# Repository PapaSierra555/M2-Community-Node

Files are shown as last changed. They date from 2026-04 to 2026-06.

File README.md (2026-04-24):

# M2 Community Node

Field-portable communications node in an 8U 10" mini-rack. Dual Raspberry Pi 5 16GB. All hardware, all open source, all yours.

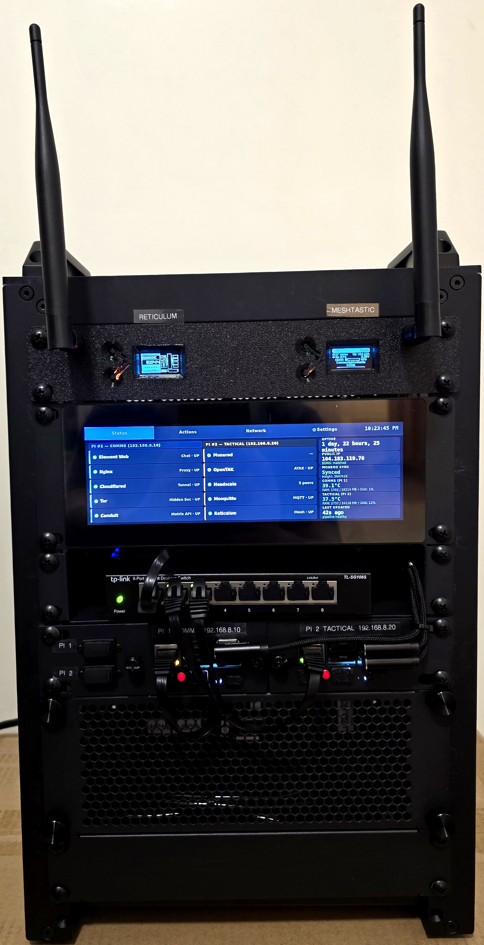
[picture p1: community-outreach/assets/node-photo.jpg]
M2 Community Node


**License:** [CC BY-NC-SA 4.0](LICENSE) — free to use, adapt, and share non-commercially with attribution.

**Network diagram:** [`docs/M2_Network_Diagram.drawio`](docs/M2_Network_Diagram.drawio) — renders on GitHub · open in [app.diagrams.net](https://app.diagrams.net) to edit or print

---

> ## Before You Start — Read This
>
> **This repository is a build plan, not a plug-and-play installer.** It is a complete, step-by-step blueprint for constructing and configuring a field-portable community communications node from commodity hardware. Prior hardware or networking expertise is NOT a hard requirement — but only if you go in with realistic expectations and the right support.
>
> **This node was built successfully with the help of an AI companion (Claude) assisting at every step** — walking through commands, catching configuration errors, explaining tradeoffs, and adapting to the specific hardware and environment as it came up. That approach is **strongly recommended** for anyone attempting this build. The build guide contains every command and every config, but this is a complex, multi-service system and the reality of standing it up involves:
>
> - Configuration decisions that depend on your specific domain, hardware, and use case
> - Gotchas in third-party software (OpenTAKServer, Conduit, Headscale) that are not documented upstream
> - Network and firewall behaviors that vary by router model and ISP
> - Security choices around access tiers, credentials, and certificate management that require deliberate decisions
> - Unexpected states during setup that require diagnosis, not just copy-paste
>
> **The recommendation:** Work through the build guide with an AI assistant — Claude, ChatGPT, or similar — that can read the docs alongside you, adapt commands to your environment on the fly, and help you reason through the decisions. This is not a project where you follow the guide blindly and expect it to work. It is a project where you follow the guide with a knowledgeable collaborator and build something that actually fits your community.
>
---

## What It Does

A self-contained tactical and community communications hub that fits in a shoebox-sized rack and deploys in under 15 minutes:

- **ATAK / OpenTAK Server** — shared tactical map, CoT, GeoChat, voice (Mumble)
- **Matrix / Element** — encrypted group chat with federation
- **Meshtastic** — LoRa mesh radio (1–5 km, no internet needed)
- **Reticulum / RNode** — encrypted mesh transport backbone
- **Monero** — community privacy node
- **Tor + I2P** — censorship-resistant access paths
- **Headscale** — self-hosted VPN for remote operator access
- **Offline Maps** — PMTiles street-level maps + DTED2 terrain data

**Cost:** ~$994 (recommended build) | ~$889 (budget, single Pi) | [See all build options →](docs/BUILD_OPTIONS.md)

---

## Repository Layout

```
M2-Community-Node/
├── docs/               ← EVERYTHING YOU NEED TO BUILD IS IN HERE (including network diagram)
├── operational-pdfs/   Print-ready operational documents (build guide, runbook, field cards)
├── community-outreach/ Community marketing package (booth handouts, recruiting materials)
├── scripts/            PDF generators, QR tools, status bot, deploy scripts
├── config/             Service config templates (Conduit, Nginx, Tor, I2P, etc.)
├── svg/                Generic QR code SVGs (app downloads, LAN Element)
├── 3d-models/          STL files for 3D-printed rack accessories
├── kiosk-assets/       Offline map libraries for the kiosk display
├── docker-compose.yml          Pi #1 (comms) service stack
└── docker-compose.tactical.yml Pi #2 (tactical) service stack
```

---

> **The `docs/` folder is the build.** Every phase, every command, every config decision lives there. The hardware BOM, the step-by-step build guide, the event runbook, troubleshooting — all of it. If you are building a node, open `docs/` and start with `PREREQUISITES.md`. Do not skip it.

---

### docs/

All reference documentation. Read in this order if you're building:

| Document | What it covers |
|---|---|
| [PREREQUISITES.md](docs/PREREQUISITES.md) | What you need before you start |
| [HARDWARE_BOM.md](docs/HARDWARE_BOM.md) | Complete BOM — every part, ASIN, and price |
| [BUILD_OPTIONS.md](docs/BUILD_OPTIONS.md) | Hardware alternatives — Pi 4, mini PCs, single-device, no-Monero builds |
| [MASTER_PLAN.md](docs/MASTER_PLAN.md) | Architecture, service inventory, network layout |
| [M2_Network_Diagram.drawio](docs/M2_Network_Diagram.drawio) | Full network diagram — all services, ports, connectivity paths |
| [BUILD_GUIDE.md](docs/BUILD_GUIDE.md) | **Main build guide — 13 phases, every command** |
| [ATAK_CONNECTIVITY.md](docs/ATAK_CONNECTIVITY.md) | Operator onboarding — 3 access tiers (LAN, clearnet, VPN) |
| [EVENT_RUNBOOK.md](docs/EVENT_RUNBOOK.md) | Day-of-event: power-on, POST, onboarding, teardown |
| [ATAK_SAR_PLUGINS.md](docs/ATAK_SAR_PLUGINS.md) | ATAK plugin audit and SAR recommendations |
| [ATAK_RETICULUM_MESH.md](docs/ATAK_RETICULUM_MESH.md) | Mesh layer deep dive (OTS + Reticulum + Meshtastic) |
| [ELEMENT_PLAN.md](docs/ELEMENT_PLAN.md) | Matrix / Element space planning and federation |
| [MONERO_NODE.md](docs/MONERO_NODE.md) | Monero node installation and operation |
| [SERVICE_MAP.md](docs/SERVICE_MAP.md) | Port map and network layout quick reference |
| [TROUBLESHOOTING.md](docs/TROUBLESHOOTING.md) | Symptom-based field reference — WiFi, ATAK, Matrix, Monero |
| [NETWORK_CUSTOMIZATION.md](docs/NETWORK_CUSTOMIZATION.md) | Changing subnets, DHCP, and firewall rules |
| [CLOUDFLARE_SETUP.md](docs/CLOUDFLARE_SETUP.md) | DNS and tunnel setup for clearnet access |
| [DISASTER_RECOVERY.md](docs/DISASTER_RECOVERY.md) | Backup, restore, and failover procedures |
| [QR_CODES.md](docs/QR_CODES.md) | QR code generation and deployment workflow |
| [FIELD_LAPTOP_SETUP.md](docs/FIELD_LAPTOP_SETUP.md) | Operator laptop config for remote field use |
| [MAINTENANCE.md](docs/MAINTENANCE.md) | Service updates, version management, credential rotation |

### operational-pdfs/

Print-ready documents for building and operating the node. Generated from the source docs — regenerate after any doc change by running the corresponding script from `scripts/`.

| PDF | Description | Regenerate with |
|---|---|---|
| `M2_Community_Node_Build_Book.pdf` | Full build guide — print for the workbench | `generate_build_book.py` |
| `M2_Community_Node_Runbook.pdf` | Event operations runbook | `generate_runbook.py` |
| `M2_Community_Node_Troubleshooting.pdf` | Field troubleshooting reference | `generate_reference_pdfs.py` |
| `M2_Rack_Wiring_Diagram.pdf` | Cable routing and power chain diagrams | `generate_m2_wiring_diagram.py` |
| `M2_ATAK_FieldCard.pdf` | 3.5×5.5" laminated ATAK setup card | `generate_field_card.py` |

### community-outreach/

Marketing and recruiting materials for events and community engagement. These are not build documentation — they are handouts for people who haven't built a node yet. Live in `community-outreach/pdf/`, generated by scripts in `community-outreach/scripts/`.

| PDF | Description |
|---|---|
| `M2_Snapshot.pdf` | 2-page booth handout — services, capabilities, cost |
| `M2_Build_Summary.pdf` | BOM summary, cost tiers, build timeline |
| `M2_PACE_Card.pdf` | PACE framework reference card |
| `M2_New_Member_Card.pdf` | 3.5×5.5" laminated new member onboarding card |

### scripts/

PDF generators, operations tools, and deploy scripts.

| Script | What it does |
|---|---|
| `generate_build_book.py` | Build Book PDF from `docs/BUILD_GUIDE.md` |
| `generate_runbook.py` | Runbook PDF from `docs/EVENT_RUNBOOK.md` |
| `generate_reference_pdfs.py` | Troubleshooting PDF from `docs/TROUBLESHOOTING.md` |
| `generate_m2_wiring_diagram.py` | Rack wiring diagram PDF |
| `generate_field_card.py` | ATAK field card PDF (3.5×5.5") |
| `generate_qr.py` | QR code SVGs — WiFi, app downloads, onion services |
| `generate_vinyl_labels.py` | Vinyl cut labels for rack panels |
| `generate-status.py` | Live service status page renderer |
| `m2-status-bot.sh` | Status bot launcher (systemd timer, posts to Matrix) |
| `m2-post-matrix.py` | Post a message to a Matrix room |
| `m2-event-space.py` | Manage Matrix event spaces for activations |
| `make_atak_dp.py` | Build an ATAK data package for quick enrollment |
| `push_node_marker.py` | Push node GPS marker to OpenTAK Server |
| `set_node_icon.py` | Set the node icon in OpenTAK Server |
| `instance_config.py` | Instance config loader (reads `instance.conf`) |
| `systemd/` | Systemd service and timer units for the status bot |

### config/

Service configuration templates. Copy each to its final location on the Pi before deploying — do not fill in secrets here.

| Path | Service |
|---|---|
| `config/conduit/conduit.template.toml` | Conduit Matrix homeserver |
| `config/element/element-config.json` | Element Web client |
| `config/nginx/nginx.conf` | Reverse proxy |
| `config/tor/torrc` | Tor daemon |
| `config/i2pd/i2pd.conf` | I2P daemon |
| `config/mosquitto/mosquitto.conf` | MQTT broker (Meshtastic bridge) |

### svg/

QR code SVGs for printed materials and kiosk modals. Two workflows — see [docs/QR_CODES.md](docs/QR_CODES.md).

- `qr-wifi.svg`, `qr-atak-connect.svg`, `qr-community-page.svg`, `qr-element-clearnet.svg` — physical panel vinyl cutouts
- Remaining QRs — kiosk modal use only
- `WebQrCodes/` — vinyl-quality QR set (generated via mini-qr)

### 3d-models/

STL files for 3D-printed rack accessories. Print in PETG or ABS.

- SMA bulkhead / Keystone mount for 1U panel (left + right versions)
- 2U fan side plates
- Heltec V3 LoRa radio faceplate
- RFID module housing (top + bottom)
- Meshtastic 10" rack panel model

---

## Quick Start

**Everything below points into `docs/`. That folder is where the build lives.**

### 1. Get the hardware

[docs/HARDWARE_BOM.md](docs/HARDWARE_BOM.md) — complete parts list with prices and purchase links.

### 2. Read the prerequisites

[docs/PREREQUISITES.md](docs/PREREQUISITES.md) — accounts, tools, and decisions to make before touching hardware. Do this first.

### 3. Follow the build guide

[docs/BUILD_GUIDE.md](docs/BUILD_GUIDE.md) — every command, every config, from bare hardware to a running node. This is the primary document.

### 4. Set up credentials

Copy `M2_SECRETS.template.md` to `M2_SECRETS.md` and fill in your values. The filled file is gitignored — never commit it.

Copy `instance.conf.template` to `instance.conf` and fill in your network-specific values.

Copy `kiosk-config.js.template` to `kiosk-config.js` and fill in your OTS credentials before deploying the kiosk.

### 5. Deploy the kiosk

Copy `kiosk.html`, `index.html`, `kiosk-map.html`, `kiosk-assets/`, and your filled `kiosk-config.js` to `/home/pi/node-ui/` on Pi #1.

---

## Contributing

This project is documentation and tooling, not application code. If you build one and find errors, improvements, or gotchas — open an issue or PR. All contributions must be compatible with CC BY-NC-SA 4.0.

Questions or feedback: open an issue on GitHub.

---

## Special Thanks

This project would not exist without the vision, community, and mission of three organizations that helped build the idea, necessity, and reasoning behind it:

- **[Carolina Capabilities Co-Op](https://www.carolinacapabilitiesco-op.com/)** — community resilience and preparedness, built from the ground up
- **[Light Fighter Manifesto](https://lightfightermanifesto.org/)** — the framework and philosophy driving the mission
- **[Light Fighter Homefront Initiative](https://lightfighterhomefront.org/)** — putting that mission into practice at the community level

The inspiration and architecture for this project couldn't have been done without the first iteration built by **Christopher M. Rance**. Go support the group or join a chapter — [instagram.com/christopher_m_rance](https://www.instagram.com/christopher_m_rance/)

---

## License

[Creative Commons Attribution-NonCommercial-ShareAlike 4.0 International](LICENSE)

You can build one for your community. You cannot sell it. If you publish your own version, use the same license.

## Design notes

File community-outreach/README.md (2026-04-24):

# M2 Community Node — Outreach Materials

Print-ready materials for introducing the M2 Community Node at events, chapter meetings, and mutual aid gatherings. All materials are CC BY-NC-SA 4.0.

---

## Documents

| File | Format | Purpose |
|---|---|---|
| `M2_Snapshot.pdf` | US Letter, 2 pages | Node overview — services, capabilities, hardware specs, deployment scenarios |
| `M2_PACE_Card.pdf` | US Letter, 1 page | PACE framework reference — which M2 service maps to each comms tier |
| `M2_Build_Summary.pdf` | US Letter, 1 page | Build cost tiers, BOM summary, skills required |
| `M2_New_Member_Card.pdf` | 3.5×5.5 in, 2 sides | Laminated onboarding card — WiFi credentials, connection methods, quick reference |

---

## Regenerating PDFs

All PDFs are generated from Python scripts in `scripts/`. Requirements: `reportlab`, `qrcode`.

```
pip install reportlab qrcode[pil]
```

Run all:
```
cd community-outreach/scripts
python generate_m2_snapshot.py
python generate_pace_card.py
python generate_build_summary.py
python generate_new_member_card.py
```

Output lands in `community-outreach/pdf/`.

---

## Assets

Photos and logos used by the generation scripts are in `assets/`:

| File | Use |
|---|---|
| `node-photo.jpg` | Hero shot — used in README and outreach materials |
| `node-ccc.jpg`, `node-detail-1.jpg`, `node-detail-2.jpg`, `node-side.jpg`, `node-top.jpg` | Detail photos for snapshot and summary |
| `lfhi-logo.png` | LFHI partner badge |

---

## Target Audience

**Primary:** Community preparedness groups, SAR teams, neighborhood mutual aid, and emergency response organizations evaluating off-grid comms on the PACE framework.

**Secondary:** Builders evaluating whether the M2 platform fits their technical capability and budget.

---

## Printing Notes

- `M2_New_Member_Card.pdf` — print duplex on card stock (3.5×5.5 in), laminate. Fits standard business card holders. Hand out at events.
- All other docs — US Letter, single-sided. Print in color for maximum impact.
- For vinyl panel labels and QR cutouts, see `svg/` directory and `docs/QR_CODES.md`.

---

*CC BY-NC-SA 4.0*

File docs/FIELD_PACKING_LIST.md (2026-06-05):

# M2 Community Node — Field Maintenance & Repair Kit

What to bring for field deployment. Covers the full node stack: rack,
Meshtastic fleet, field laptop, and repair/recovery gear.

---

## Node Rack — Deploy Checklist

- [ ] Comms Pi (192.168.8.10) — verify label
- [ ] Tactical Pi (192.168.8.20) — verify label
- [ ] Router
- [ ] NVMe drive — seated in tactical Pi, verify before pack
- [ ] Kiosk display + mount hardware
- [ ] Micro-HDMI to HDMI cable (comms Pi 5 → display) — braided, not flat
- [ ] Rack enclosure / case / carry bag

---

## Power

- [ ] Pi power supply x2 (labeled, one per Pi)
- [ ] Router power supply
- [ ] Display power supply / adapter
- [ ] Power strip (4+ outlets)
- [ ] Extension cord
- [ ] **SPARE: Pi power supply x1** — most common single-point failure

---

## Network

- [ ] Router WAN uplink — hotspot or ethernet
- [ ] Ethernet patch cables x4 (Pi #1, Pi #2, laptop, spare)
- [ ] **SPARE: Ethernet cable x2**

---

## Meshtastic Fleet

- [ ] T114 x8 — MESH 01–08 (verify labels)
- [ ] T3S3 x3 — PS-01, PS-02, PS-03
- [ ] USB-C charging cables x4
- [ ] USB serial cable — T114 (for re-flash / reconfigure)
- [ ] USB serial cable — T3S3 (for re-flash / reconfigure)
- [ ] Power bank x1

---

## Field Laptop

- [ ] Getac S400 G2 + power supply
- [ ] SSH access to both Pis confirmed before departure

---

## Print Materials

- [ ] Element join cards (cut + laminated)
- [ ] Meshtastic channel QR cards (cut + laminated)
- [ ] Meshtastic device cards front + back (cut + laminated, duplex)
- [ ] **SPARE: 2 extra sets of each** — cards walk, get wet, get lost

---

## Tools

- [ ] Small Phillips screwdriver
- [ ] Small flathead screwdriver
- [ ] Needle-nose pliers
- [ ] Multimeter (power supply and cable fault diagnosis)
- [ ] USB hub (run serial + keyboard simultaneously on one Pi port)
- [ ] Zip ties x20
- [ ] Velcro straps x6
- [ ] Electrical tape
- [ ] Masking tape + marker (relabeling, field notes)

---

## Spare Parts / Recovery

| Part | Failure it covers |
|---|---|
| Spare Pi x1 (either model) | Dead Pi — reimage and reconfigure as either stack |
| Spare microSD x2 (Pi OS imaged, 32GB+) | Corrupted OS — swap and restore |
| USB microSD reader | Writing replacement SD on the field laptop |
| Spare USB-C cable x2 | Charging failure for Meshtastic devices |
| Spare ethernet cable x2 | Cable fault, wrong length |
| Spare Pi power supply x1 | Pi won't boot — PSU is first suspect |

---

## Recovery Procedures (quick reference)

**Pi won't boot → swap SD card:**
1. Pull SD, insert spare (pre-imaged)
2. Boot into new OS, restore from backup or re-run setup
3. Repo + configs on field laptop: `~/SOURCE CONTROL/M2-Community-Node`

**Pi fully dead → hot-swap spare:**
1. Label spare with correct Pi number before inserting
2. Connect to LAN, SSH in, restore from repo
3. Comms stack: `sudo docker compose -f /opt/community-node/docker-compose.yml --profile clearnet up -d`
4. Tactical stack: `sudo docker compose -f /opt/tactical-node/docker-compose.yml up -d`
5. Headscale + OTS: `sudo systemctl start headscale opentakserver`

**Meshtastic device won't connect → reconfigure via serial:**
```
python3 meshtastic/scripts/config_ccc_t114.py   # T114 devices
python3 meshtastic/scripts/config_ccc_t3s3.py   # T3S3 devices
```
Run from project root on field laptop. Plug device via USB serial first.

**Dashboard shows red after boot → wait 2 minutes then check:**
```
ssh ps@192.168.8.10 "sudo docker ps --format 'table {{.Names}}\t{{.Status}}'"
ssh ps@192.168.8.20 "sudo systemctl is-active headscale && sudo systemctl is-active opentakserver"
```
Full boot verification: `docs/POWER_CYCLE.md`

**Mosquitto crash-looping:**
```
ssh ps@192.168.8.20 "sudo docker restart tactical-node-mosquitto-1"
```
If it keeps looping: check `/opt/tactical-node/config/mosquitto/mosquitto.conf` — must have `allow_anonymous true`, no `password_file` line.

---

*Full power cycle procedure: `docs/POWER_CYCLE.md`*
*Credentials: M2_SECRETS.md on field laptop (pull from Obsidian z_Backups/ before departure)*

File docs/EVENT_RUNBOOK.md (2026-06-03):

# M2 Community Node — Day-of-Event Runbook

**For the tech running the node at a SAR operation, community event, or training exercise.**

This document assumes the node has already been built and configured per `BUILD_GUIDE.md`. You do not need to read the build guide to use this runbook.

---

## Power-On Sequence

Order matters. Power on in this sequence:

1. **UPS** (BC600R) — press power button, confirm LED is green
2. **GL.iNet router** (AXT1800) — power on, wait **60 seconds** before touching anything
3. **TL-SG105 switches** — power on (no boot time)
4. **Pi #1 (comms, 192.168.8.10)** — power on
5. **Pi #2 (tactical, 192.168.8.20)** — power on
6. Wait **90 seconds** for both Pis to fully boot and services to start
7. **Kiosk touchscreen** — power on last

**Total boot time: ~3 minutes.** Do not test connectivity during this window.

---

## POST — Power-On Self-Test

After the 90-second boot window, run this check from any device on the `NodeAdmin` WiFi:

### Quick check (30 seconds)

Open a browser and hit these URLs. All should load:

| URL | Expected | Service |
|---|---|---|
| `http://192.168.8.1` | GL.iNet admin panel | Router |
| `http://192.168.8.10:8081` | Community info page | Kiosk web |
| `http://192.168.8.10:8080` | Element Web login | Matrix chat |
| `http://192.168.8.20:8080` | OTS web map | OpenTAK Server |

If all four load: **node is go.**

### Full POST (SSH, 2 minutes)

Run this on your laptop if the quick check fails or you want full confidence:

```
[SSH — comms-lan]
docker ps --format "table {{.Names}}\t{{.Status}}"
```

Expected output (all containers `Up`):
```
community-node-nginx-1         Up X hours
community-node-cloudflared-1   Up X hours
community-node-element-web-1   Up X hours (healthy)
community-node-tor-1           Up X hours (healthy)
community-node-i2pd-1          Up X hours
community-node-conduit-1       Up X hours
```

```
[SSH — tactical-lan]
systemctl is-active opentakserver cot_parser headscale && docker ps --format "table {{.Names}}\t{{.Status}}"
```

Expected: `active` (three times), then containers:
```
tactical-node-monerod-1     Up X hours (healthy)
tactical-node-nomadnet-1    Up X hours
tactical-node-reticulum-1   Up X hours
tactical-node-mosquitto-1   Up X hours
```

> Note: Headscale runs as a systemd service (`headscale.service`), not Docker. Verify with `systemctl is-active headscale`.

---

## Pre-Event Checklist (30 minutes before go-live)

- [ ] All POST checks pass
- [ ] Kiosk map is live and showing the Community Node marker at correct location
- [ ] Connect a test phone to `CommunityNode` WiFi, open ATAK, confirm it connects to `192.168.8.20:8089`
- [ ] Test phone icon appears on OTS web map at `http://192.168.8.20:8080`
- [ ] GeoChat test: send a message from the test phone, confirm it appears in OTS
- [ ] Mumla voice test: open Mumla → `192.168.8.20` port `64738` → confirm connection
- [ ] Field cards printed and on hand (or QR codes available on kiosk)
- [ ] If running structured SAR: pre-build an ExCheck checklist template in ATAK and distribute via OTS data package before go-live
- [ ] WiFi password posted/available for incoming team members

---

## Onboarding Arriving Team Members

**Path A — Local WiFi (everyone physically here):**

1. Connect phone to `CommunityNode` WiFi
2. Open ATAK → Menu → Import → QR Code
3. Scan the QR code from the kiosk or from OTS Web UI (Certificates → Generate Data Package → Show QR Code)
4. Set callsign: Settings → My Preferences → Callsign
5. Verify icon on map. Done. **~3 minutes.**

**Path B — Remote viewer (off-site, browser only):**

1. Add their email to Cloudflare Access: `dash.cloudflare.com` → Zero Trust → Access → Applications → OTS Web Map → Edit → add email → Save
2. Send them: `https://tak.yourdomain.com`
3. They enter email, get 6-digit OTP, see live map. **~60 seconds.**

**Path C — Remote ATAK (trusted operator, full participation):**

```
[SSH — tactical-lan]
sudo headscale preauthkeys create -c /opt/tactical-node/config/headscale/config.yaml --user 2 --expiration 24h
```

Send them the key + `https://m2vpn.capableenough.org` + ATAK server `192.168.8.20:8089`.

---

## Pre-Event: Matrix Event Space Setup (1 week before)

Run from the field laptop (m2-field) or any machine on NodeAdmin WiFi with the repo checked out.

**Requires:** m2bot access token from `M2_SECRETS.md` → Matrix section → Bot password. Get the token by logging in as m2bot via the Matrix API or Element.

**Step 1 — Create the space and rooms:**

```
[m2-field or Windows dev machine]
cd ~/SOURCE\ CONTROL/M2-Community-Node
python3 scripts/m2-event-space.py create --event "CCC26" \
  --bot-token <m2bot-token> \
  --invite @YOUR_ADMIN_ACCOUNT:matrix.org
```

Output lists 6 room aliases (1 space + 5 rooms). State saved to `/tmp/m2-event-space-state.json` — do not delete this file until after teardown.

**Step 2 — Accept invites:**

Open Element at `https://communitynode.yourdomain.com`, log in as `@YOUR_ADMIN_ACCOUNT:matrix.org`, accept all 6 invites.

**Step 3 — Promote admin:**

```
python3 scripts/m2-event-space.py promote \
  --bot-token <m2bot-token> \
  --invite @YOUR_ADMIN_ACCOUNT:matrix.org
```

Sets PL 100 in all rooms. Verify in Element: room Settings → Roles & Permissions → @YOUR_ADMIN_ACCOUNT should show Admin.

**Step 4 — Test:**

- Send a message in each room
- Confirm encryption lock icon is present
- Confirm status bot is posting to `#m2-ops` (fires every 12h — check if one is due or post manually via `sudo systemctl start m2-status-bot.service`)

**Rooms created:**

| Alias | Purpose |
|---|---|
| `#m2-ccc26:m2.yourdomain.com` | Space container |
| `#m2-ccc26-general:m2.yourdomain.com` | General coordination |
| `#m2-ccc26-ops:m2.yourdomain.com` | Ops / logistics |
| `#m2-ccc26-field:m2.yourdomain.com` | Field team comms |
| `#m2-ccc26-sar:m2.yourdomain.com` | SAR / emergency |
| `#m2-ccc26-atak:m2.yourdomain.com` | ATAK coordination |

All rooms: private, invite-only, E2E encrypted, room version 10.

---

## During the Event

### Kiosk status tab
The kiosk dashboard (touchscreen at rack U6) shows live service status. Green = healthy. If anything goes red, see troubleshooting below.

### If ATAK positions stop updating

```
[SSH — tactical-lan]
systemctl status cot_parser
sudo systemctl restart cot_parser
```

Wait 15 seconds, confirm positions resume on the map.

### If a user can't connect to ATAK

Common causes:
1. **SSL checkbox** — in ATAK server settings, "Use default SSL/TLS Certificates" must be **unchecked**. Delete the server entry and re-add with it unchecked.
2. **Wrong WiFi** — confirm they're on `CommunityNode`, not a personal hotspot
3. **Certificate enrollment** — if connecting manually (not QR), port 8446 must be reachable. Confirm OTS is running.

### If Element/Matrix is down

```
[SSH — comms-lan]
docker restart community-node-conduit-1
docker restart community-node-nginx-1
```

Wait 30 seconds, refresh Element Web.

### If the kiosk screen is blank

Touch the screen to wake. If still blank after 10 seconds, the screensaver is active — touch again. If Chromium has crashed, SSH in:

```
[SSH — comms-lan]
sudo reboot
```

Do NOT pkill Chromium from SSH — it won't relaunch automatically.

---

## Teardown / Pack-Up

**Shut down in reverse order: Pis first, then power.**

**Step 0: Tear down Matrix event space**

```
[m2-field or Windows dev machine]
python3 scripts/m2-event-space.py destroy --bot-token <m2bot-token>
```

Tombstones all 6 rooms and leaves. Room history persists in Conduit DB for the record — members can still read history but the rooms are archived. Kick remaining members if you want to fully vacate.

**Step 1: Graceful Pi shutdown**

```
[SSH — comms-lan]
sudo shutdown -h now
```

Wait 15 seconds, then:

```
[SSH — tactical-lan]
sudo shutdown -h now
```

Wait for SSH to disconnect (Pi has powered off). Do NOT pull power while SSH is still connected.

**Step 2: Power down**

1. Kiosk screen — power off
2. Switches — power off
3. GL.iNet router — power off
4. UPS — hold power button until LED goes out

**Step 3: Pack-up notes**
- LoRa antennas: coil gently, no tight bends
- USB cables: do not yank — grip the connector, not the cable
- Monero sync state is preserved on NVMe — no action needed
- Tor keys are preserved at `/opt/community-node/data/tor/` — no action needed
- Element config and message history persists on NVMe — no action needed

---

## Emergency: Internet Lost Mid-Event

Local WiFi ATAK, Matrix chat, and Meshtastic all continue working with no internet. Nothing to do.

Services that stop working: `tak.yourdomain.com` (remote viewers), `communitynode.yourdomain.com`, Headscale enrollment.

If you want to cut outbound traffic intentionally (air-gap):

```
[SSH — comms-lan]
docker stop community-node-cloudflared-1
```

```
[SSH — tactical-lan]
docker stop tactical-node-headscale-1
```

This isolates the node to LAN-only. Reverse with `docker start` when ready to reconnect.

---

## Emergency: A Pi Won't Boot

If a Pi is completely unresponsive after full boot window:

1. Check power LED on the Pi (solid red = power OK, green = activity)
2. Check ethernet LED on switch port (should blink)
3. If no lights: check USB-C cable and Anker power supply output
4. If lights OK but SSH unreachable: connect HDMI monitor to Pi, check boot messages
5. If SD card corruption suspected: re-flash SD from a backup image

**If Pi #1 (comms) is down:** ATAK and Monero still work. Matrix/Element is unavailable. Meshtastic still works.

**If Pi #2 (tactical) is down:** ATAK is unavailable. Matrix/Element still works for coordination.

---

## Quick Reference

| Service | URL / Address | Notes |
|---|---|---|
| Router admin | `http://192.168.8.1` | NodeAdmin WiFi only |
| Community page | `http://192.168.8.10:8081` | QR codes, app links |
| Element Web | `http://192.168.8.10:8080` | Matrix chat |
| OTS web map (LAN) | `http://192.168.8.20:8080` | Admin login |
| OTS web map (clearnet) | `https://tak.yourdomain.com` | Email OTP required |
| ATAK server | `192.168.8.20:8089` | SSL, uncheck default certs |
| Mumble voice | `192.168.8.20:64738` | Mumla app |

---

v1.0

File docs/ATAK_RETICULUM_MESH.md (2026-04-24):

# Mission 2 -- ATAK Server + Reticulum Mesh Networking + Tactical Communications

> **Platform:** Raspberry Pi 5 16GB -- Portable Community Node
> **Goal:** Deploy a self-contained tactical communications hub with situational awareness (ATAK), encrypted mesh networking (Reticulum), off-grid radio (LoRa), and secure VPN overlay (Tailscale/Headscale).
> **All software is open-source.**

---

## Table of Contents

1. [OpenTAK Server (OTS)](#1-opentakserver-ots)
2. [Reticulum Network Stack](#2-reticulum-network-stack)
3. [LoRa Radio Integration (Off-Grid Mesh)](#3-lora-radio-integration-off-grid-mesh)
4. [Tailscale Mesh VPN](#4-tailscale-mesh-vpn)
5. [Meshtastic Integration](#5-meshtastic-integration)
6. [Docker Compose Stack](#6-docker-compose-stack)
7. [Hardware Add-ons BOM](#7-hardware-add-ons-bom)
8. [Integration Architecture](#8-integration-architecture)

---

## 1. OpenTAK Server (OTS)

### 1.1 What is OpenTAKServer?

OpenTAKServer (OTS) is an open-source TAK (Team Awareness Kit) server providing the server-side infrastructure for ATAK (Android Team Awareness Kit), WinTAK, and iTAK clients. It enables shared situational awareness through Cursor on Target (CoT) data exchange, with a built-in React web UI featuring a live Leaflet map, MIL-STD-2525C symbology, certificate auto-generation, and native Meshtastic gateway support.

- **Repository:** `github.com/brian7704/OpenTAKServer`
- **Website:** `opentakserver.io`
- **Current Version:** v1.7.9
- **License:** GPL-3.0

### 1.2 Core Features

| Feature | Description |
|---|---|
| **CoT Streaming** | Real-time Cursor-on-Target data exchange (position, markers, routes) |
| **React Web UI** | Built-in browser-based admin with live Leaflet map and MIL-STD-2525C symbology |
| **Certificate Management** | Auto-generation of client/server certificates — no manual PKI workflow |
| **Geo-Chat** | Text messaging between all connected TAK clients |
| **Data Packages** | File sharing (maps, overlays, mission data) between clients |
| **Mission API** | Server-side mission management (ExCheck checklists, data sync) |
| **Meshtastic Gateway** | Built-in serial bridge — mesh nodes appear on web map |
| **Mumble Integration** | Built-in Mumble auth for push-to-talk voice via Mumla app |
| **Video Streaming** | MediaMTX integration for H.265/AV1 video feeds |
| **SSL/TLS** | Encrypted client-server connections with auto-generated certificates |
| **Offline Maps** | PMTiles served via built-in nginx — street-level maps with zero extra processes |

### 1.3 Default Ports

| Port | Protocol | Purpose |
|---|---|---|
| 8088 | TCP | CoT Streaming (client connections) |
| 8089 | TCP | CoT Streaming over TLS (encrypted) |
| 8080 | TCP | Web UI (HTTP) |
| 8443 | TCP | Web UI (HTTPS) |
| 8446 | TCP | Certificate enrollment |

### 1.4 Resource Requirements on Raspberry Pi 5

| Resource | Minimum | Recommended |
|---|---|---|
| RAM | 300 MB (OTS) + 200 MB (RabbitMQ) | 600 MB + 256 MB |
| Storage | 2 GB | ~4 GB (with FL PMTiles + DTED2 + data packages) |
| CPU | 1 core | 2 cores |
| Network | Any IP connectivity | Static IP or DHCP reservation |

OTS runs natively under systemd on the Pi 5 — no Docker container overhead. RabbitMQ runs alongside for message queuing. Total footprint is ~500-800 MB RAM typical.

### 1.5 Client Connectivity

- **ATAK (Android):** Free on Google Play. Connect to OTS IP:8088 (TCP) or IP:8089 (TLS). Certificate enrollment at IP:8446. Supports plugins.
- **WinTAK (Windows):** Available from tak.gov (free registration required). Same CoT protocol.
- **iTAK (iOS):** Connects via TAK server; can receive forwarded Meshtastic PLI via server relay.
- **Web UI:** Built-in React web UI at IP:8080 — live Leaflet map, no client install needed. Map shows connected clients only — create a static marker via `POST /api/markers` at install time so the kiosk map always shows the node's location (see Build Guide Phase 5B, Step 11).

### 1.6 ATAK/OTS Plugin Inventory

#### Tier 1 — Deploy Now (Core M2 Capabilities)

| Plugin | Source | What | Server-side |
|---|---|---|---|
| **Meshtastic ATAK Plugin** | GitHub meshtastic/ATAK-Plugin (446 stars) | Bridges ATAK CoT over LoRa mesh — PLI, GeoChat, file transfer, voice memos | Optional |
| **OTS Meshtastic Gateway** | Built into OTS | Server-side mesh-to-TAK bridge — mesh nodes appear on web map | Yes |
| **OpenTAK ICU** | GitHub brian7704/OpenTAK_ICU | Video streaming H.265/AV1, audio, encryption, background | Yes (MediaMTX) |
| **DTED.org** | snstac/DTED.org | 30m terrain data via QR scan — elevation, LOS, slope analysis | No |
| **ATAK-Maps** | GitHub joshuafuller/ATAK-Maps (MIT) | MOBAC XML sources — USGS topo, satellite, OpenTopo for offline caching | No |
| **Mumla** (standalone app) | [Play Store](https://play.google.com/store/apps/details?id=se.lublin.mumla) | Push-to-talk voice via Mumble server | Yes (Mumble) |

#### Tier 2 — High Value, Easy Setup

| Plugin | Source | What | Server-side |
|---|---|---|---|
| **ATAK Weather Plugin** | GitHub Hellikandra/ATAK-Weather-Plugin (MIT) | Open-Meteo weather data, no API key | No |
| **TAKWatch / TAKWatch-IQ** | GitHub TDF-PL/TAKWatch (GPL-3.0) | Garmin smartwatch bridge — heart rate, nav, emergency panic button | No |
| **APRSTAK** | GitHub niccellular/aprstak (GPL-3.0) | APRS ham radio positions in ATAK (many SAR teams use APRS) | No |
| **ADSBCOT** | GitHub snstac/adsbcot (Apache-2.0) | Aircraft tracking — rescue helicopters, search aircraft on map | Gateway on Pi |
| **TAK-CAD** | GitHub raytheonbbn/tak-cad (GPL-3.0) | Computer-aided dispatch for multi-team SAR operations | No |
| **OpenAthena** | Play Store (free, closed source) | Drone photo geolocation via terrain raycast — pinpoint ground coords | No |
| **WiFi2COT** | GitHub niccellular/wifi2cot (GPL-3.0) | WiFi signal mapping — locate survivors' devices in disaster areas | No |

#### Tier 3 — Specialized / As-Needed

| Plugin | Source | What | Hardware Required |
|---|---|---|---|
| **UAS Tool** | CivTAK built-in plugin | DJI drone telemetry + video | DJI drone |
| **Kraken-to-TAK** | GitHub Krakenberry/Kraken-to-TAK | Radio direction finding on TAK map | KrakenSDR (~$300-500) |
| **INRCOT** | GitHub snstac/inrcot (Apache-2.0) | Garmin inReach satellite positions | inReach + subscription |
| **BobTAK** | GitHub sniporbob/BobTAK (MIT) | HF radio CoT bridge — true beyond-LOS fallback | HF radio setup |
| **PulseCOT** | GitHub snstac/pulsecot (Apache-2.0) | 911 dispatch data on TAK map | Internet |
| **HyteraTAK** | GitHub kortel-systems/hyteratak | Hytera DMR radio GPS positions on TAK | Hytera radios |
| **ZelloCOT** | GitHub snstac/zellocot (Apache-2.0) | Zello PTT user positions on TAK | Zello accounts |
| **AISCOT** | GitHub snstac/aiscot (Apache-2.0) | Maritime vessel tracking for coastal SAR | Optional AIS receiver |

#### Built-in ATAK Capabilities (No Plugins Needed)

- **Reporting:** 9-line MEDEVAC, CasEvac, SALUTE, SITREP — all built-in
- **SAR tools:** Track logging, drawing/markup, POI markers, geofencing/alerts
- **ExCheck:** Collaborative checklists (server-synced via OTS Mission API)
- **GeoChat:** Georeferenced text messaging
- **Image sharing:** Geotagged photos as data packages
- **Weather tools:** Wind/hazmat plume modeling (manual input)
- **Elevation profile:** Line-of-sight and slope analysis (requires DTED loaded)

### 1.7 Offline Maps & Terrain Data

#### PMTiles (Kiosk Offline Map)

Extract your region from Protomaps daily builds:
```
pmtiles extract "https://build.protomaps.com/YYYYMMDD.pmtiles" region.pmtiles --bbox=WEST,SOUTH,EAST,NORTH --maxzoom=14
```

Replace `WEST,SOUTH,EAST,NORTH` with the bounding box for your deployment area (decimal degrees). Use [bboxfinder.com](http://bboxfinder.com) to get coordinates for your region. Replace `region.pmtiles` with a descriptive filename.

- Source: Protomaps daily builds (free, no account, streams only needed tiles)
- z0-14 provides street-level detail; file size varies by region (roughly 300 MB–1 GB for a US state)
- Served by OTS nginx at `/tiles/region.pmtiles` as a static file with byte-range support
- Rendered in browser by protomaps-leaflet (dark theme) — zero server-side rendering
- Kiosk location picker uses this for fully offline map display
- Falls back to online OSM raster tiles if PMTiles file is missing

> PMTiles contains **vector** tiles (MVT format). ATAK requires **raster** tiles and cannot use PMTiles directly. ATAK users should pre-cache tiles on-device when connected to WiFi, or use the ATAK-Maps plugin with MOBAC XML sources.

#### DTED2 (Elevation/Terrain for ATAK)

- Source: CivTAK OneDrive — pre-packaged SRTM by US state (manual browser download)
  - US by regions: `https://1drv.ms/u/s!AovJpJOFK1Vbgc8rtrMIBH_oXiqmAA?e=LIVl95`
  - Backup: USGS EarthExplorer (free account, select DTED output format)
- Resolution: ~30m (SRTM 1 arc-second, equivalent to DTED2); file size varies by region (~1–2 GB per US state)
- ATAK auto-loads from `/sdcard/atak/DTED/` at launch
- Pre-load on devices before deployment (multi-GB over mesh is impractical)
- OTS can distribute via data packages for WiFi-connected devices

Total storage: approximately 1.5–3 GB for a typical US state (PMTiles + DTED2) on 1TB NVMe. Trivial.

### 1.8 Native Install (systemd — not Docker)

OTS runs natively under systemd on Raspberry Pi 5. The OTS Docker ARM64 image is alpha-quality; the native Pi installer is production-ready.

```bash
# Install OpenTAKServer via the official Pi installer
# See BUILD_GUIDE.md Phase 5B for full step-by-step instructions
# including nginx port config, RabbitMQ, Meshtastic, and Mumble setup
```

> **Important:** OTS is NOT in the Docker compose file. It runs as a systemd service alongside the Docker stack. Check status with `systemctl status opentakserver`.

---

## 2. Reticulum Network Stack

### 2.1 Overview

Reticulum is a cryptography-based networking stack created by Mark Qvist. It is designed for building resilient, encrypted, hardware-agnostic communication networks that work over any medium -- LoRa radio, packet radio, WiFi, serial links, TCP/IP, I2P, or anything else that can carry data.

- **Repository:** `github.com/markqvist/Reticulum`
- **Current Version:** 1.1.3
- **License:** MIT
- **Install:** `pip install rns`

### 2.2 Key Properties

- **End-to-end encrypted** by default (X25519 + AES-256 + HMAC-SHA256)
- **No IP addresses required** -- identity-based addressing using Ed25519 keys
- **Delay/disruption tolerant** -- messages queue and forward when links are available
- **Hardware agnostic** -- runs on any transport medium
- **Minimal resources** -- runs on microcontrollers through to servers
- **Self-configuring** -- auto-discovers peers on local networks

### 2.3 Reticulum Applications

#### NomadNet (Nomad Network)

Terminal-based communications platform over Reticulum:
- Text messaging (LXMF-based)
- Distributed bulletin board / page system (like BBS over mesh)
- Node hosting -- serve pages to other NomadNet users
- File sharing
- Install: `pip install nomadnet`
- Run as daemon: `nomadnet --daemon`

#### LXMF (Lightweight Extensible Message Format)

The messaging protocol built on Reticulum:
- Store-and-forward message delivery
- Works across any Reticulum transport
- Supports text, binary data, attachments
- Delay-tolerant -- messages propagate when routes become available
- Install: `pip install lxmf`

#### Sideband (Mobile Client)

Full-featured Reticulum client for Android, Linux, macOS, and Windows:
- Graphical messaging interface
- Voice messages, image sharing, file transfers
- Real-time voice calls over Reticulum
- Distributed telemetry system with mapping
- Plugin extensibility
- Android APK available from `github.com/markqvist/Sideband`
- Also available on F-Droid

#### MeshChat (Web-based Client)

- Web-based LXMF client by Liam Cottle
- User-friendly browser interface
- Image/voice messages, file transfers
- Repository: `github.com/liamcottle/reticulum-meshchat`

### 2.4 Reticulum Interfaces

Reticulum supports multiple simultaneous interfaces. A single node can bridge between all of them.

| Interface Type | Transport Medium | Use Case |
|---|---|---|
| `AutoInterface` | Local network (UDP broadcast) | Auto-peer with LAN devices |
| `TCPServerInterface` | TCP/IP | Accept connections from remote nodes |
| `TCPClientInterface` | TCP/IP | Connect to remote Reticulum nodes |
| `RNodeInterface` | LoRa radio (via RNode) | Off-grid radio mesh |
| `SerialInterface` | RS-232 / USB serial | Direct cable or packet radio TNC |
| `KISSInterface` | Serial KISS TNC | Packet radio (AX.25 compatible) |
| `I2PInterface` | I2P overlay network | Anonymous transport |
| `PipeInterface` | Unix pipes | Inter-process communication |

### 2.5 Reticulum Node Configuration on Pi 5

> **Note:** This configuration was valid as of Reticulum v1.1.3. Interface names, available transports, and configuration syntax may change between versions. Always verify interface availability and current syntax against the official documentation (`rnsd --exampleconfig`) before deploying. Check `github.com/markqvist/Reticulum` for the current stable release.

The configuration file lives at `~/.reticulum/config`. Below is a community node configuration:

```ini
# Reticulum Configuration for Community Node
# ~/.reticulum/config

[reticulum]
  enable_transport = True
  share_instance = True
  shared_instance_port = 37428
  instance_control_port = 37429
  panic_on_interface_error = No

[logging]
  loglevel = 4

[interfaces]
  # Auto-discover peers on local network
  [[Default Interface]]
    type = AutoInterface
    enabled = yes

  # Accept incoming TCP connections from remote Reticulum nodes
  [[TCP Server]]
    type = TCPServerInterface
    enabled = yes
    listen_ip = 0.0.0.0
    listen_port = 4242

  # Connect to a public Reticulum transport node
  [[RNS Testnet Frankfurt]]
    type = TCPClientInterface
    enabled = yes
    target_host = frankfurt.connect.reticulum.network
    target_port = 4965

  # LoRa radio interface via RNode USB transceiver
  [[RNode LoRa]]
    type = RNodeInterface
    enabled = no
    port = /dev/ttyUSB0
    frequency = 915000000
    bandwidth = 125000
    spreadingfactor = 8
    codingrate = 5
    txpower = 17
    flow_control = True

  # Serial interface for packet radio TNC
  [[Packet Radio]]
    type = KISSInterface
    enabled = no
    port = /dev/serial/by-id/usb-FTDI_FT230X-if00-port0
    speed = 115200
    databits = 8
    parity = none
    stopbits = 1
    preamble = 150
    txtail = 10
    persistence = 200
    slottime = 20
```

### 2.6 Running Reticulum

```bash
# Install Reticulum stack
pip install rns nomadnet lxmf

# Run Reticulum daemon (background transport node)
rnsd

# Run NomadNet (interactive terminal UI)
nomadnet

# Run NomadNet as daemon (headless page/message server)
nomadnet --daemon

# Check Reticulum status
rnstatus

# Probe a Reticulum destination
rnprobe <destination_hash>

# Transfer a file
rncp <source> <destination_hash>:/path
```

---

## 3. LoRa Radio Integration (Off-Grid Mesh)

### 3.1 RNode -- Open Source LoRa Transceiver

RNode is an open-source, open-hardware LoRa transceiver designed by Mark Qvist specifically for Reticulum. It turns commodity LoRa development boards into full-featured radio interfaces.

**Supported Hardware for RNode firmware:**
- LilyGO LoRa32 v2.1 (TTGO T3 v1.6.1) -- **recommended, ~$15-25**
- LilyGO T-Beam v1.1 (with GPS) -- ~$25-35
- Heltec LoRa32 v2/v3
- RAK4631-based boards
- Any board with SX1276, SX1278, SX1262, SX1268, or SX1280 chip

**Flashing RNode firmware:**
```bash
# Install the RNode configuration utility
pip install rnodeconf

# Flash firmware to a connected board
rnodeconf --autoinstall

# The utility auto-detects the board and flashes appropriate firmware
```

**Build vs Buy:**
- DIY: Flash firmware onto a ~$20 LilyGO T3 board
- Pre-built: Available from select vendors (unsigned.io referrals)
- DIY is recommended -- it takes under 10 minutes with `rnodeconf --autoinstall`

### 3.2 Compatible LoRa HATs for Raspberry Pi 5

For direct Pi 5 integration (SPI/UART attached):

| HAT | Chip | Freq | Pi 5 Compat | Price (est.) |
|-----|---|---|---|---|
| **Waveshare SX1262 LoRa HAT** | SX1262 | 915 MHz | Yes (UART) | ~$20-25 |
| **Waveshare SX1268 LoRa HAT** | SX1268 | 868 MHz | Yes (UART) | ~$20-25 |
| **RAK2245 Pi HAT** | SX1301 | 915/868 MHz | Check (SPI) | ~$70-90 |
| **Dragino LoRa/GPS HAT** | SX1276 | 915/868 MHz | Legacy (SPI) | ~$30-40 |

**Recommendation:** For Reticulum use, a USB-connected RNode (LilyGO T3) is preferred over a Pi HAT. It is better supported, easier to position (antenna placement flexibility via USB cable), and the RNode firmware is purpose-built for Reticulum.

### 3.3 Frequency Bands and Licensing

| Region | Band | Notes |
|---|---|---|
| **US (FCC)** | 915 MHz ISM | License-free, 1W max EIRP |
| **EU (ETSI)** | 868 MHz ISM | License-free, duty cycle limits |
| **US (Ham)** | 70cm (420-450 MHz) | Requires amateur radio license, higher power allowed |
| **US (Ham)** | 33cm (902-928 MHz) | Requires amateur radio license |

For community deployment in the US, 915 MHz ISM band is the practical choice -- no license required.

### 3.4 Range Expectations (Reticulum over LoRa)

| Scenario | Estimated Range |
|---|---|
| Urban (buildings, obstructions) | 1-3 km |
| Suburban | 3-8 km |
| Rural / clear terrain | 5-15 km |
| Elevated antenna (hilltop/tower) | 10-30+ km |
| Line of sight (mountain-to-mountain) | 30-80+ km |

Range depends heavily on antenna height, terrain, spreading factor, and bandwidth settings. Higher spreading factor = longer range but lower throughput.

**Typical Reticulum LoRa settings:**
- Bandwidth: 125 kHz
- Spreading Factor: 8 (SF8)
- Coding Rate: 4/5
- TX Power: 17 dBm (50 mW)
- Effective bitrate: ~3.1 kbps (adequate for text messaging and CoT data)

### 3.5 Meshtastic vs Reticulum over LoRa

These are **separate systems** that can coexist on different hardware:

| Aspect | Reticulum + RNode | Meshtastic |
|---|---|---|
| **Purpose** | General encrypted mesh networking | Consumer-friendly LoRa mesh messaging |
| **Encryption** | X25519 + AES-256 (per-identity) | AES-256 (channel-based PSK) |
| **Protocol** | LXMF over Reticulum | Meshtastic protobuf |
| **ATAK Support** | Not direct (separate systems) | Native ATAK plugin |
| **Complexity** | Higher (more capable) | Lower (easier setup) |
| **Recommended Use** | Primary encrypted comms backbone | ATAK integration + backup mesh |

**Strategy:** Run both. Use Meshtastic for ATAK PLI/chat relay over LoRa. Use Reticulum for primary encrypted messaging, file transfer, and bulletin board.

### 3.6 APRS Integration

APRS (Automatic Packet Reporting System) can be integrated via:
- Reticulum `KISSInterface` connected to a TNC (Terminal Node Controller)
- Direwolf software TNC on the Pi 5 with an attached radio
- LoRa APRS iGate firmware on ESP32 boards (separate from Reticulum)

This is a secondary capability -- prioritize Reticulum and Meshtastic first.

---

## 4. Tailscale Mesh VPN

### 4.1 Overview

Tailscale creates a WireGuard-based mesh VPN (tailnet) that connects all your devices with end-to-end encrypted tunnels. It handles NAT traversal automatically, making it ideal for connecting a portable community node back to the Mission 1 home network.

### 4.2 Installation on Pi 5 (ARM64)

```bash
# Install Tailscale
curl -fsSL https://tailscale.com/install.sh | sh

# Start and authenticate
sudo tailscale up

# Enable as subnet router + exit node
sudo tailscale up \
  --advertise-routes=10.50.0.0/24 \
  --advertise-exit-node \
  --accept-routes
```

Enable IP forwarding (required for subnet routing and exit node):
```bash
echo 'net.ipv4.ip_forward = 1' | sudo tee -a /etc/sysctl.d/99-tailscale.conf
echo 'net.ipv6.conf.all.forwarding = 1' | sudo tee -a /etc/sysctl.d/99-tailscale.conf
sudo sysctl -p /etc/sysctl.d/99-tailscale.conf
```

### 4.3 Key Features for Community Node

#### Subnet Routing
Advertise the community node's local subnet (e.g., `10.50.0.0/24`) to the tailnet. This lets devices on the home network (Mission 1) access services on the community node's LAN without installing Tailscale on every device.

```bash
sudo tailscale up --advertise-routes=10.50.0.0/24
```
Then approve the route in the Tailscale admin console (or Headscale CLI).

#### Exit Node
Configure the community node as a VPN exit node. Devices using it as exit node will route all internet traffic through the community node's connection.

```bash
sudo tailscale up --advertise-exit-node
```

#### Tailscale Funnel
Expose specific services to the public internet without port forwarding:
```bash
# Expose OTS Web UI publicly
tailscale funnel 8080

# Expose a specific service with HTTPS
tailscale funnel --bg https+insecure://localhost:8080
```

#### MagicDNS
Automatic DNS resolution for all devices on the tailnet:
- `community-node.tailnet-name.ts.net` resolves to the Pi's Tailscale IP
- Services accessible by hostname across the mesh

### 4.4 Integration with Mission 1 Home Network

Both the Mission 1 home server and Mission 2 community node join the **same tailnet**. This creates a seamless encrypted overlay:

```
Mission 1 (Home)                    Mission 2 (Portable)
+-----------------+    Tailscale    +------------------+
| Proxmox Host    |<-- WireGuard -->| Raspberry Pi 5   |
| 10.10.0.0/24    |    Tunnel       | 10.50.0.0/24     |
+-----------------+                 +------------------+
      |                                    |
  Home LAN                          Community LAN
  (subnet routed)                   (subnet routed)
```

### 4.5 Headscale -- Self-Hosted Control Server

Headscale is an open-source, self-hosted implementation of the Tailscale control server. It eliminates dependency on Tailscale's cloud coordination service.

- **Repository:** `github.com/juanfont/headscale`
- **Current Version:** 0.23.x
- **License:** BSD-3-Clause

**Why Headscale?**
- Full sovereignty -- no third-party coordination server
- No account limits (Tailscale free tier: 100 devices)
- Self-hosted on Mission 1 Proxmox or the community node itself
- Compatible with official Tailscale clients

**Deployment:** See Docker Compose section below.

**Headscale CLI basics:**
```bash
# Create a user
headscale users create community

# Generate auth key for nodes
headscale preauthkeys create --user community --reusable --expiration 24h

# List nodes
headscale nodes list

# Approve routes
headscale routes list
headscale routes enable --route <route-id>
```

---

## 5. Meshtastic Integration

### 5.1 Overview

Meshtastic is an open-source, off-grid mesh communication platform running on affordable LoRa hardware. It is simpler than Reticulum and has a polished mobile app experience and direct ATAK integration.

- **Website:** meshtastic.org
- **Firmware:** Runs on ESP32 + LoRa boards (LilyGO, Heltec, RAK, etc.)
- **Clients:** Android app, iOS app, web client, Python CLI

### 5.2 Hardware

Recommended Meshtastic devices (separate from Reticulum RNode):
- **Heltec V3** (~$18) -- compact, OLED display, SX1262
- **LilyGO T-Beam** (~$30) -- GPS + 18650 battery holder + SX1276
- **RAK WisBlock Starter Kit** (~$25) -- modular, low power

Each community member can carry a Meshtastic device for LoRa mesh participation.

### 5.3 ATAK Plugin Integration

The Meshtastic ATAK Plugin (v1.1.16+) bridges ATAK with the Meshtastic LoRa mesh:

**Features:**
- Sends/receives CoT (Cursor on Target) data over LoRa
- Position Location Information (PLI) sharing without internet
- Geo-chat over mesh
- Server relay: forwards PLI/chat between Meshtastic mesh and TAK server
- External GPS: use Meshtastic device GPS as ATAK GPS source
- AES-256-GCM encryption

**Setup Flow:**
1. Install Meshtastic Android app + pair Meshtastic device via Bluetooth
2. Install ATAK-CIV from Google Play
3. Install Meshtastic ATAK Plugin (sideload APK from GitHub releases)
4. Plugin auto-detects Meshtastic service
5. CoT data now flows: ATAK <-> Meshtastic App <-> LoRa Mesh

### 5.4 MQTT Bridge

Meshtastic can bridge its LoRa mesh to an MQTT broker, enabling:
- Internet-connected services to receive mesh messages
- Integration with Home Assistant, Node-RED, custom dashboards
- Cross-mesh connectivity (connect distant Meshtastic meshes via MQTT)

```
Meshtastic Node <--LoRa--> Meshtastic Node (with WiFi)
                                |
                           MQTT Broker (Mosquitto on Pi)
                                |
                     Node-RED / Home Assistant / OTS
```

### 5.5 Community Deployment Topology

```
                    [Community Node Pi 5]
                    OpenTAK Server + MQTT
                    Reticulum Transport
                    Tailscale VPN
                           |
              +------------+------------+
              |            |            |
        [Member A]    [Member B]    [Member C]
        ATAK + Mesh   ATAK + Mesh   Sideband + Mesh
        Phone + T-Beam Phone + Heltec  Phone + RNode
```

---

## 6. Docker Compose Stack

### 6.1 Complete Tactical Services Stack

```yaml
# M2 Community Node -- Tactical Communications Stack
# File: /opt/community-node/docker-compose.yml

services:
  # ============================================================
  # OpenTAK Server — Situational Awareness / TAK Server
  # ============================================================
  # OTS runs NATIVELY under systemd — NOT in Docker.
  # Install: see BUILD_GUIDE.md Phase 5B
  # Status: systemctl status opentakserver
  # Ports: 8080 (HTTP UI), 8088 (CoT TCP), 8089 (CoT SSL),
  #        8443 (HTTPS UI), 8446 (cert enrollment)
  # Web UI: http://192.168.8.20:8080

  # ============================================================
  # Reticulum Daemon (rnsd) -- Encrypted Mesh Transport Node
  # ============================================================
  reticulum:
    image: python:3.12-slim
    container_name: reticulum-node
    restart: unless-stopped
    network_mode: host
    command: >
      bash -c "
        pip install --quiet rns nomadnet lxmf &&
        rnsd
      "
    volumes:
      - reticulum-config:/root/.reticulum
      - nomadnet-data:/root/.nomadnetwork
    devices:
      # Pass through USB LoRa device (RNode) if connected
      - /dev/ttyUSB0:/dev/ttyUSB0
    # Ports (host networking):
    #   4242  - Reticulum TCP transport
    #   37428 - Reticulum shared instance

  # ============================================================
  # NomadNet -- Terminal BBS / Messaging over Reticulum
  # ============================================================
  nomadnet:
    image: python:3.12-slim
    container_name: nomadnet
    restart: unless-stopped
    network_mode: host
    command: >
      bash -c "
        pip install --quiet nomadnet &&
        nomadnet --daemon
      "
    volumes:
      - reticulum-config:/root/.reticulum
      - nomadnet-data:/root/.nomadnetwork
    depends_on:
      - reticulum

  # ============================================================
  # MeshChat -- Web-based Reticulum Messenger
  # ============================================================
  # meshchat:
  #   image: ghcr.io/liamcottle/reticulum-meshchat:latest
  #   container_name: meshchat
  #   restart: unless-stopped
  #   ports:
  #     - "8338:8338"
  #   volumes:
  #     - reticulum-config:/root/.reticulum
  #     - meshchat-data:/root/.meshchat
  #   depends_on:
  #     - reticulum

  # ============================================================
  # Mosquitto MQTT Broker -- Meshtastic Bridge
  # ============================================================
  mosquitto:
    image: eclipse-mosquitto:2
    container_name: mosquitto
    restart: unless-stopped
    ports:
      - "1883:1883"
      - "9001:9001"
    volumes:
      - mosquitto-config:/mosquitto/config
      - mosquitto-data:/mosquitto/data
      - mosquitto-log:/mosquitto/log

  # ============================================================
  # Headscale -- Self-Hosted Tailscale Control Server (Optional)
  # ============================================================
  headscale:
    image: headscale/headscale:0.28.0
    container_name: headscale
    restart: unless-stopped
    ports:
      - "8180:8080"
      - "50443:50443"
    volumes:
      - headscale-config:/etc/headscale
      - headscale-data:/var/lib/headscale
    command: headscale serve
    environment:
      - TZ=America/New_York
    profiles:
      - headscale

volumes:
  reticulum-config:
    driver: local
  nomadnet-data:
    driver: local
  mosquitto-config:
    driver: local
  mosquitto-data:
    driver: local
  mosquitto-log:
    driver: local
  headscale-config:
    driver: local
  headscale-data:
    driver: local
```

### 6.2 Deployment Commands

```bash
# Create directory structure
sudo mkdir -p /opt/community-node
cd /opt/community-node

# Copy docker-compose.yml and Reticulum config

# Start core services (without Headscale)
docker compose up -d

# Start with Headscale (self-hosted Tailscale control)
docker compose --profile headscale up -d

# View logs
# OTS: journalctl -u opentakserver -f
docker compose logs -f reticulum-node

# Verify services
docker compose ps
```

### 6.3 Mosquitto Configuration

Create `/opt/community-node/mosquitto/config/mosquitto.conf`:

```
listener 1883
allow_anonymous true
listener 9001
protocol websockets
```

### 6.4 Reticulum Configuration

Copy the configuration from Section 2.5 to the reticulum-config volume. On first run:

```bash
# Generate default config
docker exec reticulum-node rnsd --exampleconfig > /tmp/reticulum-config.example

# Copy custom config into volume
docker cp ~/.reticulum/config reticulum-node:/root/.reticulum/config

# Restart to apply
docker compose restart reticulum
```

---

## 7. Hardware Add-ons BOM

### 7.1 LoRa / Radio Hardware

| Item | Description | Est. Price | Source |
|---|---|---|---|
| **LilyGO T3 v1.6.1 (LoRa32 v2.1)** | RNode transceiver -- SX1276, 915 MHz, ESP32, OLED, USB-C | $18-25 | AliExpress, Amazon |
| **LilyGO T-Beam v1.1** | RNode w/ GPS + 18650 battery, SX1276/SX1262 | $25-35 | AliExpress, Amazon |
| **Waveshare SX1262 LoRa HAT** | Pi 5 HAT, 915 MHz, UART interface | $20-25 | Waveshare, Amazon |
| **Heltec V3 LoRa** | Meshtastic node, SX1262, OLED, USB-C | $16-20 | AliExpress, Heltec |
| **915 MHz LoRa Antenna (SMA)** | 5 dBi omni antenna, magnetic base | $8-12 | Amazon |
| **915 MHz Yagi Antenna** | Directional, 8-12 dBi, for long range links | $25-40 | Amazon, eBay |
| **SMA pigtail / adapter** | U.FL to SMA, or SMA extension cable | $5-8 | Amazon |

### 7.2 Recommended Minimum Kit

For the community node itself:

| Item | Purpose | Price |
|---|---|---|
| LilyGO T3 v1.6.1 x1 | RNode for Reticulum LoRa interface | $20 |
| Heltec V3 x1 | Meshtastic node (MQTT bridge to Pi) | $18 |
| 915 MHz antenna x2 | One per radio | $20 |
| USB-A to USB-C cables x2 | Connect radios to Pi | $8 |
| **Subtotal** | | **~$66** |

### 7.3 Per-Member Kit

Each community member should carry:

| Item | Purpose | Price |
|---|---|---|
| Heltec V3 or T-Beam | Meshtastic personal node | $18-30 |
| 915 MHz antenna | Attached to device | $10 |
| Android phone | ATAK + Meshtastic + Sideband apps | (existing) |
| **Subtotal** | | **~$28-40** |

### 7.4 Optional / Bonus Hardware

| Item | Description | Est. Price |
|---|---|---|
| **RTL-SDR v4** | Software-defined radio dongle for ADS-B, NOAA weather, scanning | $30 |
| **1090 MHz ADS-B antenna** | For aircraft tracking with dump1090 | $15 |
| **RAK2245 Pi HAT** | Full LoRaWAN gateway concentrator (if LoRaWAN needed) | $80 |
| **Baofeng UV-5R** | Handheld VHF/UHF radio for APRS or voice backup | $25 |
| **Mobilinkd TNC4** | Bluetooth packet radio TNC for APRS integration | $70 |
| **Weatherproof enclosure** | IP67 case for outdoor/field deployment | $20-40 |

### 7.5 Total Estimated Cost (Node Radio Add-ons)

| Category | Est. Cost |
|---|---|
| Minimum radio kit (node only) | ~$66 |
| Per-member kit (x5 members) | ~$150-200 |
| Optional RTL-SDR + ADS-B | ~$45 |
| Optional APRS kit | ~$95 |
| **Total (node + 5 members + extras)** | **~$360-410** |

---

## 8. Integration Architecture

### 8.1 Full System Diagram

```
                        ============================================
                        |       COMMUNITY NODE (Raspberry Pi 5)     |
                        |                                           |
  Internet/Cellular <-->| Tailscale VPN ----- Mission 1 Home Net    |
       (when avail)     |                                           |
                        |  +------------------+  +--------------+   |
                        |  | OpenTAK Server   |  | MQTT Broker  |   |
                        |  | (CoT/SA/Chat/    |  | (Mosquitto)  |   |
                        |  |  Web Map UI)     |  |              |   |
                        |  +--------+---------+  +------+-------+   |
                        |           |                    |          |
                        |  +--------+---------+  +------+-------+   |
                        |  | Reticulum (rnsd) |  | Meshtastic   |   |
                        |  | NomadNet/LXMF    |  | MQTT Bridge  |   |
                        |  +--------+---------+  +------+-------+   |
                        |           |                    |          |
                        ============|====================|==========
                                    |                    |
                              [RNode USB]          [Heltec V3 USB]
                              915 MHz LoRa         915 MHz LoRa
                                    |                    |
                        +-----------+-----------+--------+----------+
                        |                       |                   |
                  [Member A]              [Member B]          [Member C]
                  Phone: ATAK+Sideband    Phone: ATAK         Phone: Sideband
                  Radio: T-Beam           Radio: Heltec V3    Radio: T3 (RNode)
                  (Mesh + Reticulum)      (Meshtastic)        (Reticulum)
```

### 8.2 Communication PACE Plan (Tactical Layer)

| Priority | Method | Medium | Range | Dependency |
|---|---|---|---|---|
| **Primary** | ATAK + OpenTAK Server | WiFi / Cellular / Tailscale | Global (internet) | Internet connectivity |
| **Alternate** | Meshtastic LoRa mesh | 915 MHz LoRa radio | 1-15 km | LoRa hardware, no internet needed |
| **Contingency** | Reticulum + LXMF (Sideband/NomadNet) | LoRa via RNode | 1-15 km | RNode hardware, no internet needed |
| **Emergency** | Reticulum over serial / packet radio | VHF/UHF radio + TNC | 5-50 km | Amateur radio license, TNC hardware |

### 8.3 Startup Sequence

1. Boot Pi 5 and Docker services auto-start
2. Tailscale connects to tailnet (if internet available)
3. OpenTAK Server starts accepting CoT connections on port 8088/8089, web UI on 8080
4. Reticulum daemon starts, opens TCP transport (port 4242) and RNode LoRa interface
5. NomadNet daemon starts, announces pages on Reticulum network
6. Mosquitto MQTT broker starts for Meshtastic bridge
7. Connect Meshtastic node via USB -- configure MQTT uplink to localhost:1883
8. Clients connect: ATAK to OTS, Sideband to Reticulum, Meshtastic app to mesh

### 8.4 Key Recommendations

1. **Start with Meshtastic for ATAK integration** -- it has the most mature plugin and is easiest for non-technical community members.
2. **Deploy Reticulum as the encrypted backbone** -- its identity-based encryption and delay tolerance make it superior for sensitive communications.
3. **Use separate LoRa hardware** for Meshtastic and Reticulum -- they use different protocols and cannot share a single radio.
4. **Tailscale (or Headscale) is essential** for connecting back to Mission 1 -- it handles NAT traversal automatically.
5. **RNode DIY build** is strongly recommended over buying LoRa HATs -- better Reticulum support, antenna flexibility, and lower cost.
6. **Test range before deployment** -- actual LoRa range varies dramatically with terrain. Do a walk/drive test with your specific antenna setup.
7. **Mosquitto MQTT broker** bridges Meshtastic to other services -- use it to feed Meshtastic data into Node-RED, Home Assistant, or custom dashboards.
8. **NomadNet pages** serve as an off-grid information board -- post community updates, maps, procedures accessible to anyone on the Reticulum mesh.

---

## References

- OpenTAK Server Documentation: https://opentakserver.io/
- OpenTAK Server GitHub: https://github.com/brian7704/OpenTAKServer
- Reticulum Network Stack: https://github.com/markqvist/Reticulum
- Reticulum Manual (v1.1.3): https://reticulum.network/manual/
- Reticulum Interface Configuration: https://reticulum.network/manual/interfaces.html
- Sideband App: https://github.com/markqvist/Sideband
- NomadNet: https://github.com/markqvist/NomadNet
- MeshChat: https://github.com/liamcottle/reticulum-meshchat
- RNode Firmware Install: https://unsigned.io/installing-rnode-firmware-on-supported-devices/
- Meshtastic ATAK Plugin: https://meshtastic.org/docs/software/integrations/integrations-atak-plugin/
- Meshtastic ATAK Plugin GitHub: https://github.com/meshtastic/ATAK-Plugin
- Tailscale Raspberry Pi Setup: https://tailscale.com/kb/1103/exit-nodes
- Headscale: https://github.com/juanfont/headscale
- Headscale Container Docs: https://headscale.net/stable/setup/install/container/
- Heltec WiFi LoRa 32 V3: https://heltec.org/project/wifi-lora-32-v3/
- Waveshare SX1262 LoRa HAT: https://www.waveshare.com/sx1262-868m-lora-hat.htm
- RAK Wireless Pi HATs: https://store.rakwireless.com/collections/lora-for-raspberry-pi-hats-modules-add-ons

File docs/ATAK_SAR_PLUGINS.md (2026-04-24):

# M2 -- ATAK Integration Guide

> **Context:** Community Node (M2) field kit -- ATAK-CIV configuration for
> community emergency response, CERT, SAR, and disaster operations.

---

## Table of Contents

1. [Design Philosophy](#1-design-philosophy)
2. [What ATAK Does Out of the Box](#2-what-atak-does-out-of-the-box)
3. [Recommended Plugins](#3-recommended-plugins)
4. [Data Packages Pre-Loaded on OTS](#4-data-packages-pre-loaded-on-ots)
5. [Volunteer Onboarding Flow](#5-volunteer-onboarding-flow)
6. [Specialist Tools (Self-Install)](#6-specialist-tools-self-install)
7. [Plugins Evaluated and Cut](#7-plugins-evaluated-and-cut)
8. [Community Resources](#8-community-resources)
9. [Sources](#9-sources)

---

## 1. Design Philosophy

A volunteer who just downloaded ATAK should be operational in under 5 minutes. Every plugin that auto-installs is another thing that can break, another prompt to dismiss, another icon to explain. The M2 node prioritizes **reliability and simplicity** over feature count.

Three rules:

1. **If ATAK already does it, don't add a plugin.** ATAK core handles position sharing, chat, markers, drawing, route planning, CASEVAC reports, checklists, track logging, and offline maps. No plugins needed for any of that.
2. **If it requires internet, cut it.** The M2 operates offline or on local WiFi. Plugins that phone home are dead weight.
3. **If it requires hardware the volunteer doesn't have, don't auto-install it.** A Meshtastic plugin is useless without a Meshtastic radio. A drone plugin is useless without a drone.

**Server-side rule:** No new containers on the Pi. The stack is full: OTS, Murmur, Monero, Conduit, Cloudflared, Headscale, Tor, I2P, Mosquitto. Every additional service degrades reliability for the services that matter.

### Correction: OTS Plugin Auto-Push

OTS **cannot** auto-install APK plugins on devices. Android requires user interaction to install APKs. What OTS CAN auto-push are **data packages** -- certificates, server configs, map tiles, KML overlays. Plugins must be installed from the Play Store or sideloaded manually.

The onboarding QR code links to a page with Play Store links for required apps. See [Section 5](#5-volunteer-onboarding-flow).

---

## 2. What ATAK Does Out of the Box

These features are included in ATAK-CIV 5.6.0 with **no plugins and no server**. They work over multicast UDP on any shared WiFi network, or over OTS when a server is available.

### Position Sharing (PLI)

Every ATAK device broadcasts its position automatically. All teammates appear as colored dots on the map. No configuration beyond connecting to the same network or server. Default reporting interval works for most use cases.

### GeoChat

Text messaging within ATAK -- one-to-one, team channels, or broadcast. Messages are CoT objects that work over any transport: server, multicast, or Meshtastic mesh.

### Drawing & Markup

Create shapes (circles, rectangles, polygons, lines, freehand) on the map. Set color, fill, labels. Use for search sectors, hazard zones, evacuation routes, staging areas. All drawings sync to connected devices via server.

### CASEVAC / 9-Line MEDEVAC

Built-in 9-line MEDEVAC report following JFIRE 2016 Appendix G. Includes ZMIST report and HLZ (Helicopter Landing Zone) brief. Creates map markers at casualty location shared to all connected EUDs.

### Route Planning

Multi-waypoint routes with distance/bearing calculations. View route details including total distance and estimated travel time. Not turn-by-turn, but sufficient for point-to-point field navigation.

### Elevation Profile & Line of Sight

Select any route or line to see elevation profile (requires DTED loaded -- already on M2). Enable viewshed analysis for radio relay placement and visual search planning. This is why we built the DTED2 data package.

### ExCheck (Collaborative Checklists)

Checklists hosted on OTS. Create templates for ICS forms, search phase tracking, equipment checks, comms plan verification. All team members see real-time task status. Templates are XML distributed via data packages.

### Track Logging / Breadcrumbs

Continuous GPS track recording. See your path and teammates' paths. Export as KML/GPX. Critical for SAR to verify complete area coverage with no gaps in the search grid.

### Geofencing & Alerts

Attach triggers to any drawn shape. Configure alerts when team members enter or exit a zone. Use for danger zones, search boundaries, or rally point monitoring.

### Coordinate Entry & Conversion

MGRS, UTM, lat/lon (DD, DMS, DDM). Convert between formats. Share precise locations. Set display format per user preference.

### Offline Maps

Import MBTiles, SQLite, GeoPackage, KML/KMZ, GeoTIFF/GeoPDF. The M2 serves PMTiles on port 8080 -- street-level offline maps for FL/SC/NC/VA are already loaded.

### Built-in Plugins (Available from CivTAK, Not Play Store)

| Plugin | Purpose |
|---|---|
| TAK ICU | Peer-to-peer video streaming (no server needed) |
| TAK GeoCam | Geotagged tactical camera |
| Image Markup | Annotate geotagged photos |
| Night Vision | Night-optimized display mode |

Download from [CivTAK](https://www.civtak.org/2020/10/11/built-in-plugins-that-arent-in-the-play-store/). These are optional -- install on team lead devices if needed.

### Icon Sets (Pre-Loaded)

ATAK ships with: FEMA markers, Incident Management symbols, Public Safety Air icons, Responder icons, GeoOps icons, MIL-STD-2525C military symbology. No additional icon packs needed for emergency response.

---

## 3. Recommended Plugins

Two plugins. That's it.

### 3.1 Meshtastic ATAK Plugin

**What:** Bridges ATAK to Meshtastic LoRa mesh radios for off-grid position sharing and text chat. No cellular, no WiFi, no internet required.

| Field | Detail |
|---|---|
| Install | [GitHub Releases](https://github.com/meshtastic/ATAK-Plugin/releases) (match version to ATAK) |
| Version | Match to ATAK version (e.g., 2.5.x for ATAK 5.6) |
| Works offline | Yes -- this IS the offline solution |
| Server required | No |
| Extra hardware | **Yes -- Meshtastic LoRa radio ($35-60)** |

**Who needs it:** Only operators who have their own Meshtastic radio paired to their phone.

> **Most volunteers do NOT need this plugin.** The M2 already has a Heltec V3 radio connected to OTS via the built-in [TAK Meshtastic Gateway](https://docs.opentakserver.io/tak_meshtastic_gateway.html). This server-side gateway bridges mesh traffic to ALL connected ATAK clients automatically -- no per-device plugin needed. The plugin is only for operators who want direct radio-to-phone pairing with their own Meshtastic device.

**Key config (for users with their own radio):**
- Set Meshtastic device role to `TAK` (compressed PLI via ATAK plugin)
- Set to `TAK_TRACKER` for devices without ATAK (standalone GPS beacons)
- Green icon in ATAK = connected; red = binding failed (restart Meshtastic app)

**Install method:** Sideload APK. Not on Play Store. Provide APK file via OTS data package download or USB.

---

### 3.2 VNS (Vehicle Navigation System)

**What:** Turn-by-turn vehicle navigation inside ATAK. Emergency quick-nav feature: one tap to route to a pre-set rally point or casualty collection point. Offline routing available.

| Field | Detail |
|---|---|
| Install | [Google Play Store](https://play.google.com/store/apps/details?id=com.atakmap.android.vns.plugin) |
| Version | 5.6.0 (matches ATAK 5.6) |
| Works offline | Yes (with pre-loaded routing data) |
| Server required | No |
| Extra hardware | No |

**Who needs it:** Team leads running vehicle-based operations (road SAR, logistics, convoy). Not useful for foot-based wilderness SAR.

> The emergency quick-nav to rally point is the only feature that isn't already covered by Google Maps or OsmAnd. For teams that pre-define rally points and casualty collection points, the one-tap routing is genuinely useful.

**Install method:** Play Store. Opt-in only -- team leads install it themselves.

---

## 4. Data Packages Pre-Loaded on OTS

These are what OTS actually pushes to devices. This is the M2's real distribution mechanism.

### Already Deployed

| Package | Contents | Size | Auto-push |
|---|---|---|---|
| DTED2 Florida | 30m elevation data for LOS analysis, slope, viewshed | ~3.25 GB | Via QR scan (DTED.org) |
| PMTiles SE US | Street-level offline maps FL/SC/NC/VA at z14 | ~2-4 GB | Served on port 8080 |
| Community Node marker | CoT event showing M2 HQ position | ~1 KB | Auto (cron push) |

### To Build

| Package | Contents | Purpose | Auto-push |
|---|---|---|---|
| Connection data package | Server URL + certs + preferences | One-file ATAK onboarding | Yes |
| Rally point markers | Pre-set KML with local hospitals, fire stations, shelters | Common operating picture baseline | Yes |
| ATAK-Maps profiles | MOBAC XML sources for USGS topo, satellite, OpenTopo | Additional map layer options | Yes |
| ExCheck SAR template | Grid search phase checklist (custom, no public templates exist) | SAR task tracking | Available on request |

> **Offline map warning:** Selecting a map source in ATAK does NOT make it available offline. Tiles must be pre-cached using ATAK's built-in downloader (max 300,000 tiles per session) or pre-loaded as MBTiles/PMTiles files. The M2's PMTiles are already cached -- no internet required.

---

## 5. Volunteer Onboarding Flow

### Local WiFi (On-Site)

1. Volunteer connects to **CommunityNode** WiFi (password on community page or QR poster)
2. Opens browser, goes to `http://192.168.8.10:8081` (community page)
3. Taps **ATAK-CIV** Play Store link -- installs the app
4. Opens ATAK, sets callsign (name or handle), accepts location permissions
5. Adds server: `192.168.8.20`, port `8088`, TCP, **uncheck SSL/TLS**
6. Map loads with offline tiles, teammate positions appear, Community Node marker visible
7. Volunteer is operational

**Total time: 3-5 minutes.** One app, one server connection. Clean UI.

### Remote (Out of Area)

See BUILD_GUIDE Section 9.1.1 -- Remote Operator Onboarding. Two tiers:

- **Browser only:** `https://tak.yourdomain.com` -- live web map, no install
- **Full ATAK:** Install Tailscale, join Headscale VPN, connect ATAK to `192.168.8.20:8088`

### What NOT to Do

- Do NOT push multiple plugins at once. A first-time user staring at overlays from three different plugins will close the app.
- Do NOT require SSL on first connection. TCP works on trusted LAN. SSL adds cert troubleshooting to onboarding.
- Do NOT assume volunteers have Meshtastic radios. The server-side gateway handles mesh bridging for everyone.

---

## 6. Specialist Tools (Self-Install)

These are documented for teams that bring specialized hardware. They are NOT pre-loaded on OTS, NOT pushed to devices, and NOT part of the standard M2 loadout. Specialists install them themselves.

| Tool | Who | Hardware Required | Install From |
|---|---|---|---|
| OpenAthena | Drone operators | DJI/Autel/Parrot/Skydio drone | [GitHub](https://github.com/Theta-Limited/OpenAthenaAndroid) |
| UAS Tool | Drone operators (DJI) | DJI drone | [CivTAK](https://www.civtak.org/) |
| TAKWatch | Garmin watch owners | Garmin Instinct/Fenix | [GitHub](https://github.com/TDF-PL/TAKWatch) + [Garmin IQ](https://apps.garmin.com/apps/9f3aa645-f24f-49f2-af0f-328b98a7be70) |
| APRSTAK | Licensed ham operators | Ham radio with TNC + APRSDroid | [GitHub](https://github.com/niccellular/aprstak) |

---

## 7. Plugins Evaluated and Cut

These were reviewed during the March 2026 audit and removed from the M2 loadout. Rationale preserved so future builders can make informed decisions for their own deployments.

| Plugin | Verdict | Rationale |
|---|---|---|
| **WASP** (Wide Area Search) | Cut | Wickr was shut down by AWS in early 2024. Plugin hasn't been updated since. Won't install on current-generation devices (Samsung S25, Pixel 9). The Play Store listing (`com.atakmap.android.wickr.plugin`) shows Wickr branding but the backend service no longer exists. Dead software. |
| **HAMMER** (acoustic modem) | Cut | Crashes with Baofeng radios (most common civilian radio). Requires audio cables + per-device tuning. Being deprecated. Meshtastic replaces this use case entirely. [Field test report](https://guntoter.org/2022/03/08/atak-hammer-and-baofengs-the-bad-news/). |
| **FreeTAK Mumla Plugin** | Cut | Mumla standalone app works fine for PTT voice without this plugin. Plugin has unclear maintenance status and may break on ATAK 5.6. A broken PTT overlay is worse than no overlay. Use Mumla directly -- it's a simple app. |
| **OpenTAK ICU** | Cut | Requires adding MediaMTX container to an already-full Pi. Video streaming saturates the WiFi that ATAK needs for position updates. Built-in TAK ICU does peer-to-peer video without a server if genuinely needed. |
| **Wx Report** | Cut | Requires internet for NOAA data. Useless offline. If you have internet, use your phone's weather app. The open-source alternative (ATAK-Weather-Plugin) also requires internet. Check the weather before you deploy. |
| **TAK-CAD** | Cut | Alpha software built for official TAK Server, not OTS. Compatibility unverified. A 5-15 person CERT team needs a whiteboard and a radio, not computer-aided dispatch. ExCheck handles basic task tracking. |
| **LandSAR** | Cut | Requires a Java server on a Pi already running 5+ services. Professional SAR teams that need probability modeling bring their own tools. Community CERT teams doing grid searches use WASP and paper maps. |
| **ADSBCOT** | Cut | Requires RTL-SDR dongle + dump1090 + adsbcot Python package on the Pi. Additional hardware and server components for aircraft tracking that is irrelevant to CERT ground operations. |
| **WiFi2COT** | Cut | One-developer GitHub project with unclear maintenance. The "detect survivor phones via WiFi" concept is theoretical -- if you're close enough to detect WiFi RSSI, you're close enough to shout. Not reliable enough for emergency use. |
| **CloudRF / SOOTHSAYER** | Cut | Requires another Docker container (or paid cloud service) for a pre-planning tool. ATAK's built-in viewshed/line-of-sight analysis covers basic radio coverage questions. Run SOOTHSAYER on a laptop during pre-mission planning if needed. |

---

## 8. Community Resources

### Reference Hubs

| Resource | URL | Contents |
|---|---|---|
| fieldmapper's TAK Gist | [GitHub Gist](https://gist.github.com/fieldmapper/2756ae29bff337ec7bda5d25f310c772) | Comprehensive link collection -- hardware, software, data packages, tutorials |
| CivTAK Files | [civtak.org/files](https://www.civtak.org/files/) | Official community data packages and resources |
| CivTAK Plugins | [civtak.org/category/plugins](https://www.civtak.org/category/plugins/) | Plugin announcements and documentation |
| ATAK-Maps | [GitHub](https://github.com/joshuafuller/ATAK-Maps) | MOBAC XML map source definitions (USGS topo, satellite, OpenTopo) |
| 9M2PJU Plugin List | [GitHub](https://github.com/9M2PJU/ATAK-Civ-Plugins) | Compiled list of CIV plugins with links |

### Training Resources

| Resource | URL | Focus |
|---|---|---|
| Colorado Fire Tech | [cofiretech.gov/introduction-to-tak](https://cofiretech.gov/introduction-to-tak) | Fire/EMS TAK introduction |
| Chaos Koalas | [chaoskoalas.com/atak](https://chaoskoalas.com/atak/) | Getting started with ATAK |
| Constellation Response | [Quick Start Pt1](https://constellationresponse.com/blogs/news/atak-quick-start-guide-pt1) / [Pt2](https://constellationresponse.com/blogs/news/atak-quick-start-guide-pt2-comms-and-offline-maps) | ATAK quick start + offline maps |
| ToughStump | [First Time Setup](https://toughstump.com/2023/12/05/first-time-user-set-up-in-atak/) | First-time user walkthrough |
| BuffaLoRa | [Meshtastic + ATAK SAR Drill](https://buffalora.org/2025/09/14/meshtastic-as-a-plugin-to-atak/) | Real-world SAR drill using Meshtastic + ATAK |

### Data Package Formats

| Format | Use Case |
|---|---|
| .zip (data package) | Bundle of certs, configs, KML, map tiles -- one-file onboarding |
| .kml / .kmz | Map overlays -- search grids, hazard zones, boundaries |
| .mbtiles | Offline map tiles |
| .dpk | Signed data package for TAK Server distribution |

---

## 9. Sources

- [CivTAK / ATAK Community](https://www.civtak.org/)
- [Meshtastic ATAK Plugin Docs](https://meshtastic.org/docs/software/integrations/integrations-atak-plugin/)
- [Meshtastic ATAK Plugin GitHub](https://github.com/meshtastic/ATAK-Plugin)
- [OpenTAKServer Docs](https://docs.opentakserver.io/)
- [TAK Meshtastic Gateway (OTS Docs)](https://docs.opentakserver.io/tak_meshtastic_gateway.html)
- [VNS on Google Play](https://play.google.com/store/apps/details?id=com.atakmap.android.vns.plugin)
- [CivTAK Built-in Plugins](https://www.civtak.org/2020/10/11/built-in-plugins-that-arent-in-the-play-store/)
- [ATAK-Maps GitHub](https://github.com/joshuafuller/ATAK-Maps)
- [Colorado Fire Tech - Introduction to TAK](https://cofiretech.gov/introduction-to-tak)
- [HAMMER Field Test (Gun Toter)](https://guntoter.org/2022/03/08/atak-hammer-and-baofengs-the-bad-news/)
- [BuffaLoRa - Meshtastic + ATAK SAR Drill](https://buffalora.org/2025/09/14/meshtastic-as-a-plugin-to-atak/)
- [Constellation Response - ATAK Quick Start](https://constellationresponse.com/blogs/news/atak-quick-start-guide-pt1)
- [Chaos Koalas - Getting Started with ATAK](https://chaoskoalas.com/atak/)
- [ToughStump - First Time Setup](https://toughstump.com/2023/12/05/first-time-user-set-up-in-atak/)
- [OpenTAKServer Plugin Update Server](https://docs.opentakserver.io/update_server.html)
- [fieldmapper TAK Resources Gist](https://gist.github.com/fieldmapper/2756ae29bff337ec7bda5d25f310c772)

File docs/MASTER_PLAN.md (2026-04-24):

# Mission 2 - MASTER COMMUNITY NODE PLAN
## Portable, Self-Contained, Decentralized Community Support Node

> **Version:** 1.4 
> **Platform:** Raspberry Pi 5 16GB (Node #1) + Raspberry Pi 5 16GB (Node #2) in 10" Mini-Rack — Dual Pi 5 Build
> **Pricing:** All hardware prices verified Feb 2026 from live retail sources
> **Design:** Privacy-first, censorship-resistant, field-deployable, open-source only

---

## Executive Summary

This document is the consolidated master plan for a portable, self-contained, decentralized community support node built entirely from open-source software and commodity hardware. The system fits inside a 10-inch 8U mini-rack (roughly the size of a large shoebox) and provides:

- **Encrypted group communications** -- Matrix/Conduit chat server with Element Web client, accessible over clearnet, Tor, and I2P simultaneously
- **Tactical situational awareness** -- OpenTAK Server for ATAK clients with real-time position tracking, geo-chat, map sharing, and built-in web map UI
- **Off-grid mesh networking** -- Reticulum encrypted mesh over LoRa radio (RNode) and Meshtastic consumer mesh, operational with zero internet infrastructure
- **Anonymous networking** -- Tor hidden services (.onion) and I2P eepsites (.b32.i2p) for censorship-resistant access to all services
- **Financial sovereignty** -- Monero pruned node providing a community-accessible, privacy-preserving cryptocurrency endpoint
- **Secure remote management** -- Tailscale/Headscale WireGuard mesh VPN with site-to-site tunnel back to Mission 1 home network
- **Field-deployable** -- Runs on wall power, vehicle 12V, or UPS (~1-2 hour runtime on BC600R at typical load), or solar/battery for 24+ hour autonomous operation (solar/LiFePO4 kit required — not in base BOM)

**Design Principles:** Privacy-first. Censorship-resistant. Field-deployable (<15 min to operational). Open-source only. Commodity hardware (<$1,500, standard retailers).

---

## System Architecture Overview

### Full Stack Diagram

```
                    EXTERNAL CONNECTIONS
    ================================================
    |                    |                |          |
    Clearnet          Tor (.onion)    I2P (.b32)   LoRa Radio
    (Cloudflare       (Hidden          (Eepsite)   (915 MHz)
     Tunnel)           Services)                    |
    |                    |                |          |
    ================================================
                         |
    +====================================================+
    |            GL.iNet Slate AX (Gateway)               |
    |   WiFi AP | DHCP | WireGuard | Tailscale | DNS     |
    |   WAN: Internet/Cellular/WiFi Uplink                |
    |   LAN: 192.168.8.0/24                               |
    +========================|===========================+
                             |
    +========================|===========================+
    |          TP-Link TL-SG108S (8-Port Gigabit)        |
    +====|===================|===================|=======+
         |                   |                   |
    +====|=======+    +======|========+    +====(other)====+
    | Pi 5 #1    |    | Pi 5 #2      |    | Touchscreen   |
    | (Comms)    |    | (Tactical/   |    | Monitoring    |
    |            |    |  Crypto)     |    |               |
    | Conduit    |    | OpenTAKSvr   |    +===============+
    | Element    |    | (native)     |
    | Nginx      |    | Reticulum    |
    | i2pd       |    | NomadNet     |
    | Tor        |    | Monerod      |
    | Cloudflared|    | Mosquitto    |
    |            |    | Headscale    |
    | NVMe 256GB |    | Tailscale    |
    | (GeeekPi   |    | NVMe 1TB     |
    |  dual mnt) |    | (GeeekPi     |
    +============+    |  dual mnt)   |
                      | USB LoRa x2  |
                      +==============+

    BC600R UPS (rack floor, strapped) --> PDU --> All Components
```

### Node Assignment (Recommended 2-Node Build)

| Role | Node #1 — Raspberry Pi 5 16GB (Primary Comms) | Node #2 — Raspberry Pi 5 16GB (Tactical/Crypto) |
|---|---|---|
| **Services** | Conduit (Matrix), Element Web, Nginx, i2pd, Tor, Cloudflared | OpenTAK Server (native/systemd), Reticulum, NomadNet, Monerod, Mosquitto, Headscale, Mumble, Tailscale |
| **Storage** | WD SN740 256GB M.2 2230 NVMe via GeeekPi dual mount built-in PCIe adapter | Crucial P310 1TB M.2 2230 NVMe via GeeekPi dual mount built-in PCIe adapter; both Pi 5s in same 1U bracket |
| **Network** | Static IP: 192.168.8.10 | Static IP: 192.168.8.20 |
| **Hardware Add-ons** | None — NVMe via GeeekPi dual mount (no separate M.2 HAT+ needed) | Heltec V3 USB (RNode/Reticulum, $19.90) → USB 2.0 port 1 (LEFT panel position); Heltec V3 USB (Meshtastic, $19.90) → USB 2.0 port 2 (RIGHT panel position) — both identical hardware, differentiated by firmware |
| **Key advantage** | Lightweight ARM for always-on comms | Both nodes on NVMe — 3.5–7× IOPS vs USB SATA; Monero LMDB pre-sync workaround eliminates field-sync wait |

### Network Topology

```
Internet/Cell ------> [GL.iNet Slate AX :WAN] -----+
                       |  192.168.8.1               |
                       |  DHCP: 192.168.8.100-200   |
                       |  WiFi: "CommunityNode"     |
                       |  Tailscale subnet router    |
                       +----> LAN Port 1 -----> [TP-Link Switch Port 1]
                                                     |
                                  Port 2: Pi 5 #1 (Comms)  -- 192.168.8.10
                                  Port 3: Pi 5 #2 (Tactical) -- 192.168.8.20
                                  Port 4: Touchscreen (if networked)
                                  Port 5-8: Spare (field devices)
```

---

## Service Inventory

Complete table of all services across the entire stack:

| Service | Purpose | Docker Image | RAM (Typical) | RAM (Limit) | Storage | Port(s) | Privacy Layer | Node |
|---|---|---|---|---|---|---|---|---|
| **Conduit** | Matrix chat server (Rust) | `matrixconduit/matrix-conduit:v0.10.12` | 100-200 MB | 512 MB | 500 MB - 5 GB | 6167 | Clearnet, Tor, I2P | #1 | Note: matrixconduit/matrix-conduit is abandoned as of 2025. Active community fork is conduwuit. Plan migration post-CCC26. |
| **Element Web** | Matrix web client | `vectorim/element-web:v1.12.11` | 20-30 MB | 64 MB | 50 MB | 80 (via Nginx) | Clearnet, Tor, I2P | #1 |
| **Nginx** | Reverse proxy, SSL termination | `nginx:1.28.2-alpine3.23` | 20-40 MB | 128 MB | 10 MB | 80, 443, 8448, 8080, 8081 | All | #1 |
| **i2pd** | I2P router, eepsite hosting | `purplei2p/i2pd:release-2.59.0` | 60-100 MB | 256 MB | 50-200 MB | 7070, 4444, 4447, 7656 | I2P | #1 |
| **Tor** | Hidden services, SOCKS proxy | `osminogin/tor-simple:0.4.8.21` | 30-60 MB | 128 MB | 50-100 MB | 9050 | Tor | #1 |
| **Cloudflared** | Cloudflare Tunnel (clearnet) | `cloudflare/cloudflared:2026.2.0` | 30-50 MB | 128 MB | <10 MB | (outbound only) | Clearnet | #1 |
| **OpenTAK Server** | TAK/ATAK situational awareness + web map UI | Native (systemd) v1.7.9 | 300-600 MB | 1 GB | 2-5 GB | 8080, 8088, 8089, 8443, 8446 | Clearnet/VPN | #2 |
| **RabbitMQ** | Message broker for OTS | Installed with OTS | ~200 MB | 256 MB | 100 MB | 5672, 15672 | Internal | #2 |
| **Mumble** | Push-to-talk voice (OTS auth integration) | Native install | 30-50 MB | 128 MB | <50 MB | 64738 | LAN + VPN | #2 |
| **Reticulum (rnsd)** | Encrypted mesh transport daemon | `python:3.12.12-slim-bookworm` + pip | 30-80 MB | 256 MB | <50 MB | 4242, 37428 | Mesh/LoRa | #2 |
| **NomadNet** | BBS/messaging over Reticulum | `python:3.12.12-slim-bookworm` + pip | 30-50 MB | 128 MB | <10 MB | (Reticulum) | Mesh/LoRa | #2 |
| **Monerod** | Monero pruned public node | `ghcr.io/sethforprivacy/simple-monerod:v0.18.4.5` | 1-2 GB | 4 GB | ~95 GB (pruned) | 18080 (P2P), 18089 (RPC localhost only) | Clearnet (P2P), Tor, I2P | #2 |
| **Mosquitto** | MQTT broker (Meshtastic bridge) | `eclipse-mosquitto:2.1.2` | 10-30 MB | 64 MB | <100 MB | 1883, 9001 | Internal | #2 |
| **Headscale** | Self-hosted Tailscale control | `headscale/headscale:0.28.0` | 30-50 MB | 128 MB | <100 MB | 8180, 50443 | VPN | #2 |
| **Tailscale** | WireGuard mesh VPN client | (host install) | 20-40 MB | - | <10 MB | (outbound) | VPN | #2 |

### Resource Totals by Node

| | Pi 5 #1 — Comms (192.168.8.10) | Pi 5 #2 — Tactical/Crypto (192.168.8.20) |
|---|---|---|
| **Typical RAM** | ~0.4-0.6 GB services + ~1 GB OS/Docker | ~1.8-3.2 GB services + ~1 GB OS/Docker |
| **Total Typical** | **~1.4-1.6 GB of 16 GB** | **~2.8-4.2 GB of 16 GB** |
| **Max (limits)** | ~1.2 GB (limits) + 1.2 GB (OS) = ~2.4 GB | ~6.2 GB (limits) + 1.2 GB (OS) = ~7.4 GB |
| **Headroom** | ~13.6 GB free | ~8.6 GB free |
| **Verdict** | Well within limits | Within limits; Monero sync period is the tightest |

---

## Complete Consolidated Hardware BOM

> **Full ordering reference:** See `HARDWARE_BOM.md` for the complete BOM with ASINs, verified pricing, rack layout, power budget, and thermal notes.

### Budget Build (~$889) -- Single Pi 5, Minimal Extras

> **Availability note:** RackMate T1 and 2U Touchscreen SOLD OUT at DeskPi.com (Feb 2026). Check Amazon ASINs. All prices verified Feb 2026.

| # | Category | Component | Model | Qty | Unit Price | Total | Notes |
|---|---|---|---|-----|---|---|---|
| 1 | Enclosure | 8U Rack Cabinet | GeeekPi DeskPi RackMate T1 | 1 | $119.99 | $119.99 | SOLD OUT DeskPi; Amazon B0CPLRD29P |
| 2 | Display | 2U Touchscreen | GeeekPi 7.84" 1280x400 LCD | 1 | $79.99 | $79.99 | SOLD OUT DeskPi; Amazon B0F3C5R2BZ |
| 3 | Cooling | 120mm USB Fan | GeeekPi RackMate Fan | 1 | $13 | $13 | 3-speed |
| 4 | Compute | Pi 5 16GB Board | Raspberry Pi 5 16GB | 1 | $205.00 | $205.00 | Confirmed PiShop.us Feb 2026 |
| 4a | Compute | Pi 5 Active Cooler | Official Raspberry Pi Active Cooler | 1 | $10.95 | $10.95 | Confirmed PiShop.us |
| 4b | Power | USB-C 27W PSU | USB-C PD 27W adapter | 1 | $12 | $12 | Required; 5V/5A |
| 5 | Storage | 1TB SATA SSD | Crucial BX500 CT1000BX500SSD1 | 1 | $123.99 | $123.99 | Confirmed Newegg Feb 2026 |
| 6 | Storage | USB-SATA Adapter | SABRENT EC-SSHD | 1 | $10 | $10 | USB 3.0 |
| 7 | Network | 8-Port Switch | TP-Link TL-SG108S | 1 | $27 | $27 | ~$26-28 confirmed Feb 2026 |
| 8 | Rack | 1U Switch Shelf | GeeekPi 1U Vented Shelf | 1 | $17 | $17 | Cantilever tray |
| 9 | Power | 1U Rack PDU | Tupavco TP1713 | 1 | $35 | $35 | 4 outlet, surge |
| 10 | Power | UPS | Tripp Lite INTERNET350U | 1 | $94.99 | $94.99 | Confirmed Newegg Feb 2026 |
| 11 | Network | Travel Router | GL.iNet Slate AX (AXT1800) | 1 | $119.99 | $119.99 | Confirmed GL.iNet store Feb 2026 |
| 12 | Storage | MicroSD Card | SanDisk Extreme 32GB A2 | 1 | $10 | $10 | Boot/recovery |
| 13 | Cable | Ethernet Cables | Cat6 6" 5-pack | 1 | $10 | $10 | Rack wiring |
| | | | | | **TOTAL** | **~$889** | Prices verified Feb 2026 |

### Recommended Build (~$1,385–$1,425) -- Dual Pi 5, NVMe Both Nodes, BC600R UPS Inside Rack, LabStack Panels

> **Availability note:** RackMate T1 and 2U Touchscreen SOLD OUT at DeskPi.com (Feb 2026). Check Amazon. Official Pi SSDs OUT OF STOCK — use WD SN740 (Pi #1) and Crucial P310 (Pi #2). **⚠️ Verify all prices before ordering — 2230 NVMe market is volatile.**

| # | Category | Component | Model | Qty | Est. Price | Total | Notes |
|---|---|---|---|-----|---|---|---|
| 1 | Enclosure | 8U Rack Cabinet | GeeekPi DeskPi RackMate T1 | 1 | $119.99 | $119.99 | SOLD OUT DeskPi; Amazon B0CPLRD29P |
| 2 | Display | 2U Touchscreen | GeeekPi 7.84" LCD Touch | 1 | $79.99 | $79.99 | SOLD OUT DeskPi; Amazon B0F3C5R2BZ |
| 3 | Cooling | 120mm USB Fan | GeeekPi RackMate Fan | 2 | $13 | $26 | Push-pull airflow |
| 4 | Compute | Pi 5 16GB Board #1 | Raspberry Pi 5 16GB | 1 | $205.00 | $205.00 | Node #1: Matrix, Tor, I2P; PiShop.us confirmed |
| 5 | Compute | Pi 5 Active Cooler #1 | Official Raspberry Pi Active Cooler | 1 | $10.95 | $10.95 | PiShop.us confirmed |
| 6 | Compute | Pi 5 16GB Board #2 | Raspberry Pi 5 16GB | 1 | $205.00 | $205.00 | Node #2: Monero, ATAK, Reticulum |
| 7 | Compute | Pi 5 Active Cooler #2 | Official Raspberry Pi Active Cooler | 1 | $10.95 | $10.95 | PiShop.us confirmed |
| 8 | Rack+NVMe | 1U Dual Pi 5 Mount | GeeekPi B0F7XBVV4D | 1 | ~$60 | ~$60 | Both Pi 5s in 1U; built-in PCIe NVMe adapters for each |
| 9 | Storage | Pi #1 NVMe SSD 256GB | WD SN740 256GB M.2 2230 OEM (B0C6MVP42M) | 1 | ~$40 | ~$40 | Verify price; Official Pi SSD 256GB OOS ($75) |
| 10 | Storage | Pi #2 NVMe SSD 1TB | Crucial P310 1TB M.2 2230 (CT1000P310SSD2) | 1 | ~$115-150 | ~$130 | In stock Feb 2026; verify price |
| 11 | Power | GaN Multi-Port Charger | Anker 747 GaNPrime 150W (B09W2PNLX7) | 1 | ~$65 | ~$65 | 150W pool; C1→Pi#1 (27W), C2→Pi#2 (27W), C3→GL.iNet (15W), USB-A→display; 1 PDU outlet |
| 12 | Network | 8-Port Switch | TP-Link TL-SG108S | 1 | $27 | $27 | ~$26-28 confirmed Feb 2026 |
| 13 | Rack | 1U Switch Shelf | GeeekPi 1U Vented Shelf | 1 | $17 | $17 | Switch + GL.iNet side by side |
| 14 | Power | 1U Rack PDU | Tupavco TP1713 | 1 | $35 | $35 | 4 outlet, surge |
| 15 | Power | UPS | Tripp Lite BC600R 600VA | 1 | ~$70 | ~$70 | Sits on rack floor strapped; 10.04"×7.09"×2.28" |
| 16 | Network | Travel Router | GL.iNet Slate AX (AXT1800) | 1 | $119.99 | $119.99 | Confirmed GL.iNet store Feb 2026 |
| 17 | Radio | LoRa USB — RNode | Heltec WiFi LoRa 32 V3 915MHz | 1 | $19.90 | $19.90 | LEFT panel position; flash with RNode firmware |
| 18 | Radio | LoRa USB — Mesh | Heltec WiFi LoRa 32 V3 915MHz | 1 | $19.90 | $19.90 | heltec.org confirmed; Meshtastic |
| 19 | Radio | LoRa Antennas | 915 MHz SMA, 2-pack | 1 | $12 | $12 | One per radio |
| 20 | Storage | MicroSD Card x2 | SanDisk Extreme 32GB A2 | 2 | $10 | $20 | Boot/recovery for both Pi nodes |
| 21 | Cable | Ethernet Cables | Cat6 6" 5-pack | 1 | $10 | $10 | Rack cable management |
| 22 | Cable | Micro HDMI Adapters | 2-pack | 1 | $8 | $8 | For both Pi 5 nodes |
| 23 | Cable | USB-A to USB-C Cables | 1ft, 2-pack | 1 | $8 | $8 | LoRa radios directly to Pi #2 USB 3.0 ports |
| 24 | Cable | Velcro Cable Ties | 50-pack | 1 | $6 | $6 | Cable management + BC600R floor straps |
| 25 | Rack | 1U Vented Blank | GeeekPi 1U Blank | 1 | $10 | $10 | U1 bottom intake |
| 26 | Rack | LabStack SMA Panel | 1U Mini 2x Keystone 2x SMA Right Mount (3D print) | 1 | ~$2 | ~$2 | github.com/JaredC01/LabStack; U4 front rails |
| 27 | Radio | SMA Bulkhead Connectors | SMA female chassis mount, 2-pack | 1 | ~$8 | ~$8 | Panel feedthroughs for LoRa antennas |
| 28 | Radio | SMA Jumper Cables | SMA male-to-male RG316, 6–12", 2-pack | 1 | ~$8 | ~$8 | Radio board to panel interior connection |
| 29 | Rack | LabStack Rear Fan Panel | 2U Mini 2x 80mm Fan Panel (3D print) | 1 | ~$2 | ~$2 | github.com/JaredC01/LabStack; U4-U5 rear rails |
| 30 | Cooling | 80mm USB Fans | GDSTIME / ELUTENG 80mm USB 5V, 2-pack | 1 | ~$15 | ~$15 | Rear exhaust behind Pi nodes; U4-U5 rear |
| | | | | | **TOTAL** | **~$1,385–$1,425** | ⚠️ Verify SSD prices before ordering |

### Premium Build (~$1,705–$1,785) -- Managed Switch, Second SSD, Cellular, Case

| # | Category | Component | Model | Qty | Unit Price | Total | Notes |
|---|---|---|---|-----|---|---|---|
| 1-30 | | All Recommended items | (see above) | | | ~$1,385–$1,425 | |
| 31 | Network | Switch Upgrade | TP-Link TL-SG108E (managed) | 1 | +$10 | +$10 | VLAN support, QoS, port mirroring; replaces #12 |
| 32 | Storage | Expansion USB SSD | Samsung T7 1TB USB 3.2 | 1 | ~$90 | ~$90 | Pi #2 backups/overflow via USB; no adapter needed |
| 33 | Network | USB Cellular Modem | Quectel RM520N-GL (5G) | 1 | $85 | $85 | Field cellular backhaul |
| 34 | Transport | Carrying Case | Pelican 1610 Protector Case | 1 | $180–$220 | $200 | Interior 21.78"×16.69"×10.62" — fits T1 rack (11"W×7.8"D×16"H) laid flat with UPS attached; ~2.8" depth clearance for foam |
| 35 | Transport | Kaizen Foam Insert | 2" thick, custom-cut | 1 | $20 | $20 | Shock protection; cut to rack profile |
| | | | | | **TOTAL** | **~$1,705–$1,785** | Prices verified Feb 2026 |

### Optional: LoRa Radio Add-on Kit (~$66 for node, ~$28-40 per member)

| Item | Purpose | Price |
|---|---|---|
| Heltec V3 × 1 | RNode for Reticulum LoRa (LEFT panel position) | $19.90 |
| Heltec V3 x1 | Meshtastic node (MQTT bridge) | $18 |
| 915 MHz antenna x2 | One per radio | $20 |
| USB-A to USB-C cables x2 | Connect radios to Pi | $8 |
| **Node radio subtotal** | | **~$66** |

Per community member: Heltec V3 or T-Beam ($18-30) + antenna ($10) = **~$28-40 each**

### Optional: Solar Field Kit (~$335-505)

| Component | Specification | Price |
|---|---|---|
| LiFePO4 Battery | 12V 100Ah (1,280Wh) | $200-300 |
| Solar Panel | 100W monocrystalline, foldable | $80-120 |
| Solar Charge Controller | 20A MPPT | $40-60 |
| 12V to 5V DC-DC Converter | Buck converter, 10A, USB-C PD | $15-25 |
| **Solar kit subtotal** | | **~$335-505** |

---

## Docker Compose Master Stack

This is the consolidated `docker-compose.yml` combining all services from all four specialist reports into a single coherent stack. In the recommended 2-node build, this file is split across both Pi 5s. The compose file below represents the complete logical stack; deploy the appropriate services section on each node.

### Pi 5 Node #1 -- docker-compose.yml (Comms)

```yaml
# =============================================================================
# Mission 2 Community Node -- Pi 5 #1 (Primary Communications)
# File: /opt/community-node/docker-compose.yml
# =============================================================================

networks:
  community-net:
    driver: bridge
    ipam:
      config:
        - subnet: 172.20.0.0/24
  tor-net:
    driver: bridge
    internal: true
  i2p-net:
    driver: bridge
    internal: true

volumes:
  conduit-data:
  i2pd-data:
  tor-data:
  element-web:

services:
  # ==== MATRIX SERVER - Conduit (Rust) ====
  conduit:
    image: matrixconduit/matrix-conduit:${CONDUIT_VERSION:-v0.10.12}
    container_name: conduit
    restart: unless-stopped
    environment:
      CONDUIT_SERVER_NAME: ${MATRIX_SERVER_NAME:-community.local}
      CONDUIT_DATABASE_BACKEND: rocksdb
      CONDUIT_DATABASE_PATH: /var/lib/conduit/db
      CONDUIT_PORT: 6167
      CONDUIT_ADDRESS: 0.0.0.0
      CONDUIT_ALLOW_REGISTRATION: "false"  # set true only for events; use registration_token
      CONDUIT_REGISTRATION_TOKEN: ${REGISTRATION_TOKEN}
      CONDUIT_ALLOW_FEDERATION: "true"
      CONDUIT_TRUSTED_SERVERS: '["matrix.org"]'
      CONDUIT_MAX_REQUEST_SIZE: 20000000
      CONDUIT_LOG: info
    volumes:
      - conduit-data:/var/lib/conduit
    networks:
      community-net:
        ipv4_address: 172.20.0.10
      tor-net:
      i2p-net:
    deploy:
      resources:
        limits:
          memory: 512M
        reservations:
          memory: 128M
    healthcheck:
      test: ["CMD", "curl", "-f", "http://localhost:6167/_matrix/client/versions"]
      interval: 30s
      timeout: 10s
      retries: 3

  # ==== ELEMENT WEB - Matrix Client ====
  element-web:
    image: vectorim/element-web:${ELEMENT_VERSION:-v1.12.11}
    container_name: element-web
    restart: unless-stopped
    volumes:
      - ./config/element/element-config.json:/app/config.json:ro
    networks:
      community-net:
        ipv4_address: 172.20.0.11
    deploy:
      resources:
        limits:
          memory: 64M
        reservations:
          memory: 32M
    depends_on:
      conduit:
        condition: service_healthy

  # ==== NGINX - Reverse Proxy ====
  nginx:
    image: nginx:1.28.2-alpine3.23
    container_name: nginx
    restart: unless-stopped
    ports:
      - "80:80"
      - "443:443"
      - "8448:8448"
      - "8080:8080"
      - "8081:8081"
    volumes:
      - ./config/nginx/nginx.conf:/etc/nginx/nginx.conf:ro
      - ./config/nginx/ssl:/etc/nginx/ssl:ro
      - ./data/community-web:/var/www/community:ro
    networks:
      community-net:
        ipv4_address: 172.20.0.2
      tor-net:
      i2p-net:
    deploy:
      resources:
        limits:
          memory: 128M
        reservations:
          memory: 32M
    depends_on:
      - conduit
      - element-web

  # ==== I2PD - I2P Router (C++) ====
  i2pd:
    image: purplei2p/i2pd:${I2PD_VERSION:-release-2.59.0}
    container_name: i2pd
    restart: unless-stopped
    ports:
      - "7070:7070"
      - "4444:4444"
      - "4447:4447"
      - "7656:7656"
    volumes:
      - i2pd-data:/var/lib/i2pd
      - ./config/i2pd/i2pd.conf:/etc/i2pd/i2pd.conf:ro
      - ./config/i2pd/tunnels.conf:/etc/i2pd/tunnels.conf:ro
    networks:
      community-net:
        ipv4_address: 172.20.0.20
      i2p-net:
    deploy:
      resources:
        limits:
          memory: 256M
        reservations:
          memory: 64M

  # ==== TOR - Hidden Services ====
  tor:
    image: osminogin/tor-simple:0.4.8.21
    container_name: tor
    restart: unless-stopped
    volumes:
      - tor-data:/var/lib/tor
      - ./config/tor/torrc:/etc/tor/torrc:ro
    networks:
      community-net:
        ipv4_address: 172.20.0.30
      tor-net:
    deploy:
      resources:
        limits:
          memory: 128M
        reservations:
          memory: 32M
    depends_on:
      - nginx

  # ==== CLOUDFLARE TUNNEL - Clearnet Access ====
  cloudflared:
    image: cloudflare/cloudflared:2026.2.0
    container_name: cloudflared
    restart: unless-stopped
    command: tunnel run
    environment:
      TUNNEL_TOKEN: ${CLOUDFLARE_TUNNEL_TOKEN}
    volumes:
      - ./config/cloudflared/config.yml:/etc/cloudflared/config.yml:ro
    networks:
      community-net:
        ipv4_address: 172.20.0.40
    deploy:
      resources:
        limits:
          memory: 128M
        reservations:
          memory: 32M
    depends_on:
      - nginx
    profiles:
      - clearnet
      - full
```

### Pi 5 Node #2 -- docker-compose.yml (Tactical/Crypto)

```yaml
# =============================================================================
# Mission 2 Community Node -- Pi 5 #2 (Tactical / Crypto)
# File: /opt/community-node/docker-compose.yml
# =============================================================================

volumes:
  reticulum-config:
  nomadnet-data:
  mosquitto-config:
  mosquitto-data:
  mosquitto-log:
  headscale-config:
  headscale-data:
  monero-data:
    driver: local
    driver_opts:
      type: none
      o: bind
      device: /mnt/ssd/monero/data
  monero-tor-data:
  wallet-data:
    driver: local
    driver_opts:
      type: none
      o: bind
      device: /mnt/ssd/monero/wallets

services:
  # ==== OpenTAK Server — Situational Awareness ====
  # OTS runs NATIVELY under systemd — NOT in Docker.
  # Install: see BUILD_GUIDE.md Phase 5B
  # Status: systemctl status opentakserver
  # Ports: 8080 (HTTP UI), 8088 (CoT TCP), 8089 (CoT SSL),
  #        8443 (HTTPS UI), 8446 (cert enrollment)

  # ==== Reticulum Daemon - Encrypted Mesh Transport ====
  # WARNING: runs pip install on every startup. In air-gap/offline mode this will fail
  # on cold start. Ensure at least one successful internet-connected startup before
  # deploying air-gap. Long-term fix: build a custom image with packages baked in.
  reticulum:
    image: python:3.12.12-slim-bookworm
    container_name: reticulum-node
    restart: unless-stopped
    network_mode: host
    command: >
      bash -c "
        pip install --quiet rns nomadnet lxmf &&
        rnsd
      "
    volumes:
      - reticulum-config:/root/.reticulum
      - nomadnet-data:/root/.nomadnetwork
    devices:
      - /dev/ttyUSB0:/dev/ttyUSB0
    # Ports (host): 4242, 37428

  # ==== NomadNet - Terminal BBS / Messaging ====
  nomadnet:
    image: python:3.12.12-slim-bookworm
    container_name: nomadnet
    restart: unless-stopped
    network_mode: host
    command: >
      bash -c "
        pip install --quiet nomadnet &&
        nomadnet --daemon
      "
    volumes:
      - reticulum-config:/root/.reticulum
      - nomadnet-data:/root/.nomadnetwork
    depends_on:
      - reticulum

  # ==== Mosquitto MQTT - Meshtastic Bridge ====
  mosquitto:
    image: eclipse-mosquitto:2.1.2
    container_name: mosquitto
    restart: unless-stopped
    ports:
      - "1883:1883"
      - "9001:9001"
    volumes:
      - mosquitto-config:/mosquitto/config
      - mosquitto-data:/mosquitto/data
      - mosquitto-log:/mosquitto/log

  # ==== Monerod - Pruned Public Node ====
  monerod:
    image: ghcr.io/sethforprivacy/simple-monerod:v0.18.4.5
    container_name: monerod
    restart: unless-stopped
    user: "${FIXUID:-1000}:${FIXGID:-1000}"
    volumes:
      - monero-data:/home/monero/.bitmonero
    ports:
      - "18080:18080"
      # SECURITY: RPC bound to localhost only — access via Tailscale/Headscale VPN
      # 18089 NOT exposed to Docker host; remove port mapping if network_mode: host
    command:
      - --rpc-restricted-bind-ip=127.0.0.1
      - --rpc-restricted-bind-port=18089
      # Removed: --confirm-external-bind (not needed for localhost bind)
      # Removed: --public-node (incompatible with localhost-only RPC)
      - --no-igd
      - --prune-blockchain
      - --db-sync-mode=safe:sync
      - --enable-dns-blocklist
      - --out-peers=32
      - --in-peers=64
      - --limit-rate-up=1048576
      - --limit-rate-down=1048576
      - --log-level=0
      - --max-log-file-size=10485760
      - --max-log-files=3
    deploy:
      resources:
        limits:
          memory: 4G
          cpus: "2.0"
        reservations:
          memory: 1G
          cpus: "0.5"
    healthcheck:
      test: ["CMD-SHELL", "curl -sf http://127.0.0.1:18089/get_info || exit 1"]
      # 18089 = restricted RPC (the port actually bound by --rpc-restricted-bind-port)
      # 18081 = unrestricted full RPC (not opened — healthcheck was wrong)
      interval: 60s
      timeout: 10s
      retries: 3
      start_period: 300s
    logging:
      driver: json-file
      options:
        max-size: "10m"
        max-file: "3"

  # ==== Monero Tor Proxy (for anonymous tx relay) ====
  monero-tor:
    image: osminogin/tor-simple:0.4.8.21
    container_name: monero-tor
    restart: unless-stopped
    volumes:
      - monero-tor-data:/var/lib/tor
      - ./torrc-monero:/etc/tor/torrc:ro
    ports:
      - "127.0.0.1:9050:9050"
    deploy:
      resources:
        limits:
          memory: 256M
          cpus: "0.5"
    profiles:
      - full
      - tor-monero

  # ==== Monero Wallet RPC (optional) ====
  monero-wallet-rpc:
    image: ghcr.io/sethforprivacy/simple-monerod:v0.18.4.5
    container_name: monero-wallet-rpc
    restart: unless-stopped
    user: "${FIXUID:-1000}:${FIXGID:-1000}"
    entrypoint: monero-wallet-rpc
    volumes:
      - wallet-data:/home/monero/wallets
    ports:
      - "127.0.0.1:18082:18082"
    command:
      - --rpc-bind-port=18082
      - --rpc-bind-ip=0.0.0.0
      - --confirm-external-bind
      - --daemon-address=monerod:18081
      - --wallet-dir=/home/monero/wallets
      - --rpc-login=${WALLET_RPC_USER:-monero}:${WALLET_RPC_PASS:-changeme}
    depends_on:
      monerod:
        condition: service_healthy
    deploy:
      resources:
        limits:
          memory: 512M
          cpus: "0.5"
    profiles:
      - wallet

  # ==== Headscale - Self-Hosted Tailscale Control (Optional) ====
  headscale:
    # ⚠️ Breaking changes from 0.23 to 0.28 — read release notes before upgrading
    image: headscale/headscale:0.28.0
    container_name: headscale
    restart: unless-stopped
    ports:
      - "8180:8080"
      - "50443:50443"
    volumes:
      - headscale-config:/etc/headscale
      - headscale-data:/var/lib/headscale
    command: headscale serve
    environment:
      - TZ=${TZ:-America/New_York}
    profiles:
      - headscale
      - full
```

### Compose Profiles Summary

| Profile | Services Started | Use Case |
|---|---|---|
| (default) | All core services except profiled ones | Normal operation |
| `clearnet` | + Cloudflared | Internet-connected, public access |
| `full` | + Cloudflared + Monero Tor + Headscale | Everything running |
| `tor-monero` | + Monero Tor proxy | Anonymous Monero relay |
| `wallet` | + Monero Wallet RPC | Programmatic wallet access |
| `headscale` | + Headscale control server | Self-hosted VPN coordination |

**Launch examples:**
```bash
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

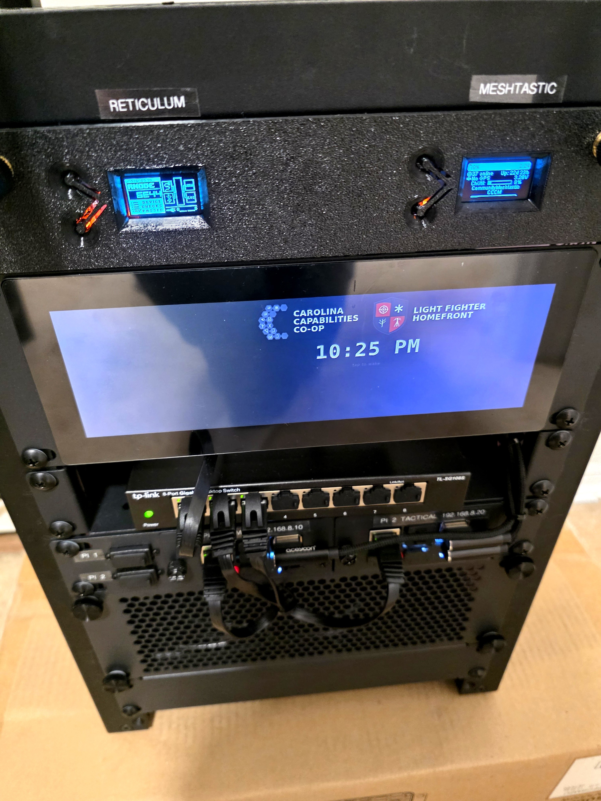
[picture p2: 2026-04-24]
community-outreach/assets/node-detail-2.jpg

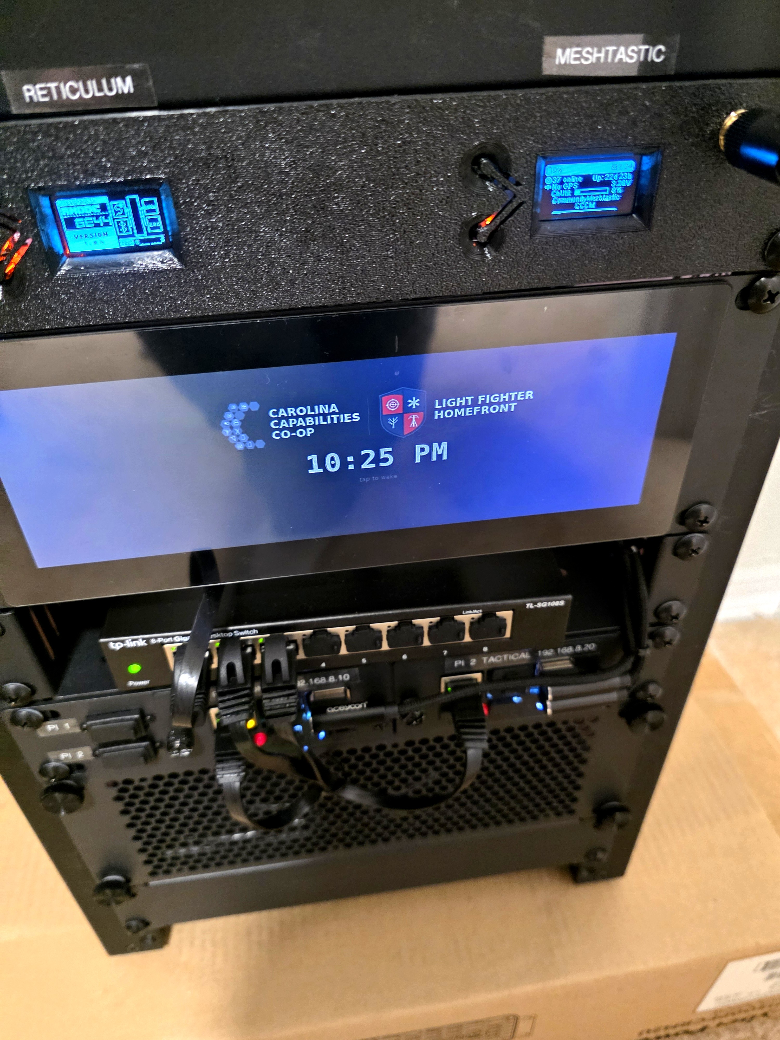
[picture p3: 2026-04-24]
community-outreach/assets/node-detail-1.jpg

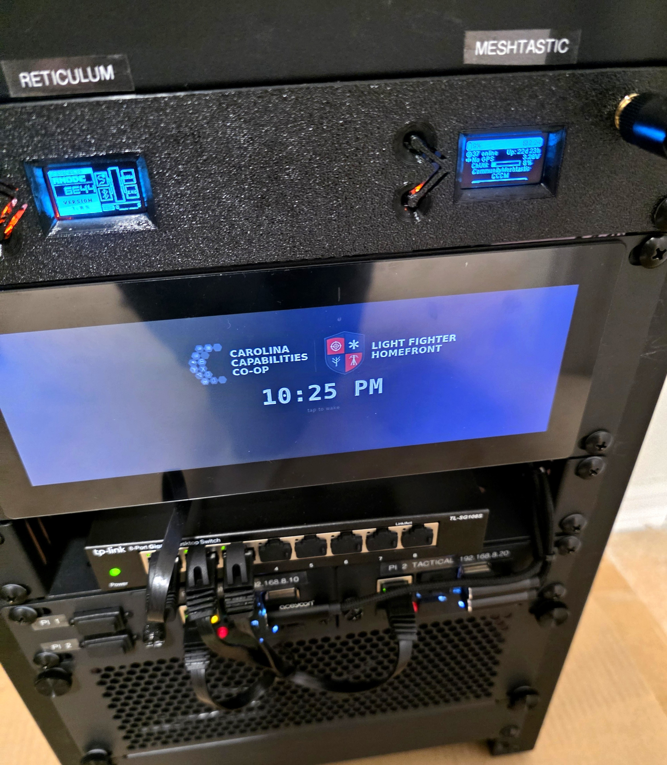
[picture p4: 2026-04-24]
community-outreach/assets/node-ccc.jpg

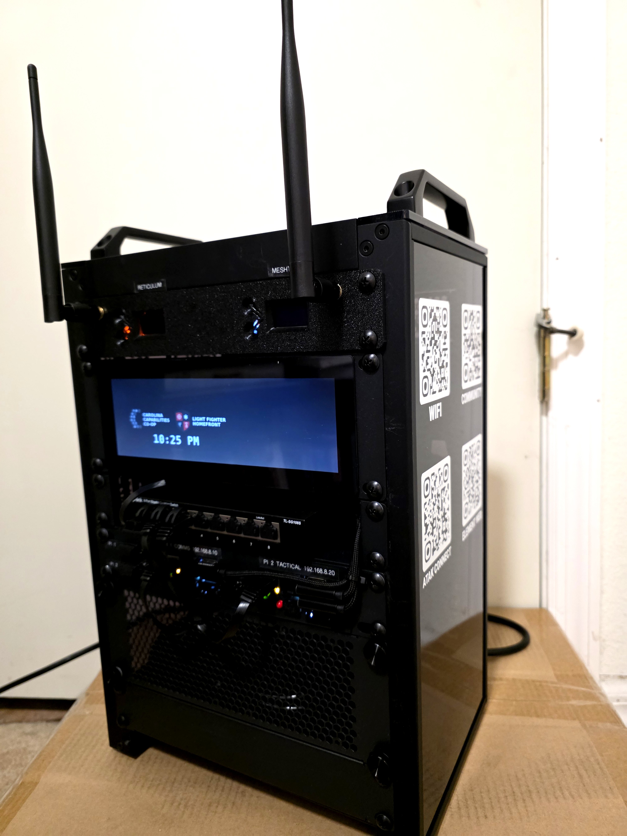
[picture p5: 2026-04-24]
community-outreach/assets/node-top.jpg

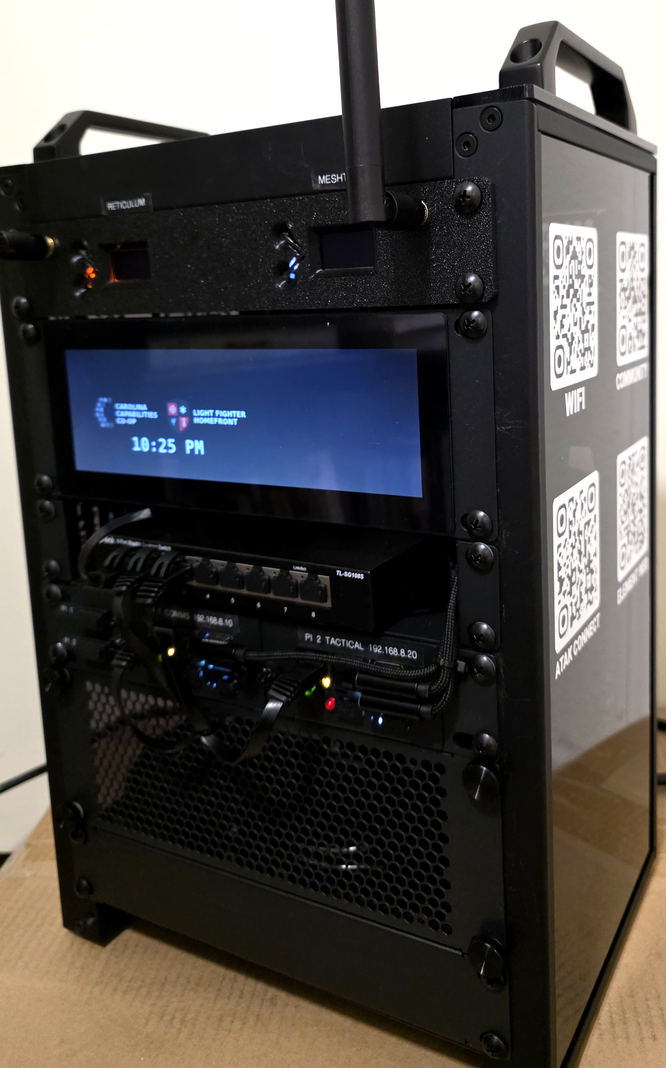
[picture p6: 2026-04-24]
community-outreach/assets/node-side.jpg

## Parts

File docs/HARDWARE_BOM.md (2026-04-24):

# Mission 2 - Community Node: Mini-Rack Hardware BOM & Specification

> **Portable 10" Mini-Rack Community Node**
> Inspired by [Jeff Geerling's Project MINI RACK](https://mini-rack.jeffgeerling.com/) -- compact, portable homelabs in a 10" form factor.
>
> **Not building with Pi 5 16GB?** See [BUILD_OPTIONS.md](BUILD_OPTIONS.md) for Pi 4, mini PC, single-device, and no-Monero hardware alternatives.

---

## 1. Bill of Materials - Validation & Expansion

### 1.1 Core Components (User-Specified) - Validation

#### GeeekPi 8U Server Cabinet (DeskPi RackMate T1)
- **Model:** B0CSCWVTQ7 | **Price:** ~$90-100 (Amazon)
- Aluminum alloy + acrylic frame. 16" × 11" × 7.87" (H × W × D). 236.5mm rail spacing. 8U usable.
- **Note:** T1 Plus ($110-120) offers 10.23" depth; standard T1 sufficient for this build.

#### GeeekPi 2U 7.84" Touchscreen
- **Model:** B0F3C5R2BZ | **Price:** ~$65-75 (Amazon)
- 1280×400 LCD capacitive. Connects via HDMI + USB (touch). Draws ~8W; power off to extend UPS runtime.

#### GeeekPi 120mm USB Fan
- **Model:** B0DS2D8M2F | **Price:** ~$12-15 (Amazon)
- L/M/H 3-speed, USB 5V. Shares U8 with LoRa panel — fan on rear rails, panel on front rails. Recommended build uses 2× for push-pull.

#### Raspberry Pi 5 16GB + Active Cooler
- **This build:** Pi 5 16GB board-only (**$205.00 confirmed PiShop.us, Feb 2026**, in stock) + Official Pi 5 Active Cooler (**$10.95 PiShop.us**, in stock). Powered via Anker 747 GaN charger (see §1.2).
- **Note:** CanaKit Starter Kit MAX (B0DRTNTLD5, ~$340) is an alternative bundle but is not the chosen configuration for this build.

#### NVMe SSD for Pi #1 (256GB M.2 2230)
- **Chosen:** WD SN740 256GB M.2 2230 NVMe OEM (ASIN B0C6MVP42M) — **~$35-45 Amazon** — IN STOCK
  - PCIe Gen 4 (throttles to Gen 3 on Pi 5); confirmed Pi 5 compatible.
- **Alternative:** Official Raspberry Pi SSD 256GB (SC1983) — $75 PiShop.us — ⚠️ **OUT OF STOCK Feb 2026**
- **Note:** Enable PCIe Gen 3: add `dtparam=pciex1_gen=3` to `/boot/firmware/config.txt`.

#### NVMe SSD for Pi #2 (1TB M.2 2230)
- **Chosen:** Crucial P310 1TB M.2 2230 NVMe (CT1000P310SSD2) — **~$115-150 Amazon/Newegg/Micro Center** — ✅ IN STOCK
  - PCIe Gen 4 (throttles to Gen 3 on Pi 5); no Pi 5 compatibility issues reported.
- **Alternative:** Official Raspberry Pi SSD 1TB (SC1984) — $120 PiShop.us — ⚠️ **OUT OF STOCK Feb 2026**
- **Performance vs. USB SATA:** 3.5–7× better random IOPS (29K USB → 106K–197K NVMe). Required for Monero LMDB performance.
- **⚠️ Verify price before ordering** — 2230 NVMe prices are volatile due to Steam Deck/handheld demand.

#### TP-Link TL-SG108S 8-Port Gigabit Switch
- **Model:** TL-SG108S | **Price:** ~$26-28 (CompSource ~$26.80 confirmed Feb 2026)
- Unmanaged, fanless, metal housing. Sufficient for this build (router, 2× Pi, touchscreen, 2-3 spare ports).
- **Note:** For VLAN support, TL-SG108E (~$37) adds web UI management — see Premium BOM item 31.

#### 1U Rack Mount for Switch
- **Model:** GeeekPi 1U Shelf (B0D5XMM7HL or similar) | **Price:** ~$15-20 (Amazon)
- Vented cantilever shelf for switch + GL.iNet side by side.

#### 1U Rack PDU (10" Form Factor)
- **Model:** Tupavco TP1713 | **Price:** ~$30-40 (Amazon)
- 4-outlet, surge-protected, 10" form factor. Count AC adapters before ordering — this build uses 2 outlets (GaN charger + switch).
- **Alternative:** DeskPi DC PDU Lite (~$25) — 0.5U DC distribution for SBC builds.

#### Tripp Lite BC600R (600VA/300W) — Recommended UPS
- **Model:** BC600R | **Price:** **~$70 (DigiKey confirmed)** — also Amazon/CDW; verify before ordering
- 600VA/300W. Dimensions: 10.04"×7.09"×2.28" — fits on the RackMate T1 floor, secured with velcro.
- **Runtime:** ~138 min at idle (26W), ~103 min at typical (35W), ~74 min at full load (48.5W).
- **Budget alternative:** Tripp Lite INTERNET350U (~$94.99 Newegg Feb 2026) — 350VA/210W, external only, ~86 min typical.

#### GL.iNet Slate AX (GL-AXT1800)
- **Model:** GL-AXT1800 | **Price:** **$119.99 confirmed (GL.iNet official store, Feb 2026)** — in stock
- WiFi 6, OpenWrt, WireGuard + Tailscale native, IPQ6000 1.2GHz quad-core. Network gateway for the rack.
- **Note:** GL.iNet Flint 2 (~$160) if 2.5GbE or more LAN ports are needed; Slate AX is more portable.

#### Tailscale (Software)
- **Price:** Free (up to 100 devices). Zero-config mesh VPN. Runs on GL.iNet, Pi nodes, and all clients.

---

### 1.2 Recommended Additional Components

#### Raspberry Pi 5 16GB — Node #2 (Dual Pi 5 Build)
- **Price:** **$205.00 confirmed (PiShop.us, Feb 2026)** — in stock
- Broadcom BCM2712 Cortex-A76 4-core 2.4GHz, 16GB LPDDR4X, 2× USB 3.0, 2× USB 2.0, ~3.5W idle / ~10W load.
- Powered via Anker 747 GaN charger (C2 port, 27W). Active Cooler $10.95 PiShop.us.
- **Monero sync:** Initial sync takes 2–4 weeks on ARM natively. Use the **pre-sync workaround** (Phase 0.1): sync LMDB on an x86 machine, rsync to Pi over the network — reduces field-deploy wait to near zero.
- **Note:** GPIO header supports optional Waveshare SX1262 LoRa HAT as alternative to USB radios.

#### GeeekPi 1U Dual Pi 5 Mount (Both Nodes — NVMe Included)
- **Model:** B0F7XBVV4D | **Price:** ~$50-70 (Amazon)
- Mounts both Pi 5s in a single 1U bracket with 2× built-in PCIe→M.2 NVMe adapters (2230/2242/2260/2280). Eliminates a separate M.2 HAT+; saves 1U vs two individual shelves.
- **NVMe performance:** Gen 2 default (~106K IOPS 4K); Gen 3 with `dtparam=pciex1_gen=3` → ~197K IOPS.

#### LoRa Modules for Reticulum/Meshtastic (2× Heltec V3)
- **Heltec WiFi LoRa 32 V3 915MHz × 2** — **$19.90 each confirmed (heltec.org, Feb 2026)** ($26.97 via Rokland US): 50.2×25.5mm, 0.96" OLED, ESP32-S3, USB-C. Both boards are identical hardware — differentiated by firmware and panel position:
  - **LEFT position (ANT 1):** Flash with **RNode firmware** (Mark Qvist / unsigned.io) for Reticulum encrypted mesh transport. → Pi #2 USB 2.0 port 1 (`/dev/ttyUSB0`).
  - **RIGHT position (ANT 2):** Flash with **Meshtastic firmware** for consumer LoRa mesh. → Pi #2 USB 2.0 port 2 (`/dev/ttyUSB1`).
- **Antenna connector:** ⚠️ **IPEX (U.FL) ONLY on both boards** — no SMA connector. Both require U.FL-to-SMA pigtail (item 28) for panel bulkhead connection.
- Both boards mount directly to the custom 1U LoRa panel (item 26) via M2 nylon standoffs (item 28a), with OLEDs aligned behind panel cutout windows. Both assigned to Node #2 — keeps Node #1 (Matrix/Tor/I2P) free of LoRa overhead.
- **Alternative GPIO HAT:** Waveshare SX1262 915M LoRa HAT (~$20-25, Amazon) — if onboard radio preferred over USB.

#### LabStack 2U 80mm Rear Fan Panel (3D Print — Recommended Build)
- **Source:** github.com/JaredC01/LabStack — "2U Mini 2x 80mm Fan Panel" STL
- **Price:** ~$2-3 filament (PETG or PLA+), ~1.5h print; plus ~$15 for 2× 80mm USB 5V fans
- Mounts 2× 80mm fans on **rear** rails at U2-U3, directly behind the Pi 5 node bay. Creates rear exhaust complementing the top 120mm fan — dual exhaust path for sustained-load Pi cooling.
- **Fan spec:** 80mm × 25mm, 5V USB (GDSTIME, ELUTENG, or similar). USB cables route to the USB fan hub at U3 (item 30g).
- Same 10" 236.5mm rail standard as RackMate T1; no modification needed.

#### Micro HDMI to HDMI Cables
- **Price:** ~$8-10 for 2-pack (Amazon). Pi 5 board-only purchase — buy these separately (1ft–2ft).

#### MicroSD Card (Boot Media)
- **Model:** SanDisk Extreme 32GB A2 | **Price:** ~$10-12 (Amazon)
- OS boot and recovery fallback for each Pi. Even with NVMe as primary, keep microSD in slot.

#### Short Ethernet Cables (Cat6, 6-inch to 1-foot)
- **Price:** ~$10-12 for 5-pack (Amazon). Standard cables are too long for a 10" rack.

#### Power Distribution — Anker 747 GaNPrime 150W GaN Charger
- **Model:** Anker 747 GaNPrime 150W, ASIN B09W2PNLX7, ~$65 (Amazon)
- Replaces individual USB-C adapters for both Pi nodes and the GL.iNet. Switch still needs its own 12V DC barrel adapter.
- **Port assignment (4× USB-C + 2× USB-A):**
  - C1 → Pi #1 (27W) | C2 → Pi #2 (27W) | C3 → GL.iNet Slate AX (15W) | C4 → spare
  - USB-A 1 → touchscreen (~8W) | USB-A 2 → 120mm top exhaust fan U8 (~2W)
- **Power pool:** 150W total; simultaneous load ~79W; 71W headroom.
- **PDU outlet usage:** 1 outlet for GaN charger + 1 outlet for switch 12V adapter = 2 of 4 outlets used.
- **⚠️ USB-C cables not included:** Order "USB-C to USB-C, 1ft, 3-pack" separately (~$8–$10) — item 23a in the BOM.
- **Field note:** In solar/LiFePO4 deployments, use a 12V-to-USB-C PD buck converter (one per Pi 5) — no AC inverter needed.

---

## 2. 10" Rack Form Factor Analysis

### 2.1 GeeekPi 8U Cabinet Specifications

| Specification | Value |
|---|---|
| External Dimensions | 16" H x 11" W x 7.87" D |
| Internal Width | ~9.31" (236.5mm between rails) |
| Usable Depth | ~7" (after rail standoff) |
| Usable Height | 8U = 14" (355.6mm) |
| Weight (empty) | ~6 lbs |
| Material | Aluminum alloy frame, acrylic side panels |
| Mounting | Standard 10" rack screw pattern (M6) |

### 2.2 Rack Layout Diagram

#### Front View

```
+==========================================+
|          GeeekPi 8U RackMate T1          |
|          (Front View, Top-Down)          |
+==========================================+
|                                          |
|  U8  [ Custom 1U LoRa Panel (front)  ]   |  <-- 3D print: 2× OLED windows, 2× SMA bulkhead
|      [ Heltec V3 (L) + Heltec V3 (R)]   |     Antennas at top; 120mm fan shares U8 (rear rails)
|                                          |
|  U7  [                               ]   |
|      [ 2U Touchscreen (7.84" LCD)    ]   |  <-- Status dashboard / ATAK map
|  U6  [                               ]   |     HDMI from Pi #1; USB touch to Pi #1
|                                          |
|  U5  [ TP-Link TL-SG108S + GL.iNet  ]   |  <-- Switch + router on shared 1U shelf
|      [ (side by side on 1U shelf)   ]   |
|                                          |
|  U4  [ GeeekPi 1U Dual Pi 5 Mount   ]   |  <-- BOTH Pi 5s in a single 1U bracket
|      [ Pi #1 (Comms)  Pi #2 (TAK)   ]   |     Built-in PCIe NVMe adapters for each
|      [ 256GB NVMe     1TB NVMe      ]   |     Pi #1: Matrix/Tor/I2P | Pi #2: Monero/ATAK
|                                          |
|  U3  [ ---- OPEN ----               ]   |  <-- Available for future expansion
|                                          |
|  U2  [ ---- OPEN ----               ]   |  <-- PDU mounted on REAR rails (see rear view)
|                                          |
|  U1  [ Tripp Lite BC600R (UPS)       ]   |  <-- 600VA/300W; strapped inside rack at U1
|      [ 10.04"x7.09"x2.28"           ]   |     Fits within rack frame; velcro secured
|                                          |
+==========================================+
```

#### Rear View

```
+==========================================+
|          GeeekPi 8U RackMate T1          |
|          (Rear View, Top-Down)           |
+==========================================+
|                                          |
|  U8  [ 120mm USB Fan (rear rails)    ]   |  <-- Shares U8 with LoRa panel (front rails)
|      [ exhaust UP past antennas      ]   |     Open-frame: front+rear coexist at same U
|                                          |
|  U7  [ 2U Touchscreen rear (cables)  ]   |
|  U6  [                               ]   |
|                                          |
|  U5  [ Switch rear ports / GL.iNet   ]   |
|                                          |
|  U4  [ LabStack 2U 80mm Fan Panel    ]   |  <-- 3D print; U4-U3 rear rails
|      [ Fan 1 (80mm USB 5V exhaust)   ]   |     Pull hot Pi air out rearward
|  U3  [ Fan 2 (80mm USB 5V exhaust)   ]   |     Directly behind Pi 5 node bay (U4 front)
|      [ (fan panel continues)         ]   |
|                                          |
|  U2  [ 1U Rack PDU (rear rails)      ]   |  <-- Wings flipped, outlets face INWARD
|      [ outlets → rest on UPS body   ]   |     Adapters sit on BC600R top surface
|                                          |
|  U1  [ UPS rear (wall cable exit)    ]   |  <-- BC600R wall cable exits rear
|                                          |
+==========================================+
```

> **Airflow:** UPS at U1 blocks passive bottom intake — cool air enters from the open-frame sides and rear around U1-U2. 2× 80mm rear fans (U3-U4 rear) actively exhaust Pi node heat (U4 front) rearward → 120mm fan at U8 rear exhausts remaining rising heat upward past the LoRa panel's open sides. The open-frame T1 chassis provides adequate side ventilation even without a dedicated bottom intake panel.
>
> **Front/rear coexistence:** Open-frame RackMate T1 allows simultaneous front and rear mounting at the same U positions. U8: LoRa panel on front rails, 120mm fan on rear rails — no physical conflict. U4-U3: Pi mount on front rails (U4), LabStack 80mm fan panel on rear rails (U4-U3) — directly behind Pi heat source. U3 front is open, allowing the fan panel to extend down unobstructed.

### 2.3 Rack Layout Notes

- **U8 (Top, Front + Rear):** Custom 1U LoRa Panel on **front rails** + 120mm USB fan on **rear rails** — both share U8 via the open-frame chassis. The LoRa panel (3D print, black PETG) mounts both Heltec V3 boards on the panel's interior face using M2 × 8mm nylon standoffs, with their 0.96" OLED screens aligned behind rectangular cutout windows — status visible from the front without opening the rack. Two SMA female bulkhead connectors pass through the panel alongside the OLED windows. Short U.FL-to-SMA-male pigtail cables (6") connect each board's U.FL/IPEX RF connector directly to the interior side of its SMA bulkhead — no jumper cables needed. Both 915 MHz antennas mount externally on the panel bulkheads. The 120mm fan on the rear rails exhausts rising heat upward past the LoRa panel's open sides. **Antennas at the top of the rack for best RF propagation** — maximum height, maximum distance from power cables at U1-U2, and no obstructions above. **The LoRa panel is dedicated to the two LoRa radios only** — the GL.iNet Slate AX uses internal PCB antennas and requires no panel connection. **RF note:** Both LoRa radios are in the 902–928 MHz US915 band; stock defaults (Reticulum ~915.0 MHz, Meshtastic LongFast ~906.875 MHz) are separated by ~8 MHz — no configuration needed unless you change the default channels. WiFi (2.4/5 GHz) and LoRa (915 MHz) have no frequency overlap and coexist without conflict. **USB cable note:** LoRa boards at U8 connect to Pi #2 at U4 — 4U distance requires 3ft USB-C cables (item 23).
- **U7-U6:** The 2U touchscreen is the primary visual interface. Displays Grafana dashboards, ATAK maps, Monero sync status, or system logs. HDMI from Pi #1 (U4), USB touch to Pi #1.
- **U5:** The TP-Link switch (158mm, 6.22" wide) and GL.iNet Slate AX (77mm wide when rotated 90°) share a 1U shelf side by side. Combined width = 235mm in 236.5mm rack interior = **1.5mm clearance — very tight.** ⚠️ **Before assembly: measure your specific shelf's inner usable width.** If the shelf lip reduces usable width below 235mm, place GL.iNet on a small velcro-mount pad beside or behind the switch instead of trying to force side-by-side.
- **U4 (Front):** GeeekPi 1U Dual Pi 5 Mount (B0F7XBVV4D) holds both Pi 5 nodes in a single bracket. Each node gets NVMe via the mount's built-in PCIe adapters — no separate M.2 HAT+ required. This saves 1U compared to the previous 2× separate shelf design. ⚠️ **Before ordering: verify ASIN B0F7XBVV4D on Amazon — confirm product images show: (1) 1U height, (2) two Pi 5 boards installed, (3) two M.2 NVMe adapters, (4) clearance for Official Pi 5 Active Cooler with fan.** This is the critical path item for the entire rack layout.
- **U4-U3 (Rear):** LabStack 2U Mini 2x 80mm Fan Panel (3D print — github.com/JaredC01/LabStack) mounts on the **rear** rails at U4-U3, directly behind the Pi 5 node bay (U4 front). Two 80mm USB 5V fans screw in using their standard coarse-thread screws, oriented to exhaust hot air rearward. USB cables route to the USB fan hub at U3 (item 30g). U3 front is open — no conflict with the fan panel at U3 rear.
- **U3 (Front):** USB fan hub (item 30g) velcroed to interior rail — powers all 3 rack fans from PDU outlet 3 via 5V wall adapter, keeping all Pi USB ports free for field use. Rear side occupied by LabStack fan panel (see above).
- **U2 (Rear):** 1U Rack PDU mounted on **rear rails** with wings/flanges **flipped so outlets face inward** toward the rack interior. This positions the outlets directly above the UPS body at U1 — power adapters (Anker 747 GaN charger, switch 12V barrel adapter, fan hub 5V wall adapter) plug in and rest on top of the BC600R's flat top surface. Result: adapters are supported, contained, and invisible from both front and rear. Ultra-short PDU-to-UPS cable run (1U). U2 front is open. Outlet allocation: (1) Anker 747 → USB-C power to Pis, GL.iNet, touchscreen; (2) Switch 12V barrel; (3) fan hub 5V adapter; (4) spare.
- **U1 (Front):** Tripp Lite BC600R (10.04"×7.09"×2.28") sits inside the rack at U1. The UPS footprint (10.04"×7.09") fits within the rack's 11"×7.87" frame. ⚠️ **Verify in person:** The BC600R's 2.28" height is ~1.3U — it will protrude slightly above the U1 boundary into U2 space. Ensure no physical conflict with the PDU at U2. Secure with velcro to the rack frame. Wall outlet cable exits the rear; PDU 6ft cable connects UPS output to PDU at U2 (just 1U above — minimal cable length needed).
- **Hardware aesthetics:** The RackMate T1 ships with silver/zinc rack screws. For a fully matched black build, replace all panel mounting screws with **M6 × 10mm black button head socket cap screws** (item 30d) and 80mm fan mounting screws with **M3 × 25mm black socket cap** (item 30e). Print the custom LoRa panel and LabStack rear fan panel in black PETG (item 30f). The result is an all-black hardware profile — no silver visible on the front or rear of the rack.

### 2.4 USB Port Budget

Pi 5 has 4 USB ports: 2× USB 3.0 + 2× USB 2.0. All 3 rack fans are powered by the USB fan hub (item 30g) at U3 — **not** from Pi USB ports — keeping Pi front panels clean for field use.

| Pi | USB 3.0 Port 1 | USB 3.0 Port 2 | USB 2.0 Port 1 | USB 2.0 Port 2 | Spare |
|---|---|---|---|---|---|
| Pi #1 (comms) | Free | Free | Touchscreen touch input | Free | 2× USB 3.0 + 1× USB 2.0 |
| Pi #2 (tactical) | Free | Free | Heltec V3 — LEFT (RNode) | Heltec V3 — RIGHT (Meshtastic) | **2× USB 3.0** |

> **Fan power:** All 3 fans (120mm + 2× 80mm) plug into the USB fan hub at U3 (item 30g), powered by a 5V wall adapter on PDU outlet 3. This keeps Pi USB ports free for field peripherals (debug probes, cellular modems, USB drives, etc.).

> **Cellular modem note:** The cellular modem (Premium add-on Quectel RM520N-GL) connects to the **GL.iNet router's USB 3.0 port** — not to Pi #2.

### 2.5 Cable Management

- Use 6" Cat6 patch cables between switch, Pi nodes, and GL.iNet router
- Route USB and HDMI cables behind the SBC shelves (7.87" depth provides ~1" behind components)
- Use Velcro cable ties (not zip ties) for easy reconfiguration
- Label all cables with color or numbered tags
- Power cables from PDU route down the right rail

---

## 3. Power Budget Calculation

### 3.1 Component Power Draw

| Component | Idle (W) | Load (W) | Notes |
|---|---|---|---|
| Raspberry Pi 5 16GB #1 | 3.5 | 10.0 | Matrix, Tor, I2P, containers |
| Raspberry Pi 5 16GB #2 | 3.5 | 10.0 | Monero, ATAK, Reticulum |
| TP-Link TL-SG108S | 3.5 | 3.5 | Constant draw, no PoE |
| GL.iNet Slate AX | 5.0 | 7.0 | WiFi 6 AP + WireGuard active |
| GeeekPi 7.84" Touchscreen | 6.0 | 8.0 | LCD backlight + touch controller |
| WD SN740 256GB NVMe (Pi #1 via GeeekPi mount PCIe) | 0.8 | 1.8 | M.2 2230, PCIe Gen 3/4; lower than USB SATA |
| Crucial P310 1TB NVMe (Pi #2 via GeeekPi mount PCIe) | 1.0 | 2.2 | M.2 2230, PCIe Gen 4→3 on Pi 5; replaces USB SATA |
| 120mm USB Fan (U8 rear rails) | 1.5 | 2.0 | Medium speed setting |
| 2x 80mm USB Fans (rear exhaust, U4-U3 rear) | 1.0 | 1.5 | ~0.5W each at medium; powered via USB fan hub at U3 |
| 2× Heltec V3 (USB LoRa, Pi #2) | 0.2 | 0.8 | Two USB LoRa on Pi #2 USB 2.0 ports (serial 115200 baud — USB 2.0 is sufficient) |
| **TOTAL** | **~26W** | **~48.5W** | Dual exhaust (top + rear) for active Pi node cooling |

### 3.2 UPS Runtime Analysis

#### Tripp Lite BC600R (600VA / 300W) — Recommended; Rack-Floor Mounted
- Battery: ~6Ah at 12V = 72Wh usable (~60Wh after efficiency losses)
- Price: **~$70 (DigiKey confirmed; verify Amazon before ordering)**
- Dimensions: 10.04"×7.09"×2.28" — sits inside rack at U1; secured with velcro to rack frame
- **At idle load (26W):** ~60Wh / 26W = **~138 minutes (2 hr 18 min)**
- **At typical load (35W):** ~60Wh / 35W = **~103 minutes (1 hr 43 min)**
- **At full load (48.5W):** ~60Wh / 48.5W = **~74 minutes (1 hr 14 min)**
- **Key advantage:** Self-contained at U1 inside rack — no external UPS needed. All power infrastructure in one portable unit.

#### Budget Option: Tripp Lite INTERNET350U (350VA / 210W) — External
- Battery: ~5Ah at 12V = 60Wh usable (~50Wh after efficiency losses)
- Price: **~$94.99 confirmed (Newegg, Feb 2026)**
- **At idle load (26W):** ~115 minutes | **At typical (35W):** ~86 minutes | **At full (48.5W):** ~62 minutes
- **Note:** Does NOT fit inside rack; must sit external. Use only if BC600R is unavailable.

### 3.3 Power Recommendation

| Scenario | UPS Recommendation |
|---|---|
| Standard deployment (recommended) | Tripp Lite BC600R — U1 inside rack, self-contained |
| Vehicle (12V inverter available) | BC600R as buffer; 12V inverter is primary |
| Field (battery/solar only) | Skip UPS entirely; use LiFePO4 battery + DC-DC converters |
| Budget / BC600R unavailable | Tripp Lite INTERNET350U (external placement) |

**For field deployment beyond 3 hours:** Use LiFePO4 battery (12V 100Ah = 1.2kWh) with 12V-to-USB-C PD DC-DC converters — far more efficient than UPS chemistry.

**Power-saving tip:** `vcgencmd display_power 0` turns off the touchscreen (saves 6-8W, adds ~15-20 min to BC600R runtime). Script on a UPS battery-low signal if possible.

### 3.4 Power-Saving Tips
- Set Pi 5 CPU governor to `powersave` when idle
- Disable GL.iNet WiFi in wired-only scenarios
- Put LoRa in receive-only mode (0.1W vs 0.5W transmit)

---

## 4. GL.iNet Slate AX as Network Core

### 4.1 Specifications

| Feature | Detail |
|---|---|
| CPU | Qualcomm IPQ6000, 1.2GHz quad-core |
| RAM | 512MB DDR3L |
| Flash | 128MB NAND |
| WiFi | WiFi 6 (802.11ax), 2.4GHz + 5GHz |
| Antennas | Internal PCB antennas (2.4 GHz + 5 GHz) — no external connectors; no modification needed or recommended |
| Ethernet | 1x WAN (1GbE), 2x LAN (1GbE) |
| USB | 1x USB 3.0 |
| VPN | WireGuard, OpenVPN (client & server) |
| OS | OpenWrt (GL.iNet fork) |
| Power | USB-C, 5V/3A (15W max, ~7W typical) |
| Size | 4.6" x 3" x 1.1" |

### 4.2 Configuration Recommendations

1. **DHCP Server:** GL.iNet runs DHCP on 192.168.8.0/24 (default) or custom subnet. Assign static leases for Pi 5 nodes.
2. **WiFi AP:** Broadcast community SSID for local device access. Use WPA3 if supported by client devices.
3. **WireGuard Server:** Built-in WireGuard server enables remote access without Tailscale dependency.
4. **Tailscale:** Native Tailscale package available in GL.iNet firmware. Enables zero-config remote access from any device running Tailscale.
5. **DNS Filtering:** Built-in AdGuard Home for DNS-level ad/tracker blocking.
6. **Firewall:** OpenWrt-based firewall isolates WAN from LAN. Configure port forwarding only for services that need external access.

### 4.3 Uplink Options

| Scenario | Uplink Method |
|---|---|
| Home/Office | Ethernet WAN to existing router/modem |
| Hotel/Public WiFi | Repeater mode (WiFi WAN to WiFi LAN) |
| Vehicle/Field | USB tethering from phone, or USB cellular modem |
| Remote site | Starlink/cellular hotspot to WAN port |

### 4.4 Firmware

- **GL.iNet Official Firmware (recommended):** Includes admin panel, Tailscale, AdGuard Home, VPN management. Regular security updates.
- **Stock OpenWrt:** Loses GL.iNet admin panel. Only use if you need unavailable packages.

---

## 5. Storage Architecture

### 5.1 Drive Assignments

| Drive | Interface | Capacity | Assigned Workloads |
|---|---|---|---|
| microSD (Pi #1 boot) | SD slot | 32GB | Pi OS boot partition, recovery |
| NVMe SSD (Pi #1) | M.2 NVMe (PCIe, GeeekPi dual mount) | 256GB | Mounted at /mnt/nvme — Docker volumes, Matrix DB, service data. OS stays on microSD. |
| microSD (Pi #2 boot) | SD slot | 32GB | **OS boot and root filesystem for Pi #2** — OS stays on microSD; NVMe is data only |
| NVMe SSD (Pi #2) | M.2 NVMe (PCIe, GeeekPi dual mount) | 1TB | Monero blockchain (~95GB pruned), ATAK data, backups — mounted at /mnt/nvme; not the root OS |

### 5.2 Partitioning Recommendations

#### NVMe 256GB (Pi 5 #1 - Primary Services)
```
/dev/nvme0n1p1    256MB   /boot/firmware   (FAT32, boot partition)
/dev/nvme0n1p2     50GB   /                (ext4, root filesystem)
/dev/nvme0n1p3    190GB   /srv             (ext4, service data - Matrix DB, ATAK, Docker)
(~16GB unpartitioned for wear leveling / overprovisioning)
```

#### NVMe 1TB (Pi 5 #2 — via GeeekPi Dual Mount PCIe Adapter)
```
/dev/nvme0n1p1    256MB   /boot/firmware   (FAT32 — if migrating OS to NVMe; otherwise omit)
/dev/nvme0n1p2     50GB   /                (ext4 — if migrating OS to NVMe; otherwise omit)
/dev/nvme0n1p3    900GB   /mnt/nvme        (ext4, Monero LMDB, ATAK data, backups)
(~50GB unpartitioned for wear leveling)
```

> **Recommended:** Keep Pi #2 OS on microSD; NVMe is data-only. Simpler, provides fallback boot, no EEPROM changes needed. Migrate OS to NVMe later after build is stable. See Build Guide §5.1.

### 5.3 Backup Strategy

1. **Config Backup:** Cron job rsync critical configs from NVMe to /mnt/backup on SATA SSD daily
2. **Monero Wallet:** Encrypt wallet keys, store backup on separate USB drive kept offline
3. **Matrix Data:** Export room keys periodically; database dump to /mnt/backup weekly
4. **Full Image Backup:** Monthly `dd` image of NVMe to external USB drive (keep offsite)
5. **Recovery:** Boot from microSD, mount NVMe/SATA, restore from backup partition

---

## 6. Thermal Management

### 6.1 Heat Sources

| Component | Max TDP | Location |
|---|---|---|
| Pi 5 #1 (under load) | 10W | U4 |
| Pi 5 #2 (under load) | 10W | U4 |
| Touchscreen backlight | 8W | U7-U6 |
| TP-Link switch | 3.5W | U5 |
| GL.iNet router | 7W | U5 |
| **Total heat in enclosure** | **~39W** | |

### 6.2 Cooling Strategy

```
    FRONT                                     REAR
    +-----------+                             +-----------+
    U8  | LoRa Pnl  |  (antennas at top)     | 120mm Fan |  ^  ^  ^ (exhaust up)
    +-----------+                             +-----------+
    U7-6| Touchscr. |                        | screen rear|
    U5  |  Switch   |                        | switch rear|
    U4  | Dual Pi   |  ===================> | [80mm Fan1]| Pi node heat
        | Mount     |   Pi generates heat    | [80mm Fan2]| exits rearward
    U3  |  (open)   |                        | (fan cont.)|
    U2  |   PDU     |                        |  PDU rear  |
    U1  |   UPS     |                        | UPS rear   |
    +-----------+                             +-----------+
         ^  ^  ^
         |  |  |   (cool air enters around UPS sides)
    [BC600R UPS — U1 front, open-frame sides]
```

- **Primary exhaust:** 120mm USB fan at U8 **rear rails**, shares U8 with LoRa panel on front rails. Exhausts rising heat upward past the antennas. The LoRa panel's open sides and the open-frame chassis allow air to escape freely.
- **Secondary exhaust:** 2× 80mm USB fans in LabStack rear panel at U4-U3 (rear rails), directly behind the Pi 5 node bay (U4 front) — pulls Pi heat out rearward before it rises; most effective cooling path for the Pi nodes
- **Intake:** Open-frame T1 chassis allows cool air to enter around the sides and bottom of the UPS at U1. The BC600R does not seal the bottom; ambient air moves upward naturally through the open frame.
- **Component-level:** Pi 5 Active Cooler (official) on each node — heatsink + PWM fan controlled by Pi firmware
- **Monitoring:** `vcgencmd measure_temp` on each Pi 5, with alerts at 70°C (warning) and 80°C (throttle)

### 6.3 Temperature Thresholds

| Temperature | Pi 5 Behavior |
|---|---|
| < 60C | Normal operation |
| 60-80C | Fan ramps up (PWM active cooling) |
| 80C+ | CPU thermal throttling begins |
| 85C+ | Aggressive throttling, performance severely degraded |

### 6.4 Field Deployment Thermal Concerns

| Environment | Risk | Mitigation |
|---|---|
| Indoor (air-conditioned) | Low | Single exhaust fan sufficient |
| Indoor (no AC, summer) | Medium | Dual fan push-pull, reduce CPU clock if needed |
| Vehicle (summer, parked) | HIGH | Never leave powered on in parked vehicle in sun. Interior temps can exceed 60C |
| Outdoor (shade) | Medium | Ensure airflow; ambient up to 40C is manageable with active cooling |

### 6.5 Operating Temperature Range
- **Recommended:** 0C to 40C ambient (32F to 104F)
- **Maximum:** -10C to 50C with active cooling and thermal throttling accepted
- **Storage:** -20C to 60C (powered off)

---

## 7. Field Deployment Scenarios

### 7.1 Indoor Deployment (Primary Use Case)

**Setup:** Plug into wall power, connect Ethernet uplink to existing network.

| Item | Detail |
|---|---|
| Power | Wall outlet -> UPS -> PDU -> all components |
| Network | Ethernet from home/office router -> GL.iNet WAN port |
| WiFi | GL.iNet broadcasts community SSID for local access |
| Remote Access | Tailscale mesh VPN for off-site management |
| Setup Time | ~15 minutes (plug in, power on, verify services) |
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

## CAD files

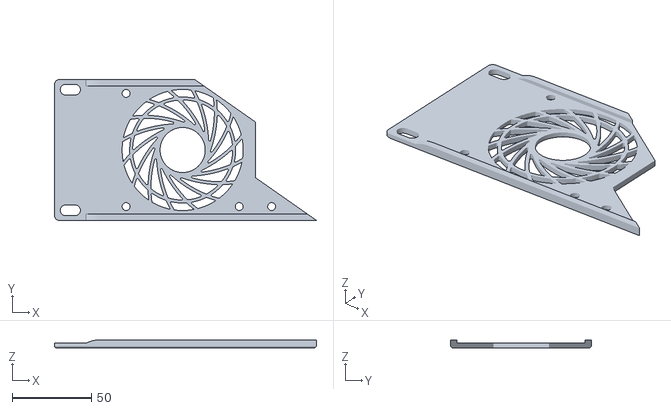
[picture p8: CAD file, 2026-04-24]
3d-models/2U_FanSide1.stl
165.6 x 89.0 x 5.20

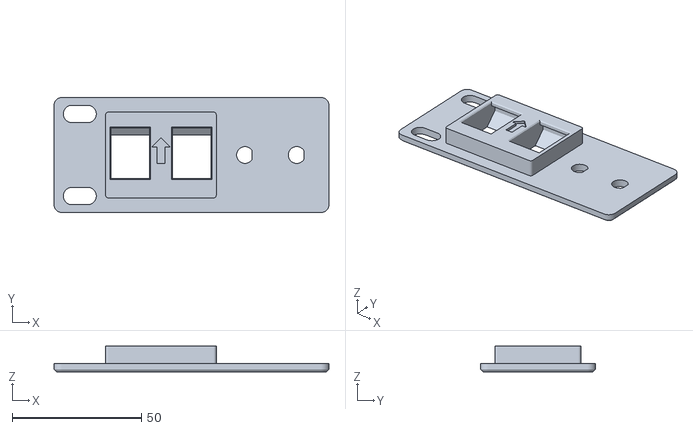
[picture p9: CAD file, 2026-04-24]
3d-models/1U Mini 2x Keystone 2x SMA Right Mount.stl
106.4 x 44.5 x 10.0

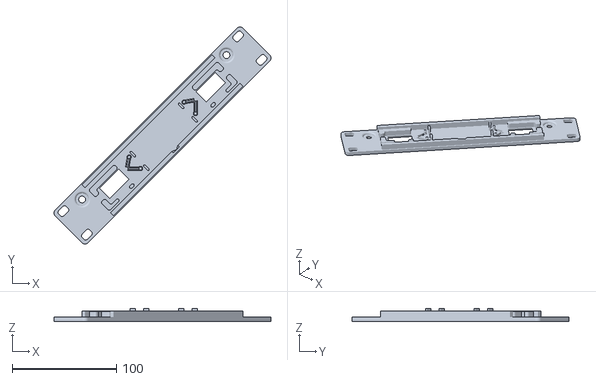
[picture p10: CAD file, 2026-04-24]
3d-models/2xHeltecFaceplate.stl
207.7 x 207.7 x 12.0

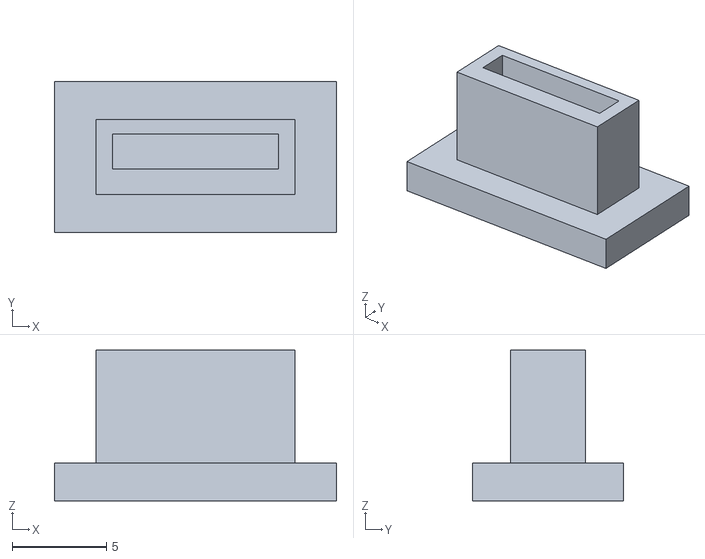
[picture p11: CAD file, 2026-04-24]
3d-models/4PinJSTBalance-Cover.stl
15.0 x 8.00 x 8.00

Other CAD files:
3d-models/2U_FanSide2.stl
3d-models/1U Mini 2x Keystone 2x SMA Left Mount.stl

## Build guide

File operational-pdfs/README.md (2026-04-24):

# M2 Community Node — Operational PDFs

> **These are templates, not your documents.**
>
> The PDFs in this directory were generated from the reference build (192.168.8.x IPs, placeholder domains). They are included so you can see what the finished output looks like. **Before you deploy, regenerate them with your own instance values** — your IPs, domain, WiFi credentials, and event name. See below.

---

## Documents

| File | Format | Purpose |
|---|---|---|
| `M2_Community_Node_Runbook.pdf` | US Letter, ~20 pages | Field operations runbook — POST checklist, service procedures, remote access, quick reference credential table |
| `M2_ATAK_FieldCard.pdf` | 3.5×5.5 in (x2), landscape US Letter | Laminated ATAK setup card — manual and QR enrollment steps, front/back |
| `M2_Community_Node_Build_Book.pdf` | US Letter, multi-page | Full build reference — condensed from BUILD_GUIDE.md for offline use |
| `M2_Community_Node_Troubleshooting.pdf` | US Letter | Troubleshooting reference — common failure modes and recovery steps |
| `M2_Rack_Wiring_Diagram.pdf` | US Letter, landscape | 1U/2U rack wiring diagram — power, data, and RF cabling |

---

## Regenerating for Your Build

All PDFs are generated from Python scripts in `scripts/`. Requirements: `reportlab`.

```
pip install reportlab
```

**Step 1 — Set your instance values.**

Copy `instance.conf.template` to `instance.conf` and fill in your values:

```
cp instance.conf.template instance.conf
nano instance.conf
```

Key fields that affect the PDFs:
- `NODE1_IP`, `NODE2_IP` — your Pi IPs
- `BASE_DOMAIN`, `ELEMENT_DOMAIN`, `HEADSCALE_DOMAIN` — your domains
- `EVENT_NAME`, `EVENT_DATE`, `EVENT_LOCATION` — printed on field card and runbook cover

Credentials (WiFi passwords, enrollment usernames/passwords) are read from `instance.conf` or environment variables — see each script header for the full variable list.

**Step 2 — Run the generators.**

```
cd scripts
python generate_runbook.py
python generate_field_card.py
python generate_build_book.py
python generate_reference_pdfs.py
python generate_m2_wiring_diagram.py
```

Output lands in `operational-pdfs/`.

---

## Printing Notes

- `M2_ATAK_FieldCard.pdf` — print landscape on US Letter, cut down the center, laminate each half. Fits standard 4×6 pouches.
- `M2_Community_Node_Runbook.pdf` — print US Letter, duplex or single-sided. Spiral bind or saddle-stitch for field use.
- `M2_Community_Node_Build_Book.pdf` — print US Letter, single-sided. Three-hole punch, binder.
- All others — US Letter, single-sided.

---

*CC BY-NC-SA 4.0*

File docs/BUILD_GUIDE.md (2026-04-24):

# Mission 2 — Community Node: Master Build Guide

> **Build Tier:** Recommended (~$1,385–$1,425) — Dual Raspberry Pi 5 16GB
> **Prerequisite:** Procurement complete. All hardware in hand.

> **⚠️ PLATFORM NOTICE:** This entire guide was developed, tested, and deployed from a **Windows 11 machine using PowerShell** as the SSH client to both Raspberry Pi nodes. All command formatting, quoting, escape sequences, and troubleshooting steps assume this specific setup. If you are building from a Linux or macOS workstation, you are responsible for adapting commands to your shell environment — particularly quoting rules, heredoc syntax, curl behavior, and SSH client differences. PowerShell aliases `curl` to `Invoke-WebRequest` (use `curl.exe` for real curl), mangles JSON escaping, and inserts hard newlines when pasting long lines into nano via SSH. None of these issues exist on Linux/macOS terminals, but other differences will. **If you are building from a different platform, consider using a Claude session to reformat the commands for your environment.** We make no guarantees about correctness on platforms other than Windows 11 + PowerShell.

---

## Table of Contents

1. [Overview & Timeline](#1-overview--timeline)
2. [Phase 0: Pre-Build (Before Hardware Arrives)](#2-phase-0-pre-build-before-hardware-arrives)
3. [Phase 1: Rack Assembly](#3-phase-1-rack-assembly)
4. [Phase 2: Network Baseline](#4-phase-2-network-baseline)
5. [Phase 3: OS & Base Config — Both Nodes](#5-phase-3-os--base-config--both-nodes)
6. [Phase 4: Node #1 — Communications Stack](#6-phase-4-node-1--communications-stack)
7. [Phase 5: Node #2 — Tactical/Crypto Stack](#7-phase-5-node-2--tacticalcrypto-stack)
8. [Phase 6: LoRa Radio Setup](#8-phase-6-lora-radio-setup)
9. [Phase 7: Integration Testing](#9-phase-7-integration-testing)
10. [Phase 8: Field Hardening](#10-phase-8-field-hardening)
11. [Phase 9: Post-Launch Improvements](#11-phase-9-post-launch-improvements)
12. [Quick Reference](#12-quick-reference)
13. [Field Operations: Power Cycle Procedure](#13-field-operations-power-cycle-procedure)
14. [Tech Verification Checklist](#14-tech-verification-checklist)

---

## 1. Overview & Timeline

### Node Assignments

| Node | Hostname | IP | Role | Services |
|---|---|---|---|---|
| Pi 5 #1 | `comms` | 192.168.8.10 | Communications | Conduit (Matrix), Element Web, Nginx, I2P, Tor, Cloudflared |
| Pi 5 #2 | `tactical` | 192.168.8.20 | Tactical/Crypto | Monero, OpenTAK Server (native), Reticulum, NomadNet, Mosquitto, Headscale, Mumble |

### Estimated Build Timeline

| Phase | Task | Time |
|---|---|---|
| Phase 0 | Monero pre-sync (x86, runs in background) | 4–7 days |
| Phase 0 | Image downloads + SD prep | 30 min |
| Phase 1 | Rack assembly | 1–2 hours |
| Phase 2 | Network baseline | 30 min |
| Phase 3 | OS on both nodes | 45 min |
| Phase 4 | Node #1 comms stack | 1–2 hours |
| Phase 5 | Node #2 tactical stack | 1–2 hours |
| Phase 6 | LoRa radio setup | 30 min |
| Phase 7 | Integration testing | 1 hour |
| Phase 8 | Field hardening | 30 min |
| **Total (excluding pre-sync)** | | **~7–10 hours** |

> **Critical path:** Start Monero pre-sync on your x86 machine the day procurement is ordered — it takes 4–7 days to sync the full blockchain and will be ready to rsync to the Pi by build day.

### Budget Swaps (if you downgraded any items)
- UPS: Tripp Lite BC600R (600VA/300W) — sits inside rack at U1; runtime at idle ~138 min (26W), typical ~103 min (35W), full load ~74 min (48.5W)
- Switch: If unmanaged (TL-SG108S) — skip VLAN config in Phase 2; assign static IPs only
- Single Pi 5 budget build — skip Node #2 phases entirely for now; they're designed to be added later
- Power: Use the Anker 747 GaNPrime 150W GaN charger (B09W2PNLX7, ~$65) instead of individual USB-C PD 27W adapters — one charger powers both Pi 5s, GL.iNet, and touchscreen from a single PDU outlet
- Transport (Premium add-on): **Pelican 1610** (~$180–$220) — interior 21.78"×16.69"×10.62". The T1 rack lays flat inside (16"L×11"W×7.8"H) with ~2.8" depth clearance for foam; BC600R is inside the rack at U1, self-contained unit. ⚠️ The Apache 4800 does NOT fit — its 7.25" interior depth is 0.55" shallower than the rack's 7.8" body depth.

---

## 2. Phase 0: Pre-Build (Before Hardware Arrives)

### 0.1 Monero Pre-Sync on x86 Machine

**Start this immediately — it takes 4–7 days.**

The Raspberry Pi 5 would take 2–4 weeks to sync the Monero blockchain natively on ARM. By syncing on a faster x86 machine first and rsyncing the LMDB database, you eliminate that wait entirely.

> **Full Windows pre-sync documentation** (including all troubleshooting, validation scripts, and recovery procedures) lives in `G:\MoneroNode\Monero_Node_Complete_Guide.md`. What follows is a summary for planning purposes.

#### ISP and Network Caveats (Confirmed in Real-World Testing)

**AT&T Fiber and other DPI-filtering ISPs:** AT&T uses Deep Packet Inspection to fingerprint and drop Monero's Levin P2P binary protocol. Symptoms: every outbound handshake times out (`LEVIN_ERROR_CONNECTION_TIMEDOUT`), node stuck at 1 peer, `target_height: 0`. **A VPN is required on AT&T.**

**VPN configuration that works (confirmed on AT&T Fiber + ProtonVPN):**
- Connect to a **regular ProtonVPN server** — NOT a P2P-labeled server (P2P servers cause the same timeouts)
- Launch monerod with **minimal flags only** — extra flags like `--db-sync-mode`, `--out-peers`, and `--add-peer` interfere with peer discovery through VPN

**What does NOT work for the pre-sync phase:**
- `--add-peer hostname:port` — crashes monerod on Windows via VPN (DNS resolution fails during p2p init)
- `--add-peer ip:port` — those nodes reject connections from VPN exit IPs
- Tor (`--proxy 127.0.0.1:9150`) — Tor exit nodes block port 18080; full blockchain sync cannot run over Tor hidden services

#### p2pstate.bin Corruption (All Environments)

Every time monerod stops, it writes a `p2pstate.bin` file. If corrupt on next start, monerod fails with `Exception in main! Failed to initialize p2p server`. **Always use the `__fix_and_launch.ps1` script** — it deletes this file before every launch automatically. Never run `monerod.exe` directly.

#### Windows Pre-Sync (Confirmed Working)

Install location: `G:\MoneroNode\` (or any drive with 120+ GB free)

```powershell
# All setup, validation, and launch is handled by scripts in G:\MoneroNode\
# See Monero_Node_Complete_Guide.md for full setup procedure.

# Standard launch (after setup):
Set-Location "G:\MoneroNode"
.\__fix_and_launch.ps1
```

**Confirmed working flags** (minimal — do not add more):
```powershell
.\monerod.exe `
    --prune-blockchain `
    --data-dir "G:\MoneroNode\data" `
    --log-level 1
```

**Monitor sync:**
```powershell
Set-Location "G:\MoneroNode"
.\check-sync.ps1
# Shows: Height / Target, Progress %, DB Size, Peer count, Status
```

**Linux pre-sync (no ISP DPI issues observed):**
```bash
./monerod --prune-blockchain --data-dir ~/monero-data --detach --log-level 0
tail -f ~/monero-data/bitmonero.log
```

**LMDB location after sync:**
```
Windows: G:\MoneroNode\data\lmdb\
Linux:   ~/monero-data/lmdb/
Size:    ~95-110 GB pruned
```

> **Do not proceed to Phase 5 until sync shows 100.0%.** Verify against [xmrchain.net](https://xmrchain.net). Keep monerod running until build day — you'll rsync the LMDB to the Pi in Phase 5.

---

### 0.2 Download Software & Images

Do this while waiting for hardware to arrive.

**Raspberry Pi OS (64-bit, Bookworm):**
```
https://www.raspberrypi.com/software/operating-systems/
Download: Raspberry Pi OS Lite (64-bit) — no desktop needed
```

**Raspberry Pi Imager:**
```
https://www.raspberrypi.com/software/
```

**Docker images to pre-pull (optional — saves time on slow connections):**

These are the pinned versions used in the compose files. Do not pull `:latest` — you'll get a different image than what the configs are tested against.

```bash
# Node #1 — Communications Stack
docker pull matrixconduit/matrix-conduit:v0.10.12
docker pull vectorim/element-web:v1.12.11
docker pull nginx:1.28.2-alpine3.23
docker pull purplei2p/i2pd:release-2.59.0
docker pull osminogin/tor-simple:0.4.8.21
docker pull cloudflare/cloudflared:2026.2.0

# Node #2 — Tactical/Crypto Stack
docker pull ghcr.io/sethforprivacy/simple-monerod:v0.18.4.5
docker pull python:3.12.12-slim-bookworm
docker pull eclipse-mosquitto:2.0.22
docker pull headscale/headscale:0.28.0
# OpenTAK Server: native install (systemd) — no Docker image needed
```

> **Image version reference (verify current tags before deploying):**
> | Image | Pinned Tag | Notes |
> |---|---|---|
> | `matrixconduit/matrix-conduit` | `v0.10.12` | **Tech debt:** matrixconduit/matrix-conduit is abandoned as of 2025. Active community fork is conduwuit. Plan migration post-CCC26. Do NOT change the image now — document for future sprint. |
> | `vectorim/element-web` | `v1.12.11` | Latest stable |
> | `nginx` | `1.28.2-alpine3.23` | Stable branch, Alpine 3.23 |
> | `purplei2p/i2pd` | `release-2.59.0` | Latest stable, Feb 2026 |
> | `osminogin/tor-simple` | `0.4.8.21` | Mirrors Tor version |
> | `cloudflare/cloudflared` | `2026.2.0` | CalVer, update monthly |
> | `simple-monerod` | `v0.18.4.5` | Monero Fluorine Fermi |
> | `OpenTAKServer` | `v1.7.9` | Native install (systemd) — not Docker. Pi installer is production-ready. |
> | `python` | `3.12.12-slim-bookworm` | Oct 2025 patch release (Reticulum/NomadNet) |
> | `eclipse-mosquitto` | `2.0.22` | Stable 2.0.x series |
> | `headscale/headscale` | `0.28.0` | ⚠️ Breaking changes from 0.23 — read release notes |

**rnodeconf (for LoRa firmware flashing — bundled in rns package):**
```bash
pip install rns
# rnodeconf is now part of rns — do NOT install the standalone rnodeconf package (outdated)
```

---

### 0.3 Prepare microSD Cards

Flash both microSD cards before build day so first boot is instant.

1. Insert microSD card into your computer
2. Open Raspberry Pi Imager
3. **Choose Device:** Raspberry Pi 5
4. **Choose OS:** Raspberry Pi OS Lite (64-bit)
5. **Choose Storage:** your microSD card
6. **Click the gear icon (Advanced settings):**
   - Enable SSH ✓
   - Set hostname: `comms` (card 1) / `tactical` (card 2)
   - Set username: `pi` (or your preferred username)
   - Set password: use a strong password
   - Configure WiFi: optional (you'll use Ethernet)
   - Set locale/timezone
7. Write the card
8. Label each card clearly

---

### 0.4 Optional: 3D Print Rack Accessories

If GeeekPi RackMate T1 panels or trays are backordered:

- **Blank 1U/2U panels:** search Printables/Thingiverse for "10 inch rack panel 1U"
- **Pi 5 tray for 10" rack:** search "Raspberry Pi 5 rack mount 10 inch"
- **Jeff Geerling's community files:** `github.com/geerlingguy/mini-rack`
- **DeskPi STL files:** `deskpi.com` → Downloads
- Print in PETG (better heat tolerance than PLA for enclosed rack)

---

### 0.5 Hardware Validation (DOA Check — Before Rack Assembly)

**Do this before assembling anything in the rack.** A 15-minute bench test on each component saves hours of debugging inside an assembled rack.

**Raspberry Pi #1 and #2 — bare board boot test:**
```bash
# Insert pre-flashed microSD, connect USB-C power
# Find DHCP IP from your router client list, then:
ssh pi@<dhcp-ip>
uname -a                  # verify: aarch64, kernel 6.x
vcgencmd get_throttled    # must return 0x0 (no undervoltage, no throttling)
free -h                   # should show ~15.6 GB total RAM
```
> If `get_throttled` returns anything other than `0x0`, your power supply is insufficient. Stop — do not proceed.

**NVMe SSDs — verify recognition (after Phase 3.4):**
```bash
lsblk                                  # nvme0n1 must appear
sudo nvme smart-log /dev/nvme0n1       # check "Critical Warning: 0x0"
```

**GL.iNet Slate AX:**
- Power via USB-C → browse to `http://192.168.8.1` → login page appears ✓

**TP-Link TL-SG108S switch:**
- Connect any device to any port → green link LED ✓

**Tripp Lite BC600R UPS:**
- Plug in, press power button → green status LED ✓
- Self-test passes (brief beep sequence) ✓

**LoRa radios — USB serial recognition:**
```bash
# Connect each radio individually to your laptop
dmesg | tail -20    # should show: CP210x or CH343 USB converter
ls /dev/ttyUSB*     # /dev/ttyUSB0 should appear
```

**Touchscreen (if purchased):**
- Connect via HDMI + USB to any Pi → display lights on ✓

> **Stop here if anything fails.** Initiate DOA return/replacement before you build. Parts within the rack are harder to swap after assembly.

---

## 3. Phase 1: Rack Assembly

### 1.1 Inventory Check

Before starting, verify you have every item. Cross-reference HARDWARE_BOM.md recommended tier BOM.

Critical items:
- [ ] GeeekPi RackMate T1 8U chassis (B0CPLRD29P)
- [ ] Raspberry Pi 5 16GB × 2 (PiShop.us, $205 ea.)
- [ ] Pi 5 Active Cooler × 2 (PiShop.us, $10.95 ea.)
- [ ] GeeekPi 1U Dual Pi 5 Mount (B0F7XBVV4D) — **⚠️ verify on Amazon before ordering: confirm (1) 1U height, (2) 2× Pi 5 slots, (3) 2× built-in NVMe adapters, (4) clearance for Pi 5 Active Cooler. This is the critical path item for the entire layout.**
- [ ] WD SN740 256GB M.2 2230 NVMe OEM (B0C6MVP42M) — Pi #1 (~$35-45; Official Pi SSD 256GB OUT OF STOCK Feb 2026)
- [ ] Crucial P310 1TB M.2 2230 NVMe (CT1000P310SSD2) — Pi #2 (~$115-150; Official Pi SSD 1TB OUT OF STOCK Feb 2026)
  > **⚠️ NVMe Gen 3 required on both nodes:** Add `dtparam=pciex1_gen=3` to `/boot/firmware/config.txt` (Phase 3.4). GeeekPi dual mount defaults to Gen 2 without it. See BOM §1.1 for detail.
- [ ] TP-Link TL-SG108S 8-port switch (~$27) — skip Phase 2.2 VLAN config if using unmanaged
- [ ] Tripp Lite BC600R UPS (600VA/300W, ~$70)
- [ ] GL.iNet Slate AX router (AXT1800, $119.99)
- [ ] 1U Rack PDU 4-Outlet (B0FP56YSWZ) — 125V/15A, surge protection, 6ft cable
- [ ] GeeekPi 2U touchscreen (B0F3C5R2BZ)
- [ ] Anker 747 GaNPrime 150W GaN charger (B09W2PNLX7) — powers both Pi 5s + GL.iNet + display from one PDU outlet
- [ ] Heltec WiFi LoRa 32 V3 915MHz × 2 ($19.90 each, heltec.org) — LEFT=RNode, RIGHT=Meshtastic

- [ ] 915 MHz antennas × 2 — **⚠️ must be SMA MALE (NOT RP-SMA)** — verify connector type in listing photos before ordering
- [ ] USB-C to USB-C cables, 1ft, ×3 — **not included with Anker 747** (Pi #1, Pi #2, GL.iNet power)
- [ ] microSD cards × 2 (pre-flashed, from Phase 0)
- [ ] Short Ethernet patch cables (6" or 1ft, internal rack runs)
- [ ] WAN Ethernet cable (3ft or 6ft — for GL.iNet WAN to uplink; short patches are too short)
- [ ] Velcro cable ties + cable labels (both ends of every cable)
- [ ] Dust filter foam pad (120mm, open-frame intake areas)
- [ ] USB-A extension cable 12"–18" × 1 (contingency: 80mm fan cable length to Pi #2)
- [ ] Custom 1U LoRa Panel (3D print, black PETG) — 2× OLED windows, 2× SMA bulkhead holes, 2× M2 board mount positions
- [ ] SMA female bulkhead connectors × 2
- [ ] U.FL-to-SMA-male pigtail cables × 2 (6", IPEX MHF4 to SMA male)
- [ ] M2 × 8mm nylon standoffs + M2 screws (8 standoffs = 4 per board)
- [ ] LabStack 2U Mini 2x 80mm Fan Panel (3D print, github.com/JaredC01/LabStack)
- [ ] 80mm USB 5V fans × 2 (GDSTIME / ELUTENG or similar)

---

### 1.2 UPS — Initial Charge

**Do this first** — the UPS needs 8–12 hours to reach full charge from the box.

1. Unbox Tripp Lite BC600R
2. Plug into wall outlet
3. Power on UPS (press power button)
4. Let charge — you'll hear a beep when ready
5. Leave plugged in throughout the build
6. After build is complete, the BC600R sits inside the rack at U1 — secured with velcro to the rack frame. Dimensions are 10.04"×7.09"×2.28" (~1.3U height)

---

### 1.3 Rack Assembly Order

Work bottom-up — heaviest items go low.

```
FRONT VIEW                                    REAR VIEW
+==========================================+  +==========================+
|          GeeekPi 8U RackMate T1          |  |        (Rear View)       |
|          (Front View, Top-Down)          |  +==========================+
+==========================================+  |                          |
|                                          |  |  U8  [ 120mm Fan (rear)] |  <-- shares U8 with
|  U8  [ Custom 1U LoRa Panel (front) ]   |  |      [ exhaust UP      ] |     LoRa panel (front)
|      [ Heltec (L) | SMA | Heltec (R)]  |  |                          |
|                                          |  |  U7  [ screen rear     ] |
|  U7  [                               ]   |  |  U6  [ (cables)        ] |
|      [ 2U Touchscreen (7.84" LCD)    ]   |  |                          |
|  U6  [                               ]   |  |  U5  [ switch rear     ] |
|                                          |  |                          |
|  U5  [ TP-Link TL-SG108S + GL.iNet  ]   |  |  U4  [ LabStack 2U     ] |  <-- 2x 80mm fans
|      [ (side by side on 1U shelf)   ]   |  |      [ 80mm Fan Panel   ] |     pull air OUT
|                                          |  |  U3  [ (rear exhaust)  ] |     behind Pi nodes
|  U4  [ GeeekPi 1U Dual Pi 5 Mount   ]   |  |                          |
|      [ Pi #1 (left) + Pi #2 (right) ]   |  |  U2  [ PDU (rear rails)] |     outlets face inward;
|      [ 256GB NVMe    1TB NVMe       ]   |  |      [ adapters on UPS ] |     adapters rest on UPS
|                                          |  |  U1  [ UPS rear cable  ] |
|  U3  [ USB Fan Hub (velcro mount)   ]   |  |                          |
|                                          |  +==========================+
|  U2  [ ---- OPEN ----               ]   |     PDU on REAR rails
|                                          |
|  U1  [ Tripp Lite BC600R (UPS)       ]   |
|      [ 10.04"×7.09"×2.28" (~1.3U)  ]   |
|                                          |
+==========================================+
```

**Airflow path:** Cool air enters around the sides of the BC600R UPS at U1 (open-frame chassis) → flows upward through rack → Pi nodes at U4 generate heat → 2× 80mm rear fans (U4-U3 rear) pull hot air out the rear → 120mm fan at U8 rear exhausts remaining rising heat upward past the LoRa antennas. Dual exhaust at rear + top creates positive airflow through the Pi node zone.

**Note on U positions:** U8 is shared — LoRa panel on **front** rails (antennas at top for best RF, maximum distance from power at U1-U2), 120mm fan on **rear** rails (exhaust up). The LabStack 2U fan panel mounts on the **rear** rails spanning U4-U3, directly behind the Pi mount (U4 front). U3 front is open for future expansion; U3 rear is the fan panel's second U.

> The Tripp Lite BC600R sits inside the rack at U1, secured with velcro to the rack frame. PDU mounts on **rear rails** at U2 with wings flipped so outlets face inward — power adapters rest on the UPS body. Ultra-short power cable run. U2 front is open. All power infrastructure is self-contained in the rack.

**Assembly steps:**

1. Attach rack ears/rails per GeeekPi RackMate T1 instructions
2. Place Tripp Lite BC600R into U1 (bottom front) — secure with velcro to rack frame
3. Mount PDU into U2 (**rear rails**) — flip wings so outlets face inward; power adapters rest on top of UPS body at U1. 6ft cable drops down to UPS (ultra-short run). U2 front stays open.
4. Print and install LabStack 2U Mini 2x 80mm Fan Panel into U4-U3 (rear rails) — mount 2× 80mm USB fans using the fans' coarse-thread screws; orient fans to exhaust air OUT of the rack
5. Install GeeekPi 1U Dual Pi 5 Mount into U4 (front) — holds both Pi nodes with built-in NVMe adapters. Fan panel (U4-U3 rear) sits directly behind for maximum cooling.
6. Mount switch and GL.iNet router side-by-side on a 1U shelf into U5 (front)
7. Mount touchscreen into U6/U7 (front) — connect HDMI from Pi #1 and USB for touch input
8. Print and install custom 1U LoRa panel into U8 (front rails) — antennas at maximum height for best RF propagation:
   - Install 2× SMA female bulkhead connectors into SMA cutout holes, secure with nuts
   - Mount Heltec V3 (RNode) on **LEFT** M2 standoff positions (4× M2 nylon standoffs), OLED aligned behind left window cutout
   - Mount Heltec V3 (Meshtastic) on **RIGHT** M2 standoff positions (4× M2 nylon standoffs), OLED aligned behind right window cutout
   - Connect U.FL-to-SMA pigtail from LEFT Heltec V3 U.FL connector → left SMA bulkhead (interior side)
   - Connect U.FL-to-SMA pigtail from RIGHT Heltec V3 U.FL connector → right SMA bulkhead (interior side)
   - Screw 915 MHz antennas onto exterior SMA bulkheads — **verify SMA male (center pin), not RP-SMA**
9. Mount 120mm exhaust fan into U8 (rear rails) — shares U8 with LoRa panel on front rails via open-frame chassis

---

### 1.4 Attach Coolers and Storage to Pi Boards

**Before mounting Pi boards in the GeeekPi 1U Dual Pi 5 Mount, do this on a clear surface:**

**Pi #1 — attach cooler and NVMe:**
1. Attach Pi 5 Active Cooler to Pi #1 (press down firmly, connector goes to fan header)
2. Install the WD SN740 256GB M.2 2230 into the left NVMe adapter slot on the GeeekPi dual mount
3. Secure NVMe with the retention screw
4. No separate M.2 HAT+ is needed — the dual mount's built-in PCIe adapter provides NVMe connectivity

**Pi #2 — attach cooler and NVMe:**
1. Attach Pi 5 Active Cooler to Pi #2
2. Install the Crucial P310 1TB M.2 2230 into the right NVMe adapter slot on the GeeekPi dual mount
3. Secure NVMe with the retention screw

**Mount both Pi boards in the GeeekPi 1U Dual Pi 5 Mount and connect:**
- Anker 747 GaN charger → PDU outlet 1 (one outlet powers everything below)
- Anker C1 (short USB-C cable) → Pi #1
- Anker C2 (short USB-C cable) → Pi #2
- Anker C3 (short USB-C cable) → GL.iNet Slate AX
- Anker USB-A → touchscreen display
- Switch 12V adapter → PDU outlet 2
- Ethernet from switch port 1 → Pi #1
- Ethernet from switch port 2 → Pi #2
- Ethernet from switch uplink → GL.iNet LAN port
- Heltec V3 LEFT (RNode) → Pi #2 USB 2.0 port 1 via 3ft USB-C cable (board mounted on LoRa panel at U8, Pi at U4 — 4U distance; serial 115200 baud — USB 2.0 is sufficient)
- Heltec V3 RIGHT (Meshtastic) → Pi #2 USB 2.0 port 2 via 3ft USB-C cable (board mounted on LoRa panel at U8, Pi at U4 — 4U distance)
- U.FL pigtails and SMA antennas already connected during panel assembly (step 3 above)
- USB fan hub wall adapter → PDU outlet 3
- 120mm fan (U8 rear) → USB fan hub at U3
- 2× 80mm rear fans (U4-U3 rear) → USB fan hub at U3
- All 3 fans powered from hub — zero fan cables to Pi USB ports

---

### 1.5 Cable Management

- Run all Ethernet on the right side, power on the left
- Use velcro ties — never zip ties (harder to modify later)
- Keep patch cables short — measure runs before cutting/buying
- **Label both ends of every cable** (P-Touch tape or masking tape + sharpie — cable labels are in the BOM, item 24a)
- Leave 6" of slack at each device end for serviceability
- The WAN cable (item 21a) exits the rack through the rear — route it separately from internal patch cables

---

## 4. Phase 2: Network Baseline

### 2.1 GL.iNet Slate AX Router Setup

1. Connect your laptop to the GL.iNet via Ethernet or WiFi (`GL-AXT1800-XXX`)
2. Browse to `http://192.168.8.1` (default GL.iNet LAN IP)
3. Set admin password (strong — save in password manager)
4. **WAN configuration:**
   - If connecting to your home router: plug WAN port into home network switch
   - If standalone/field: configure 4G dongle or tether from phone
5. **WiFi — Two SSIDs:**

   | SSID | Band | Hidden | Password | Purpose |
   |---|---|---|---|---|
   | `NodeAdmin` | 5GHz main | No | Operator's personal password (not documented) | Operator/admin access only |
   | `CommunityNode` | 5GHz guest | No | `YOUR_EVENT_WIFI_PASSWORD` (set per event, document in `M2_SECRETS.md`) | Visitors, community members |

   - `NodeAdmin`: Wireless → 5GHz → set SSID and password, apply
   - `CommunityNode`: Guest Network → 5GHz Guest → enable, set SSID and password, leave 2.4GHz Guest disabled, apply
   - After applying, reconnect to `NodeAdmin` — Pis on ethernet are unaffected
   - Wait 60 seconds for AP isolation fix scripts to fire before testing connectivity
6. **DHCP range:** 192.168.8.100 – 192.168.8.200
7. **Static leases (MUST use ethernet MAC addresses):**
   - Pi #1 `comms`: 192.168.8.10 — ethernet MAC: `[YOUR MAC — see note below]`
   - Pi #2 `tactical`: 192.168.8.20 — ethernet MAC: `[YOUR MAC — see note below]`
   - Touchscreen: 192.168.8.30

> **Do NOT copy MACs from another build — they are burned into each device and unique to your hardware.** Using wrong MACs causes silent DHCP failure: the Pi gets a random IP and SSH to the static address will fail with no error.
>
> **You won't know the MACs until first boot.** Skip this step now. After Phase 3.1 first boot, open `http://192.168.8.1` → Clients. Each Pi will appear with its real ethernet MAC. Copy those values, create the static leases, then reboot the Pis before continuing to Phase 3.2.
>
> **CRITICAL: Use the ethernet MAC, not the WiFi MAC.** Each Pi 5 has two NICs. Look for the **wired** connection icon in the GL.iNet clients list, not the WiFi icon. If the Pis show up with unexpected IPs (e.g. .136, .141) after setting leases, delete the reservations and recreate using the MAC shown on the wired entry.

8. **Fix AP Isolation firmware bug (CRITICAL):**

> **Known bug:** The GL-AXT1800 firmware (confirmed on v4.x) silently forces `ap_isolate=1` in the hostapd config whenever repeater mode is active. This blocks WiFi clients (your laptop/phone) from reaching wired LAN clients (the Pis on the switch). The admin UI shows isolation as "off" but the running config ignores it. This must be fixed or you cannot manage the Pis from WiFi.

**[SSH — GL.iNet router]**

SSH into the router: `ssh root@192.168.8.1` (password is the admin panel password)

Create a hotplug script that automatically disables AP isolation on every network change. The script includes a 10-second delay and a retry because `wifi reload` restarts hostapd asynchronously — without the delay, the fix fires before hostapd is ready and doesn't stick:

**[SSH — root@GL.iNet router (192.168.8.1)]**

```
cd /etc/hotplug.d/iface
```

```
printf '#!/bin/sh\nsleep 10\nhostapd_cli -i wlan0 set ap_isolate 0 2>/dev/null\nhostapd_cli -i wlan1 set ap_isolate 0 2>/dev/null\nsleep 10\nhostapd_cli -i wlan0 set ap_isolate 0 2>/dev/null\nhostapd_cli -i wlan1 set ap_isolate 0 2>/dev/null\n' > 99-fix-isolation
```

```
chmod +x 99-fix-isolation
```

Expected contents of `/etc/hotplug.d/iface/99-fix-isolation`:
```
#!/bin/sh
sleep 10
hostapd_cli -i wlan0 set ap_isolate 0 2>/dev/null
hostapd_cli -i wlan1 set ap_isolate 0 2>/dev/null
sleep 10
hostapd_cli -i wlan0 set ap_isolate 0 2>/dev/null
hostapd_cli -i wlan1 set ap_isolate 0 2>/dev/null
```

Add boot-time backup to rc.local with a double-tap pattern (15s and 30s after boot):

**[SSH — root@GL.iNet router (192.168.8.1)]**

```
printf '# Put your custom commands here that should be executed once\n# the system init finished. By default this file does nothing.\n\n. /lib/functions/gl_util.sh\nremount_ubifs\n\n# Fix GL.iNet AP isolation firmware bug — double tap with delay\n(sleep 15 && hostapd_cli -i wlan0 set ap_isolate 0 && hostapd_cli -i wlan1 set ap_isolate 0) &\n(sleep 30 && hostapd_cli -i wlan0 set ap_isolate 0 && hostapd_cli -i wlan1 set ap_isolate 0) &\nexit 0\n' > /etc/rc.local
```

Expected contents of `/etc/rc.local`:
```
# Put your custom commands here that should be executed once
# the system init finished. By default this file does nothing.

. /lib/functions/gl_util.sh
remount_ubifs

# Fix GL.iNet AP isolation firmware bug — double tap with delay
(sleep 15 && hostapd_cli -i wlan0 set ap_isolate 0 && hostapd_cli -i wlan1 set ap_isolate 0) &
(sleep 30 && hostapd_cli -i wlan0 set ap_isolate 0 && hostapd_cli -i wlan1 set ap_isolate 0) &
exit 0
```

Apply the fix immediately (no reboot needed):

```
hostapd_cli -i wlan0 set ap_isolate 0
```

```
hostapd_cli -i wlan1 set ap_isolate 0
```

Verify from your Windows machine: `ping 192.168.8.10` — should respond.

> **If WiFi-to-LAN stops working in the future:** SSH into the router (`ssh root@192.168.8.1`) and re-run `hostapd_cli -i wlan0 set ap_isolate 0` and `hostapd_cli -i wlan1 set ap_isolate 0`. The hotplug and rc.local scripts handle reboots and wifi reloads automatically, but a WiFi password change or firmware upgrade can still trigger the bug. If scripts are missing after a firmware upgrade, recreate them with the commands above.
>
> **Known triggers:** WiFi password changes, firmware upgrades, `wifi reload` commands, and GL.iNet admin panel changes to wireless settings all cause the firmware to rewrite hostapd config with `ap_isolate=1`. The double-tap retry pattern in the scripts handles the timing race condition where hostapd restarts asynchronously after these events.
>
> **Boot timing: After any router reboot or power cycle, allow 60 seconds before testing connectivity.** The AP isolation fix scripts run at 15s and 30s after boot. WiFi clients can associate before the fix applies, so initial pings may fail. This is normal — wait for the full 60-second startup window before troubleshooting. This applies to field deployment power-on sequences as well.

---

### 2.2 Switch Setup — TL-SG108S (Unmanaged)

The **TP-Link TL-SG108S** is an unmanaged gigabit switch — no configuration required. Plug in and go.

#### 2.2.1 Port Assignment

| Switch Port | Device | Cable Length |
|---|---|---|
| Port 1 | GL.iNet Slate AX — **LAN1** port (maps to `eth2` in OpenWrt) | 6" patch |
| Port 2 | Pi #1 `comms` (192.168.8.10) | 6" patch |
| Port 3 | Pi #2 `tactical` (192.168.8.20) | 6" patch |
| Port 4 | Touchscreen (192.168.8.30) — optional if networked | 6" patch |
| Ports 5–8 | Spare | — |

GL.iNet WAN port → your internet uplink (home router / cellular / Starlink).

#### 2.2.2 Power

Connect the switch's 12V DC barrel adapter to a PDU outlet. Link LEDs on the connected ports will light up within a few seconds of powering the GL.iNet.

> No IP address, no login, no PoE risk, no save-config step. The GL.iNet handles all routing and DHCP — the switch is just a patch panel.

---

### 2.3 GL.iNet DNS Overrides for Matrix (LAN Hairpin Fix)

LAN clients (on CommunityNode WiFi) reach Matrix at `https://m2-matrix.yourdomain.com` and the server delegation domain `m2.yourdomain.com`. Both must resolve to Pi #1's LAN IP (`192.168.8.10`) on the GL.iNet router. Without these overrides, HTTPS connections from LAN devices go via Cloudflare's edge instead of directly to the Pi, and TLS breaks because the cert is issued for the clearnet hostname. Add both dnsmasq overrides now, before deploying Matrix.

**[SSH — root@GL.iNet router (192.168.8.1)]**

```
uci add_list dhcp.@dnsmasq[0].address="/m2-matrix.yourdomain.com/192.168.8.10"
uci add_list dhcp.@dnsmasq[0].address="/m2.yourdomain.com/192.168.8.10"
```

```
uci commit dhcp && /etc/init.d/dnsmasq restart
```

Verify both overrides are active:

```
nslookup m2-matrix.yourdomain.com 192.168.8.1
nslookup m2.yourdomain.com 192.168.8.1
```

Expected: both return `192.168.8.10`. If either returns the public Cloudflare IP, the override did not apply — check `uci show dhcp | grep address` to confirm both entries are present.

> Both overrides survive router reboots. A firmware upgrade may wipe UCI customizations — re-apply if LAN Matrix access stops working after a firmware update.

---

### 2.4 Visitor Onboarding — QR Codes

Visitors connect and learn about the node via two QR codes printed on a card attached to the rack:

| QR Code | What it does | File |
|---|---|---|
| **WiFi QR** | Phone camera scans it, auto-joins `CommunityNode` WiFi | `qr-wifi.svg` |
| **Community Page QR** | Opens `http://192.168.8.10:8081` in their browser | `qr-community-page.svg` |

**Flow:** Scan WiFi QR to connect. Scan community page QR to see services, ATAK setup instructions, Element link, and app download QR codes. That's it.

> **Why not a captive portal?** Android's captive portal WebView auto-dismisses the instant the connectivity check passes — any redirect to the community page dies with it. This is a documented Android limitation (Google Issue Tracker #37046898) that affects all captive portal implementations including nodogsplash and enterprise solutions from Cisco, Fortinet, and Meraki. QR codes are simpler, more reliable, and require zero router/Pi configuration.

Regenerate QR codes if WiFi credentials or IPs change:

```bash
python generate_qr.py
```

Print both QR codes (WiFi + Community Page) on a laminated card and attach to the rack near the kiosk touchscreen. The field card (`M2_ATAK_FieldCard.pdf`) already includes the WiFi QR — add the community page QR to the next revision.

---

## 5. Phase 3: OS & Base Config — Both Nodes

**Do the following steps on BOTH Pi's.** Pi #1 (`comms`) first, then Pi #2 (`tactical`).

### 3.1 First Boot

1. Insert pre-flashed microSD card
2. Connect Ethernet (HDMI + keyboard optional — SSH is preferred)
3. Power on via USB-C
4. Wait ~60 seconds for first boot
5. SSH in:

```bash
ssh pi@192.168.8.10    # Pi #1 (once GL.iNet static lease is set)
ssh pi@192.168.8.20    # Pi #2
```

> First boot: if static leases aren't set yet, find the IP from GL.iNet's DHCP client list at `http://192.168.8.1` → Clients.

---

### 3.2 System Update & Hardening

Run on each Pi:

```bash
# Update system
sudo apt update && sudo apt full-upgrade -y

# Set hostname (should already be set from imager, verify)
hostnamectl set-hostname comms    # Pi #1
hostnamectl set-hostname tactical # Pi #2

# Set timezone
sudo timedatectl set-timezone America/Chicago   # adjust to your timezone
sudo timedatectl set-ntp true

# Disable unnecessary services
sudo systemctl disable bluetooth
sudo systemctl disable avahi-daemon

# Configure SSH — key-based auth
# ⚠️ CRITICAL ORDER: copy your public key FIRST, then disable password auth.
# If you disable password auth before copying your key, you will lock yourself out.

# Step 1 — On your LAPTOP (not the Pi), copy your public key:
ssh-copy-id pi@192.168.8.10   # comms
ssh-copy-id pi@192.168.8.20   # tactical
# If you don't have an SSH key yet, generate one first on your laptop:
#   ssh-keygen -t ed25519 -C "m2-admin"

# Step 2 — Verify key login works BEFORE disabling password auth:
ssh pi@192.168.8.10   # should log in WITHOUT a password prompt
# Only proceed to Step 3 if key login works.

# Step 3 — Harden SSH config (on each Pi):
sudo nano /etc/ssh/sshd_config
# Set: PasswordAuthentication no
# Set: PermitRootLogin no
sudo systemctl restart ssh

# Configure automatic unattended security upgrades
sudo apt install -y unattended-upgrades
sudo dpkg-reconfigure --priority=low unattended-upgrades
```

---

### 3.3 Docker Install

Run on each Pi:

```bash
# Install Docker
curl -fsSL https://get.docker.com | sh
sudo usermod -aG docker $USER

# Install Docker Compose plugin
sudo apt install -y docker-compose-plugin

# Verify
docker --version
docker compose version

# Log out and back in for group changes to take effect
exit
```

---

### 3.4 Enable Pi 5 PCIe and NVMe — Both Nodes

Run the following on **both** Pi #1 and Pi #2. Both nodes use the GeeekPi dual mount's built-in PCIe adapters, so each Pi has its NVMe SSD appear as `/dev/nvme0n1`.

```bash
# Edit boot config
sudo nano /boot/firmware/config.txt

# Add at the bottom:
# Enable PCIe Gen 3 for NVMe performance
dtparam=pciex1_gen=3

# Reboot
sudo reboot
```

After reboot, verify PCIe Gen 3 is active and NVMe is detected:

```bash
# Verify PCIe Gen 3 link speed
sudo dmesg | grep -i pcie | grep -i gen

# Confirm NVMe device is present
lsblk
# Pi #1 should show: nvme0n1 (WD SN740 256GB)
# Pi #2 should show: nvme0n1 (Crucial P310 1TB)
```

**Pi #1 — partition and mount NVMe (256GB, comms storage):**
```bash
sudo mkfs.ext4 /dev/nvme0n1
sudo mkdir -p /mnt/nvme
sudo mount /dev/nvme0n1 /mnt/nvme

# Add to fstab — use UUID for reliability
sudo blkid /dev/nvme0n1    # note the UUID value
# Replace YOUR-UUID-HERE with actual UUID from blkid output:
echo 'UUID=YOUR-UUID-HERE /mnt/nvme ext4 defaults,noatime 0 2' | sudo tee -a /etc/fstab
```

**Pi #2 — partition NVMe (1TB, tactical/Monero storage):**

See Phase 5 (section 5.1) for the full Pi #2 partition layout and mount instructions.

---

### 3.5 Create Project Directory Structure

**Pi #1 (comms):**
```bash
sudo mkdir -p /opt/community-node/{config/{conduit,element,nginx/{ssl},i2pd,tor,cloudflared},data/{conduit,i2pd,tor,community-web},logs}
sudo chown -R $USER:$USER /opt/community-node
```

> The `community-web` directory must remain owned by the `ps` user so page updates can be deployed via `scp` without sudo. The `chown -R $USER` above sets this correctly at creation time. If you ever see scp updates not taking effect, re-run: `sudo chown -R ps:ps /opt/community-node/data/community-web/`

**Pi #2 (tactical):**
```bash
sudo mkdir -p /opt/tactical-node/{config/{mosquitto,headscale},data/{reticulum,nomadnet},logs}
sudo mkdir -p /mnt/nvme/monero/{data,wallets}
sudo chown -R $USER:$USER /opt/tactical-node
```

> The `/mnt/nvme` path for Monero will be set up in Phase 5 after partitioning the NVMe SSD.

---

### 3.6 Create .env Files (Before Any Deploy)

Each node needs a `.env` file in its project directory. The compose files read from these at startup. **Create these before running any `docker compose up`.**

**Pi #1 — `/opt/community-node/.env`:**
```bash
nano /opt/community-node/.env
```

```bash
# ── Image versions (pinned — update deliberately, not automatically) ──────
CONDUIT_VERSION=v0.10.12
ELEMENT_VERSION=v1.12.11
I2PD_VERSION=release-2.59.0

# ── Matrix server identity ────────────────────────────────────────────────
MATRIX_SERVER_NAME=m2.yourdomain.com

# ── Cloudflare Tunnel (only needed if using clearnet profile) ────────────
# Get this token from: dash.cloudflare.com → Zero Trust → Networks → Connectors
CLOUDFLARE_TUNNEL_TOKEN=CHANGE_ME_CLOUDFLARE_TOKEN
```

**Pi #2 — `/opt/tactical-node/.env`:**
```bash
nano /opt/tactical-node/.env
```

```bash
# ── Monero process user (must match your pi user UID/GID) ─────────────────
# Find yours with: id -u && id -g
FIXUID=1000
FIXGID=1000

# ── OpenTAK Server ────────────────────────────────────────────────────────
# OTS runs natively under systemd, not Docker.
# Admin password is set during the OTS installer — store in password manager.
# RabbitMQ password is set during OTS install.
# No .env variable needed here — OTS config is in /opt/opentakserver/
```

> Set permissions so only the `pi` user can read these files:
> ```bash
> chmod 600 /opt/community-node/.env
> chmod 600 /opt/tactical-node/.env
> ```

---

## 6. Phase 4: Node #1 — Communications Stack

All commands run on **Pi #1 (comms, 192.168.8.10)** unless noted.

### 4.1 Create the Docker Compose File

```bash
nano /opt/community-node/docker-compose.yml
```

```yaml
# /opt/community-node/docker-compose.yml
# Node #1 — Communications Stack

networks:
  community-net:
    driver: bridge
    ipam:
      config:
        - subnet: 172.20.0.0/24
  tor-net:
    driver: bridge
    internal: true
  i2p-net:
    driver: bridge
    internal: true

services:

  # ── Matrix homeserver ──────────────────────────────────────
  conduit:
    image: matrixconduit/matrix-conduit:${CONDUIT_VERSION:-v0.10.12}
    restart: unless-stopped
    networks:
      - community-net
    ports:
      - "127.0.0.1:6167:6167"   # localhost-only: admin tools use this; LAN clients use Nginx on :80
    volumes:
      - ./data/conduit:/var/lib/matrix-conduit
      - ./config/conduit/conduit.toml:/etc/matrix-conduit/conduit.toml:ro
    environment:
      CONDUIT_CONFIG: /etc/matrix-conduit/conduit.toml
    mem_limit: 512m
    healthcheck:
      test: ["CMD", "curl", "-sf", "http://localhost:6167/_matrix/client/versions"]
      interval: 30s
      timeout: 10s
      retries: 3

  # ── Element Web client ─────────────────────────────────────
  element-web:
    image: vectorim/element-web:${ELEMENT_VERSION:-v1.12.11}
    restart: unless-stopped
    networks:
      - community-net
    volumes:
      - ./config/element/element-config.json:/app/config.json:ro
    mem_limit: 64m

  # ── Nginx reverse proxy ────────────────────────────────────
  nginx:
    image: nginx:1.28.2-alpine3.23
    restart: unless-stopped
    networks:
      - community-net
    ports:
      - "80:80"
      - "443:443"
      - "8448:8448"
      - "8080:8080"
      - "8081:8081"
    volumes:
      - ./config/nginx/nginx.conf:/etc/nginx/nginx.conf:ro
      - ./config/nginx/ssl:/etc/nginx/ssl:ro
      - ./data/community-web:/var/www/html:ro
    mem_limit: 128m
    depends_on:
      - conduit
      - element-web

  # ── I2P router ─────────────────────────────────────────────
  i2pd:
    image: purplei2p/i2pd:${I2PD_VERSION:-release-2.59.0}
    restart: unless-stopped
    networks:
      - community-net
      - i2p-net
    ports:
      - "7070:7070"     # web console
      - "4444:4444"     # HTTP proxy
      - "4447:4447"     # SOCKS proxy
      - "7656:7656"     # SAM bridge
    volumes:
      - ./data/i2pd:/home/i2pd/data
      - ./config/i2pd/i2pd.conf:/home/i2pd/i2pd.conf:ro
      - ./config/i2pd/tunnels.conf:/home/i2pd/tunnels.conf:ro
    mem_limit: 256m

  # ── Tor hidden services ────────────────────────────────────
  tor:
    image: osminogin/tor-simple:0.4.8.21
    restart: unless-stopped
    networks:
      - community-net
      - tor-net
    volumes:
      - ./config/tor/torrc:/etc/tor/torrc:ro
      - ./data/tor:/var/lib/tor
    mem_limit: 128m

  # ── Cloudflare Tunnel (optional — disable when air-gapped) ──
  cloudflared:
    image: cloudflare/cloudflared:2026.2.0
    restart: unless-stopped
    networks:
      - community-net
    # Token-based auth — no local credentials file needed.
    # Ingress rules are configured in the Cloudflare dashboard (Zero Trust → Networks → Connectors → Configure → Published application routes).
    command: tunnel --no-autoupdate run --token ${CLOUDFLARE_TUNNEL_TOKEN}
    mem_limit: 128m
    profiles:
      - clearnet
      - full
```

---

### 4.1.5 Generate Security Tokens (Do This Before 4.2)

Two places in the config require strong random tokens. **Generate them now** and keep them in your password manager. You will use the same values in the config file AND in the registration curl command — if they don't match, registration will fail.

**Conduit registration token:**
```bash
openssl rand -hex 32
# Example: a3f8e1b2c4d5e6f7a8b9c0d1e2f3a4b5c6d7e8f9a0b1c2d3e4f5a6b7c8d9e0f1
# Replace every instance of CHANGE_ME_STRONG_RANDOM_TOKEN with this value
```

**OpenTAK Server admin password:**
Set during the OTS native installer (Phase 5B). Store in password manager. No .env variable needed.

> Store both tokens in your password manager before proceeding. You cannot recover them — you can only regenerate and re-register.

---

### 4.2 Configure Conduit (Matrix)

> **Tech debt:** `matrixconduit/matrix-conduit` is abandoned as of 2025. The active community fork is `conduwuit`. The image pinned here is used as-is through CCC26. Plan migration to conduwuit post-event. Do not change the image or config now.

**Two-server Matrix architecture:**

The M2 node runs as a standalone federated Matrix homeserver with `server_name = "m2.yourdomain.com"`. All Matrix IDs on this node take the form `@user:m2.yourdomain.com`. A separate permanent homeserver (`yourdomain.com`) will be built on M1 as the primary identity server — that server will carry the primary operator account and the family/trusted-circle Space. The M2 server federates with M1 and with the wider Matrix network, so users on either server can join the same rooms and spaces. The M2 node is field-portable; when airgapped, its users still function locally — federation simply pauses until internet is restored.

**Access paths:**
- **LAN (at the event):** GL.iNet DNS override resolves `m2-matrix.yourdomain.com` and `m2.yourdomain.com` to `192.168.8.10` — clients reach the node directly, no Cloudflare in the path
- **Clearnet (node has internet):** Cloudflare tunnel routes `m2-matrix.yourdomain.com` and `m2.yourdomain.com` to nginx on Pi #1 — any internet-connected device can reach Matrix and Element
- **Headscale VPN (enrolled devices, including airgapped):** Headscale-enrolled devices connect directly to Pi #1's Headscale IP — use `http://<pi1-headscale-ip>` or add a MagicDNS entry `comms.m2` → Pi #1 Headscale IP for named access

```bash
nano /opt/community-node/config/conduit/conduit.toml
```

```toml
[global]
server_name = "m2.yourdomain.com"
database_path = "/var/lib/matrix-conduit/"
database_backend = "rocksdb"
port = 6167
max_request_size = 20_000_000
allow_registration = false
registration_token = "CHANGE_ME_STRONG_RANDOM_TOKEN"
allow_federation = true
allow_public_room_creation = true
log = "warn,rocket::launch=info,_=off,sled=off"
address = "0.0.0.0"
```

> Change `registration_token` to a random string before deploying. Generate one:
> ```bash
> openssl rand -hex 32
> ```

---

### 4.3 Configure Element Web

```bash
nano /opt/community-node/config/element/element-config.json
```

> ⚠️ **JSON files do not support comments.** This file must contain ONLY the JSON block below — no explanatory text, no headers, no `//` or `#` lines above or around it. Any non-JSON content will cause Element to display "Your Element is misconfigured / invalid JSON" and refuse to load. The file must start with `{` as the very first character.

```json
{
  "default_server_config": {
    "m.homeserver": {
      "base_url": "https://m2-m2-matrix.yourdomain.com",
      "server_name": "m2.yourdomain.com"
    }
  },
  "brand": "Community Node",
  "disable_custom_urls": true,
  "disable_guests": true,
  "disable_login_language_selector": true,
  "default_theme": "dark"
}
```

After saving, verify the file starts with `{` and nothing else:
```bash
head -1 /opt/community-node/config/element/element-config.json
# Must output exactly: {
```

Then restart Element Web:
```bash
cd /opt/community-node && docker compose restart element-web
```

> **Why port 80 (not 6167):** Conduit listens on port 6167 inside its Docker container — that port is internal and not exposed to the LAN. Nginx proxies external requests to Conduit on your behalf. Element Web clients connect through Nginx on port 80, so `base_url` must point to port 80 (the default HTTP port, which can be omitted from the URL). Using `:6167` here would cause Element Web to send API calls directly to a port that LAN clients can't reach.

---

### 4.4 Configure Tor Hidden Services

```bash
nano /opt/community-node/config/tor/torrc
```

```
SocksPort 0.0.0.0:9050
DataDirectory /var/lib/tor

# Matrix homeserver hidden service
HiddenServiceDir /var/lib/tor/matrix_hidden_service/
HiddenServicePort 443 nginx:443
HiddenServicePort 8448 conduit:6167
HiddenServiceVersion 3

# Element Web hidden service
HiddenServiceDir /var/lib/tor/element_hidden_service/
HiddenServicePort 80 nginx:8080
HiddenServiceVersion 3

# Community page hidden service (community-web-index.html at nginx:8081)
HiddenServiceDir /var/lib/tor/community_hidden_service/
HiddenServicePort 80 nginx:8081
HiddenServiceVersion 3
```

---

### 4.5 TLS Certificate Setup (Let's Encrypt via Cloudflare DNS)

A browser-trusted TLS certificate is required for Element Web to function correctly over HTTPS. Use Let's Encrypt with the Cloudflare DNS-01 challenge — no open inbound ports required.

**Prerequisites:**
- Domain `yourdomain.com` must be managed by Cloudflare DNS
- A Cloudflare API token with **Zone → DNS → Edit** permission for `yourdomain.com`

**Step 1 — Install certbot:**
```bash
sudo apt update && sudo apt install -y certbot python3-certbot-dns-cloudflare
```

**Step 2 — Save API token:**
```bash
sudo mkdir -p /etc/letsencrypt
sudo nano /etc/letsencrypt/cloudflare.ini
```
File contents:
```
dns_cloudflare_api_token = YOUR_TOKEN_HERE
```
Lock it down:
```bash
sudo chmod 600 /etc/letsencrypt/cloudflare.ini
```

**Step 3 — Request certificate (single-line for copy/paste):**
```bash
sudo certbot certonly --dns-cloudflare --dns-cloudflare-credentials /etc/letsencrypt/cloudflare.ini -d m2-matrix.yourdomain.com -d communitynode.yourdomain.com -d m2.yourdomain.com --agree-tos --non-interactive --email YOUR_EMAIL_HERE
```

Certbot creates DNS TXT records via the API, verifies them, then issues the cert. Files land at:
- `/etc/letsencrypt/live/m2-matrix.yourdomain.com/fullchain.pem`
- `/etc/letsencrypt/live/m2-matrix.yourdomain.com/privkey.pem`

Auto-renewal is configured automatically by certbot (systemd timer or cron).

**Step 4 — Mount certs into nginx container:**

Add to the nginx `volumes:` block in `/opt/community-node/docker-compose.yml`:
```yaml
- /etc/letsencrypt:/etc/letsencrypt:ro
```

**Step 5 — Update nginx.conf cert paths:**

In `/opt/community-node/config/nginx/nginx.conf`, replace both occurrences of the self-signed cert paths:
```
ssl_certificate /etc/letsencrypt/live/m2-matrix.yourdomain.com/fullchain.pem;
ssl_certificate_key /etc/letsencrypt/live/m2-matrix.yourdomain.com/privkey.pem;
```

**Step 6 — Recreate nginx container to pick up new volume:**
```bash
cd /opt/community-node && sudo docker compose --profile clearnet up -d nginx
```

> **Note:** Use `docker compose up -d` (not `restart`) after any docker-compose.yml volume changes — `restart` does not recreate the container with updated mounts.

> **Self-signed cert:** The original self-signed cert at `config/nginx/ssl/` is no longer used for ports 443/8448. It can be left in place — nginx.conf no longer references it.

---

### 4.5.1 Create Nginx Configuration

```bash
nano /opt/community-node/config/nginx/nginx.conf
```

```nginx
worker_processes auto;
error_log /var/log/nginx/error.log warn;

events {
    worker_connections 256;
}

http {
    include /etc/nginx/mime.types;
    default_type application/octet-stream;
    sendfile on;
    keepalive_timeout 65;
    client_max_body_size 20M;

    # Rate limiting
    limit_req_zone $binary_remote_addr zone=matrix:10m rate=30r/s;
    limit_req_zone $binary_remote_addr zone=general:10m rate=10r/s;

    # ── Matrix API — HTTP (LAN access by IP, CF Tunnel clearnet) ──
    server {
        listen 80;
        listen [::]:80;
        server_name _;

        limit_req zone=matrix burst=50 nodelay;

        location /.well-known/matrix/server {
            default_type application/json;
            add_header Access-Control-Allow-Origin *;
            return 200 '{"m.server":"m2-matrix.yourdomain.com:443"}';
        }

        location /.well-known/matrix/client {
            default_type application/json;
            add_header Access-Control-Allow-Origin *;
            return 200 '{"m.homeserver":{"base_url":"https://m2-matrix.yourdomain.com"}}';
        }

        location / {
            proxy_pass http://conduit:6167;
            proxy_set_header Host $host;
            proxy_set_header X-Real-IP $remote_addr;
            proxy_set_header X-Forwarded-For $proxy_add_x_forwarded_for;
            proxy_set_header X-Forwarded-Proto $scheme;
            proxy_buffering off;
        }
    }

    # ── Matrix API — HTTPS (local TLS, Tor hidden service) ──────
    server {
        listen 443 ssl;
        listen [::]:443 ssl;
        server_name _;

        ssl_certificate /etc/nginx/ssl/fullchain.pem;
        ssl_certificate_key /etc/nginx/ssl/privkey.pem;
        ssl_protocols TLSv1.2 TLSv1.3;
        ssl_ciphers HIGH:!aNULL:!MD5;

        limit_req zone=matrix burst=50 nodelay;

        location /.well-known/matrix/server {
            default_type application/json;
            add_header Access-Control-Allow-Origin *;
            return 200 '{"m.server":"m2-matrix.yourdomain.com:443"}';
        }

        location /.well-known/matrix/client {
            default_type application/json;
            add_header Access-Control-Allow-Origin *;
            return 200 '{"m.homeserver":{"base_url":"https://m2-matrix.yourdomain.com"}}';
        }

        location / {
            proxy_pass http://conduit:6167;
            proxy_set_header Host $host;
            proxy_set_header X-Real-IP $remote_addr;
            proxy_set_header X-Forwarded-For $proxy_add_x_forwarded_for;
            proxy_set_header X-Forwarded-Proto https;
            proxy_buffering off;
        }
    }

    # ── Matrix Federation (port 8448) ────────────────────────────
    server {
        listen 8448 ssl;
        listen [::]:8448 ssl;
        server_name _;

        ssl_certificate /etc/nginx/ssl/fullchain.pem;
        ssl_certificate_key /etc/nginx/ssl/privkey.pem;
        ssl_protocols TLSv1.2 TLSv1.3;

        location / {
            proxy_pass http://conduit:6167;
            proxy_set_header Host $host;
            proxy_set_header X-Real-IP $remote_addr;
            proxy_buffering off;
        }
    }

    # ── Element Web (port 8080 — Tor/I2P access) ─────────────────
    server {
        listen 8080;
        listen [::]:8080;
        server_name _;

        limit_req zone=general burst=20 nodelay;

        location / {
            proxy_pass http://element-web:80;
            proxy_set_header Host $host;
            proxy_set_header X-Real-IP $remote_addr;
        }
    }

    # ── Community Web (port 8081 — static pages) ─────────────────
    server {
        listen 8081;
        listen [::]:8081;
        server_name _;

        limit_req zone=general burst=20 nodelay;

        root /var/www/html;
        index index.html;

        location / {
            try_files $uri $uri/ =404;
        }
    }
}
```

---

### 4.5.2 Create i2pd Configuration

```bash
nano /opt/community-node/config/i2pd/i2pd.conf
```

```ini
[general]
loglevel = warn
logfile = /home/i2pd/data/i2pd.log

[system]
# L = 32 KBps shared — adequate for community node, conserves Pi resources
bandwidth = L

[http]
enabled = true
address = 0.0.0.0
port = 7070

[httpproxy]
enabled = true
address = 0.0.0.0
port = 4444

[socksproxy]
enabled = true
address = 0.0.0.0
port = 4447

[sam]
enabled = true
address = 0.0.0.0
port = 7656

[ntcp2]
enabled = true
port = 0

[ssu2]
enabled = true
port = 0
```

```bash
nano /opt/community-node/config/i2pd/tunnels.conf
```

```ini
# I2P tunnel for Matrix API (routes via nginx on Docker network)
[matrix-i2p]
type = http
host = nginx
port = 80
keys = matrix-i2p.dat

# I2P eepsite for community web pages (routes via nginx on Docker network)
[community-eepsite]
type = http
host = nginx
port = 8081
keys = community-eepsite.dat
```

---

### 4.5.3 Cloudflare Tunnel Setup (Clearnet Access)

The `CLOUDFLARE_TUNNEL_TOKEN` in comms `.env` enables clearnet access to Matrix, Element, and TAK when the node has internet. No local config file is needed — all ingress routing is configured in the Cloudflare dashboard.

**Steps:**
1. Go to `dash.cloudflare.com` → Zero Trust → Networks → Connectors
2. Click **Create a connector** → name it `m2-community-node`
3. Copy the tunnel token — paste it into `/opt/community-node/.env` as `CLOUDFLARE_TUNNEL_TOKEN=<token>`
4. Click the connector name → **Configure** → **Published application routes** tab → add each route:

| Subdomain | Domain | Service |
|---|---|---|
| `matrix` | `yourdomain.com` | `http://nginx:80` |
| `m2` | `yourdomain.com` | `http://nginx:80` |
| `element` | `yourdomain.com` | `http://nginx:8080` |
| `tak` | `yourdomain.com` | `http://192.168.8.20:8080` |

5. Save — the tunnel will connect automatically when cloudflared starts with the `clearnet` profile.

> **Note:** Use container names (`nginx:80`, `nginx:8080`) for services on the **same** Docker host (Pi #1). Use the LAN IP (`192.168.8.20`) for services on Pi #2 — cloudflared can reach the LAN from inside Docker via the host's routing table.

> **TLS:** Cloudflare terminates HTTPS for clearnet traffic. The tunnel delivers plain HTTP to nginx internally. The Let's Encrypt cert handles port 443 for LAN HTTPS access (via GL.iNet hosts file override).

> **OTS Web Map access:** `https://tak.yourdomain.com` gives anyone with the URL a live view of the tactical map — team positions, markers, data packages. This is view + admin access to OTS, so protect it with Cloudflare Access (§4.5.4) before enabling in production.

---

### 4.5.4 Cloudflare Access — Zero Trust Gate (Optional)

Cloudflare Access puts a login screen in front of any tunnel route. Without it, anyone who discovers `tak.yourdomain.com` or `communitynode.yourdomain.com` can access the service directly. With it, users must authenticate before Cloudflare proxies their request.

**What it is:** Cloudflare's zero-trust reverse proxy. Runs entirely on Cloudflare's infrastructure — no software on your Pis. Free tier supports 50 users.

**Step 1 — Create the Access Application**

1. `dash.cloudflare.com` → Zero Trust → Access controls → Applications → **Add an application**
2. Select type: **Self-hosted**
3. Application name: `OTS Web Map`
4. Session Duration: `24 hours`
5. Click **+ Add public hostname** — this expands the domain fields:
   - Subdomain: `tak`
   - Domain: select `yourdomain.com` from the dropdown
6. Scroll down past Browser rendering settings (leave defaults)

**Step 2 — Create an Access Policy**

Still on the same page, scroll to **Create reusable application policies** → click the blue **Add a policy** button:

| Field | Value |
|---|---|
| Policy name | `Approved Operators` |
| Action | `Allow` |
| Include rule | Emails — add each approved operator's email |

> For quick field deployment, use **Email one-time PIN** as the identity provider. Users enter their email, get a 6-digit code, and are in. No accounts, no passwords, no OAuth setup.

7. Click **Next** through Experience settings and Advanced settings (leave defaults)
8. Click **Save**

**Step 3 — Verify the identity provider**

1. Zero Trust → Settings → Authentication → Login methods
2. Confirm **One-time PIN** is enabled (should be on by default)
3. Optionally add Google or GitHub for permanent team members

**Step 4 — Repeat for other sensitive routes**

Create separate Access applications for:

| Route | Recommended? | Why |
|---|---|---|
| `tak.yourdomain.com` | **Yes** | Full OTS admin + live map |
| `communitynode.yourdomain.com` | Optional | Element Web is already behind Matrix login |
| `m2-matrix.yourdomain.com` | No | Federation requires unauthenticated access |

> **Field tradeoff:** During an active incident, you may want to temporarily remove Access from the OTS web map so any responder can see positions without authenticating. Toggle the policy off in the dashboard — takes effect immediately.

> **Note:** Do not apply Cloudflare Access to `m2-matrix.yourdomain.com` or `m2.yourdomain.com` — federation requires unauthenticated access for server-to-server requests. Locking these routes breaks federation with external Matrix servers.

---

### 4.5.5 Verify Federation

Run this after the Cloudflare tunnel is active and Conduit is up.

**Step 1 — Confirm `.well-known` delegation resolves:**

```bash
curl -s https://m2.yourdomain.com/.well-known/matrix/server
curl -s https://m2.yourdomain.com/.well-known/matrix/client
```

Expected:
```json
{"m.server":"m2-matrix.yourdomain.com:443"}
{"m.homeserver":{"base_url":"https://m2-matrix.yourdomain.com"}}
```

**Step 2 — Run the Matrix federation tester:**

From any browser: `https://federationtester.matrix.org/#m2.yourdomain.com`

Expected: all checks green. Common failures:
- **DNS resolution failed** — `m2.yourdomain.com` Cloudflare tunnel route missing or not yet propagated
- **Connection refused on :8448** — federation is served on port 443 via `.well-known` delegation; if the tester tries 8448 directly, the `.well-known` response was not returned correctly
- **Certificate error** — cert does not cover `m2.yourdomain.com`; re-issue certbot with `-d m2.yourdomain.com` added

**Step 3 — Test a cross-server room join:**

From an account on `matrix.org` (or any other public homeserver), join a room hosted on `m2.yourdomain.com` using the full room alias. Confirm messages deliver in both directions.

---

### 4.6 Start Node #1 Stack

```bash
cd /opt/community-node

# Start core services (no Cloudflare tunnel yet)
docker compose up -d conduit element-web nginx i2pd tor

# Check logs
docker compose logs -f --tail=50

# Verify all containers are healthy
docker compose ps
```

**Wait ~2 minutes for Conduit to initialize**, then register the admin user:

```bash
curl -X POST "http://localhost:6167/_matrix/client/v3/register" \
  -H "Content-Type: application/json" \
  -d '{
    "username": "admin",
    "password": "STRONG_PASSWORD_HERE",
    "auth": {
      "type": "m.login.registration_token",
      "token": "CHANGE_ME_STRONG_RANDOM_TOKEN"
    }
  }'
```

**Retrieve Tor .onion addresses (after ~5 min for Tor to bootstrap):**

```bash
docker exec tor cat /var/lib/tor/matrix_hidden_service/hostname
docker exec tor cat /var/lib/tor/element_hidden_service/hostname
docker exec tor cat /var/lib/tor/community_hidden_service/hostname
```

> Record your .onion addresses — you will need them for QR codes, kiosk config, and sharing with members:
>
> | Service | .onion Address |
> |---|---|
> | Matrix API (homeserver) | *(paste output of first command above)* |
> | Element Web (chat client) | *(paste output of second command above)* |
> | Community Page (info/connect) | *(paste output of third command above)* |
>
> All three require Tor Browser. The community page onion is the recommended link to share with new members — it loads the info and connection guide. The Element Web onion is for direct chat access. Point Matrix clients (FluffyChat, Element mobile) at the Matrix API onion as the homeserver.

---

### 4.7 AdGuard DNS Setup (Split-DNS)

AdGuard runs on Pi #1 as the LAN DNS resolver. Its critical job is **split-DNS**: intercepting DNS queries from devices on the network and resolving your service domains to their LAN IPs instead of the public internet. Without this, ATAK cert enrollment, Element, and Headscale connections all leave the LAN to reach Cloudflare — which means they fail when internet is down.

**Start the container:**

```bash
# [SSH — comms-lan]
cd /opt/community-node
docker compose up -d adguard
docker compose logs adguard --tail=20
```

**First-run wizard** — open `http://192.168.8.10:3000` from a browser on the LAN:

1. Click **Get Started**
2. Leave Admin Web Interface on port `3000`
3. Leave DNS server on port `53` — this must stay as-is
4. Set an admin username and password — store in `M2_SECRETS.md`
5. Click **Next** through the remaining screens, then **Open Dashboard**

**Add DNS rewrites** — in the AdGuard dashboard, go to **Filters → DNS rewrites → Add DNS rewrite**:

| Domain | Answer |
|---|---|
| `element.yourdomain.com` | `192.168.8.10` |
| `m2-matrix.yourdomain.com` | `192.168.8.10` |
| `tak.yourdomain.com` | `192.168.8.20` |
| `m2vpn.yourdomain.com` | `192.168.8.20` |
| `atakenroll.yourdomain.com` | `192.168.8.20` |

Replace `yourdomain.com` with your actual domain. Add one entry at a time — each domain gets its own row.

**Configure the router to use AdGuard as DNS** — on the GL.iNet admin panel:

1. Go to **Network → DHCP**
2. Set **DNS Server 1** to `192.168.8.10`
3. Clear DNS Server 2 (leave blank or set to `1.1.1.1` as fallback)
4. Save and apply

Devices that reconnect to WiFi will now receive AdGuard as their DNS server. Existing connections need to reconnect or flush their DNS cache (`ipconfig /flushdns` on Windows, toggle WiFi on Android/iOS).

**Verify:**

```bash
# From a device on the LAN — should return 192.168.8.10 (not a Cloudflare IP)
nslookup element.yourdomain.com 192.168.8.10

# Should return 192.168.8.20
nslookup atakenroll.yourdomain.com 192.168.8.10
```

> **Why this matters for ATAK:** The cert enrollment page is served from `atakenroll.yourdomain.com:8447`. If DNS resolves that domain to a Cloudflare IP, ATAK's enrollment flow goes out to the internet and fails when you're offline. With the split-DNS rewrite, it resolves directly to Pi #2's LAN IP and works with no internet required.

---

## 7. Phase 5: Node #2 — Tactical/Crypto Stack

All commands run on **Pi #2 (tactical, 192.168.8.20)** unless noted.

### 5.1 Partition and Mount the 1TB NVMe SSD (Pi #2)

Pi #2's Crucial P310 1TB NVMe is already physically installed in the GeeekPi dual mount's right NVMe adapter slot and appears as `/dev/nvme0n1` after the PCIe Gen 3 configuration in Phase 3.

**Recommended approach: OS stays on microSD, NVMe is data-only.**
This is simpler, provides automatic fallback boot from microSD, and requires no EEPROM changes.

Partition layout:
```
/dev/nvme0n1p1    900GB   /mnt/nvme        (ext4, Monero + ATAK data + backups)
(~100GB unpartitioned for wear leveling)
```

```bash
# Verify NVMe is present
lsblk
# Should show: nvme0n1 (1TB NVMe)

# Create a single data partition (no boot partition needed — OS stays on microSD)
sudo fdisk /dev/nvme0n1
# Create p1: +900G  (ext4 — /mnt/nvme)
# Leave remaining ~100GB unpartitioned for wear leveling
# Write and exit

# Format the data partition
sudo mkfs.ext4 /dev/nvme0n1p1

# Mount
sudo mkdir -p /mnt/nvme
sudo mount /dev/nvme0n1p1 /mnt/nvme

# Auto-mount on boot — use UUID (more reliable than device name; name can shift if drives are added)
sudo blkid /dev/nvme0n1p1    # copy the UUID value from this output
echo 'UUID=YOUR-UUID-HERE /mnt/nvme ext4 defaults,noatime 0 2' | sudo tee -a /etc/fstab
# Replace YOUR-UUID-HERE with the actual UUID from blkid output above

# Create directory structure
sudo mkdir -p /mnt/nvme/monero/{data,wallets}
sudo chown -R $USER:$USER /mnt/nvme
```

> **Optional: migrate OS to NVMe after initial build is confirmed working.** To boot from NVMe: `sudo raspi-config` → Advanced Options → Boot Order → NVMe/USB Boot. Then clone microSD to NVMe using `rpi-clone` or `dd`. Only do this after all services are running and stable — the microSD is your recovery boot until then.

> Performance note: NVMe via the GeeekPi dual mount's PCIe adapter delivers approximately 106,000–197,000 4K random IOPS (Gen 3 with `dtparam=pciex1_gen=3`), versus ~29,000 IOPS on a USB SATA adapter — a 3.5–7× improvement that benefits Monero's LMDB database performance.

---

### 5.2 Transfer Monero LMDB to Pi #2

**Your x86 pre-sync from Phase 0 must be complete before this step.**

The Monero LMDB data folder is typically ~95–110 GB pruned.

**Stop monerod on your x86 machine first** — LMDB will corrupt if copied while running.
- Windows: close the monerod window or kill the process in Task Manager
- Linux: `kill $(pgrep monerod)`

#### Option A — USB stick (recommended if on WiFi)

1. Format a 128GB+ USB stick as exFAT or NTFS
2. Copy `C:\MoneroNode\data\lmdb` folder to the root of the stick on Windows
3. Plug stick into Pi #2 front USB 3.0 port
4. On Pi #2:

```bash
# Find the USB stick device
lsblk
# It will appear as /dev/sda1 or similar

# Mount it
sudo mkdir -p /mnt/usb
sudo mount /dev/sda1 /mnt/usb

# Copy LMDB to NVMe
mkdir -p /mnt/nvme/monero/data/lmdb
cp -r /mnt/usb/lmdb/. /mnt/nvme/monero/data/lmdb/

# Unmount and remove stick
sudo umount /mnt/usb
```

> USB 3.0 stick transfers ~95GB in 15–30 minutes. Far faster than WiFi rsync.

#### Option B — Rsync over network

```bash
# From WSL on Windows:
wsl rsync -avP /mnt/c/MoneroNode/data/lmdb/ pi@192.168.8.20:/mnt/nvme/monero/data/lmdb/

# From Git Bash on Windows:
rsync -avP /c/MoneroNode/data/lmdb/ pi@192.168.8.20:/mnt/nvme/monero/data/lmdb/
```

> On gigabit wired LAN: ~15–20 minutes. On WiFi: 1–2 hours.

---

### 5.3 Create the Docker Compose File

```bash
nano /opt/tactical-node/docker-compose.yml
```

```yaml
# /opt/tactical-node/docker-compose.yml
# Node #2 — Tactical/Crypto Stack

services:

  # ── Monero node ────────────────────────────────────────────
  monerod:
    image: ghcr.io/sethforprivacy/simple-monerod:v0.18.4.5
    restart: unless-stopped
    user: "${FIXUID:-1000}:${FIXGID:-1000}"
    network_mode: host
    volumes:
      - /mnt/nvme/monero/data:/home/monero/.bitmonero
    command:
      - --rpc-restricted-bind-ip=127.0.0.1
      - --rpc-restricted-bind-port=18089
      # SECURITY: RPC is localhost-only. Access remotely via Tailscale/Headscale VPN.
      # Removed: --confirm-external-bind (not needed for localhost bind)
      # Removed: --public-node (incompatible with localhost-only RPC)
      - --no-igd
      - --prune-blockchain
      - --db-sync-mode=safe:sync
      - --enable-dns-blocklist
      - --out-peers=32
      - --in-peers=64
      - --limit-rate-up=1048576
      - --limit-rate-down=1048576
      - --log-level=0
    deploy:
      resources:
        limits:
          memory: 4G
          cpus: "2.0"
        reservations:
          memory: 1G
    healthcheck:
      test: ["CMD", "curl", "-sf", "http://127.0.0.1:18089/get_info"]
      # 18089 = restricted RPC (the port actually bound by --rpc-restricted-bind-port)
      # 18081 = unrestricted full RPC (not opened — healthcheck was wrong)
      interval: 60s
      timeout: 15s
      retries: 3

  # ── OpenTAK Server (ATAK) ─────────────────────────────────
  # OTS runs NATIVELY under systemd — NOT in Docker.
  # Install: see Phase 5B below.
  # Status: systemctl status opentakserver
  # Ports: 8080 (HTTP UI), 8088 (CoT TCP), 8089 (CoT SSL),
  #        8443 (HTTPS UI), 8446 (cert enrollment)
  # Web UI: http://192.168.8.20:8080

  # ── Reticulum + NomadNet ───────────────────────────────────
  # WARNING: this container runs pip install on every startup.
  # In air-gap/offline mode this will fail on cold start — container will not launch
  # because pip cannot reach PyPI. Long-term fix: build a custom image with packages
  # baked in. For field deployment, ensure at least one successful startup with internet
  # access before going air-gap. Packages are also unpinned — pin them in a future sprint.
  reticulum:
    image: python:3.12.12-slim-bookworm
    restart: unless-stopped
    network_mode: host
    command: >
      bash -c "pip install --upgrade pip -q &&
               pip install --quiet rns nomadnet lxmf &&
               rnsd --config /root/.reticulum -v"
    # -v = verbose logging to stdout (captured by Docker)
    # Monitor with: docker compose logs --tail=50 reticulum
    # Live status:  docker exec tactical-node-reticulum-1 rnstatus
    devices:
      - /dev/ttyUSB0:/dev/ttyUSB0   # Heltec V3 LEFT RNode LoRa (connect in Phase 6)
    volumes:
      - ./data/reticulum:/root/.reticulum
    ports:
      - "4242:4242"     # TCP interface
      - "37428:37428"   # shared instance

  nomadnet:
    image: python:3.12.12-slim-bookworm
    restart: unless-stopped
    network_mode: host
    command: >
      bash -c "pip install --quiet nomadnet &&
               nomadnet --daemon --config /root/.nomadnetwork"
    volumes:
      - ./data/nomadnet:/root/.nomadnetwork
    depends_on:
      - reticulum

  # ── MQTT Broker ────────────────────────────────────────────
  mosquitto:
    image: eclipse-mosquitto:2.0.22
    restart: unless-stopped
    ports:
      - "1883:1883"
      - "9001:9001"
    volumes:
      - ./config/mosquitto/mosquitto.conf:/mosquitto/config/mosquitto.conf:ro
      - ./data/mosquitto:/mosquitto/data
      - ./logs/mosquitto:/mosquitto/log

  # ── Headscale (Tailscale control plane) ───────────────────
  headscale:
    # ⚠️ Breaking changes between 0.23 and 0.28 — read: github.com/juanfont/headscale/releases
    # Key changes: removed `headscale nodes move`, stricter SSH policy, tags-as-identity
    image: headscale/headscale:0.28.0
    restart: unless-stopped
    ports:
      - "443:443"
      - "50443:50443"
    volumes:
      - ./config/headscale:/etc/headscale
      - ./data/headscale:/var/lib/headscale
      - /etc/letsencrypt:/etc/letsencrypt:ro
    command: serve
    profiles:
      - vpn
      - full

volumes:
  monero-data:
    driver: local
    driver_opts:
      type: none
      o: bind
      device: /mnt/nvme/monero/data
  wallet-data:
    driver: local
    driver_opts:
      type: none
      o: bind
      device: /mnt/nvme/monero/wallets
```

---

### 5.3.1 Configure Mosquitto

The Mosquitto container **will crash on startup without a config file** — it requires one at `/mosquitto/config/mosquitto.conf`. Create it before the first `docker compose up`:

```bash
mkdir -p /opt/tactical-node/config/mosquitto
nano /opt/tactical-node/config/mosquitto/mosquitto.conf
```

```
# Mosquitto 2.x minimal configuration for community node
# https://mosquitto.org/man/mosquitto-conf-5.html

# ── Persistence ──────────────────────────────────────────────────────────
persistence true
persistence_location /mosquitto/data/
log_dest file /mosquitto/log/mosquitto.log
log_type error
log_type warning
log_type notice
log_type information

# ── Local LAN listener (unauthenticated — LAN-only, no internet exposure) ─
listener 1883 0.0.0.0
allow_anonymous true

# ── WebSocket listener (for browser-based MQTT clients) ──────────────────
listener 9001 0.0.0.0
protocol websockets
allow_anonymous true

# ── NOTES ─────────────────────────────────────────────────────────────────
# This config is intentionally open for LAN use.
# If you expose Mosquitto beyond the LAN (e.g., via Tailscale):
#   1. Set allow_anonymous false
#   2. Create a password file: mosquitto_passwd /mosquitto/config/passwd <user>
#   3. Add: password_file /mosquitto/config/passwd
#   4. Consider TLS: add certfile/keyfile/cafile directives
```

---

### 5.3.2 Configure Headscale

Headscale requires both a TLS certificate and a `config.yaml` before it will start.

**Step 1 — Issue TLS certificate for Headscale**

```bash
sudo apt-get update && sudo apt-get install -y certbot python3-certbot-dns-cloudflare
```

```bash
sudo mkdir -p /etc/cloudflare
```

```bash
sudo sh -c 'echo "dns_cloudflare_api_token = YOUR_CLOUDFLARE_API_TOKEN" > /etc/cloudflare/cloudflare.ini'
```

```bash
sudo chmod 600 /etc/cloudflare/cloudflare.ini
```

```bash
sudo certbot certonly --dns-cloudflare --dns-cloudflare-credentials /etc/cloudflare/cloudflare.ini -d m2vpn.yourdomain.com --email YOUR_EMAIL --agree-tos --non-interactive
```

Certificate saved at: `/etc/letsencrypt/live/m2vpn.yourdomain.com/fullchain.pem`

**Step 2 — Add certbot renewal hook**

```bash
sudo sh -c 'echo "#!/bin/bash" > /etc/letsencrypt/renewal-hooks/deploy/headscale.sh'
```

```bash
sudo sh -c 'echo "docker compose -f /opt/tactical-node/docker-compose.yml --profile vpn restart headscale" >> /etc/letsencrypt/renewal-hooks/deploy/headscale.sh'
```

```bash
sudo chmod +x /etc/letsencrypt/renewal-hooks/deploy/headscale.sh
```

**Step 3 — Create config.yaml**

```bash
mkdir -p /opt/tactical-node/config/headscale
nano /opt/tactical-node/config/headscale/config.yaml
```

```yaml
# Headscale 0.28.0 — Self-hosted Tailscale coordination server
  # Full reference: headscale.net/docs/ref/configuration/
  #
  # IMPORTANT: All keys in this file use 2-space indentation throughout.
  # This is intentional — do not mix indentation levels or the YAML parser will fail.
  # IMPORTANT: Headscale 0.28.0 has breaking changes from 0.23

  # ── Server identity ───────────────────────────────────────────────────────────
  server_url: "https://m2vpn.yourdomain.com"
  listen_addr: "0.0.0.0:443"
  tls_cert_path: /etc/letsencrypt/live/m2vpn.yourdomain.com/fullchain.pem
  tls_key_path: /etc/letsencrypt/live/m2vpn.yourdomain.com/privkey.pem
  metrics_listen_addr: "127.0.0.1:9090"
  grpc_listen_addr: "0.0.0.0:50443"
  grpc_allow_insecure: false

  # ── Key material ──────────────────────────────────────────────────────────────
  private_key_path: /var/lib/headscale/private.key
  noise:
    private_key_path: /var/lib/headscale/noise_private.key

  # ── VPN address pool ──────────────────────────────────────────────────────────
  prefixes:
    v4: "100.64.1.0/24"
    v6: "fd7a:115c:a1e0::/48"
  allocation: sequential

  # ── DNS ───────────────────────────────────────────────────────────────────────
  dns:
    magic_dns: true
    base_domain: vpn.community.local
    nameservers:
      global:
        - 8.8.8.8
        - 1.1.1.1

  # ── Database ──────────────────────────────────────────────────────────────────
  database:
    type: sqlite3
    sqlite:
      path: /var/lib/headscale/db.sqlite

  log:
    level: info

  # ── DERP relay servers ────────────────────────────────────────────────────────
  derp:
    server:
      enabled: false
    urls:
      - https://controlplane.tailscale.com/derpmap/default
    auto_update_enabled: true
    update_frequency: 24h
```

**Step 4 — Start Headscale and create users**

```bash
cd /opt/tactical-node && sudo docker compose --profile vpn up -d headscale
```

```bash
sudo docker exec tactical-node-headscale-1 headscale users create admin
```

```bash
sudo docker exec tactical-node-headscale-1 headscale users create community
```

```bash
sudo docker exec tactical-node-headscale-1 headscale preauthkeys create --user 1 --expiration 90d --reusable
```

**Step 5 — Connect client devices**

**[Windows — PowerShell Administrator]**
```powershell
tailscale up --login-server https://m2vpn.yourdomain.com --authkey <key> --reset
```

**Step 6 — Rename nodes**

```bash
sudo docker exec tactical-node-headscale-1 headscale nodes rename --identifier 1 mike-pc
```

> **Container name:** Always use `tactical-node-headscale-1` (not `headscale`) for `docker exec` commands.

---

### 5.3.3 Monero Wallet RPC

#### What This Is and Why You Want It

**The one-sentence pitch:** Your community can transact in Monero without trusting anyone outside the community — ever.

When a community member uses Monero — even with their own wallet on their own phone — their wallet has to ask *someone's* server "is this transaction valid?" By default, that's a random stranger's node. That stranger sees their transaction queries, can correlate addresses to IPs, and can lie about balances.

The community node's `monerod` gives members a node they trust by provenance — run by their own community, on hardware they can physically inspect. `monero-wallet-rpc` is the operator layer on top of that: it lets the community receive donations, verify payments, and manage a community fund wallet programmatically — all self-verified, no third party ever in the loop.

Running Monero without a trusted node is like running Matrix but routing your messages through Signal's servers. The node exists — wallet-rpc is what makes it *usable as an institution*, not just a relay others happen to connect to.

---

The community node runs a full Monero node (`monerod`) that stays synced to the live blockchain. That node is the foundation — but to actually USE it from a wallet, you have two options:

**Option A — Point your existing wallet at the node as its daemon (no wallet-rpc needed):**
Any Monero wallet (Feather, Cake, monero-gui) lets you specify a custom daemon address. Point it to the community node's `monerod` and your wallet software queries YOUR node instead of a random third-party node. Your private keys never leave your device — the node just answers blockchain questions. This is the privacy benefit. Anyone on the community node's Tailscale network can do this.

**Option B — Monero Wallet RPC (operator wallet on the Pi):**
`monero-wallet-rpc` is a JSON-RPC API server that wraps a wallet file on Pi #2. The wallet file lives on the Pi — it holds a set of Monero private keys and syncs its history against the local `monerod`. This is for the operator: receiving community donations, generating subaddresses for different purposes, checking balances, or automating payment verification via API. Access is SSH-tunnel-only — it is never exposed to LAN or clearnet.

**The two options are independent.** Community members use Option A (point their wallet at the daemon). The operator uses Option B for the community fund wallet. Both verify transactions against the same local `monerod` node.

> **Key point:** The wallet file created in this section is the operator's community node wallet. It is NOT a passthrough for other people's wallets. If you want to use your personal existing wallet, restore it from its 25-word seed in Step 1 below. If you want a fresh community wallet, generate a new one.

---

#### Step 1 — Create the Wallet File (interactive — SAVE THE SEED)

**[SSH — Pi #2]**

```bash
monero-wallet-cli --daemon-address=127.0.0.1:18081 --trusted-daemon --generate-new-wallet=/mnt/nvme/monero/wallets/community
```

The CLI will prompt you for:
1. **Password** — set a strong password and write it down; you'll need it for the service file
2. **Language** — choose `English` (option 1) for the 25-word seed
3. The **25-word seed phrase** will be printed — **write it down immediately and store offline**

To use your existing wallet instead of generating a new one, replace `--generate-new-wallet` with `--restore-deterministic-wallet` and enter your existing seed when prompted.

After the wallet is created, type `exit` to quit the CLI.

---

#### Step 2 — Create the RPC Credentials File

**[SSH — Pi #2]**

```bash
echo "community:REPLACE_WITH_STRONG_PASSWORD" > /mnt/nvme/monero/wallets/.rpc-login
```

```bash
chmod 600 /mnt/nvme/monero/wallets/.rpc-login
```

Replace `REPLACE_WITH_STRONG_PASSWORD` with a unique password (different from the wallet password). This is the HTTP digest auth credential used to connect to the RPC endpoint.

**Also create the wallet password file** (this is the wallet encryption password you set during `monero-wallet-cli` creation — NOT the RPC credential above):

```bash
nano /mnt/nvme/monero/wallets/.wallet-password
```

Type just the wallet password, nothing else. Save and exit.

```bash
chmod 600 /mnt/nvme/monero/wallets/.wallet-password
```

---

#### Step 3 — Create the Systemd Service

**[SSH — Pi #2]**

```bash
sudo nano /etc/systemd/system/monero-wallet-rpc.service
```

Paste the following — use **nano**, one line at a time is fine:

```ini
# monero-wallet-rpc.service
# Exposes the community Monero wallet as a JSON-RPC API on loopback only.
# Access via SSH tunnel: ssh -L 18083:localhost:18083 tactical
# Never expose port 18083 to LAN or clearnet.

[Unit]
Description=Monero Wallet RPC
After=network.target

[Service]
User=ps
# --rpc-bind-ip=127.0.0.1 — loopback only; SSH tunnel required for remote access
# --trusted-daemon — skip Monero's spam-prevention checks (safe because we control monerod)
# --password-file — wallet encryption password (different from RPC auth credentials)
# --rpc-login — HTTP digest auth for the RPC endpoint (username:password)
# Port 18083 — wallet-rpc. Monerod uses 18080 (P2P) + 18081 (RPC); wallet-rpc must use a different port.
ExecStart=/usr/local/bin/monero-wallet-rpc --daemon-address=127.0.0.1:18081 --trusted-daemon --rpc-bind-ip=127.0.0.1 --rpc-bind-port=18083 --wallet-file=/mnt/nvme/monero/wallets/community --password-file=/mnt/nvme/monero/wallets/.wallet-password --rpc-login=community:REPLACE_WITH_RPC_PASSWORD --log-level=0 --log-file=/var/log/monero-wallet-rpc.log
Restart=on-failure
RestartSec=10

[Install]
WantedBy=multi-user.target
```

```bash
sudo systemctl daemon-reload
```

```bash
sudo systemctl enable monero-wallet-rpc
```

```bash
sudo systemctl start monero-wallet-rpc
```

```bash
sudo systemctl status monero-wallet-rpc
```

Expected: `Active: active (running)`. It will take 1–2 minutes to complete the initial wallet scan against the local `monerod` blockchain.

---

#### Step 4 — Confirm Port 18083 Is Loopback Only

The service binds to `127.0.0.1` (loopback only), so it is inaccessible from the network. Confirm with:

**[SSH — Pi #2]**

```bash
ss -tlnp | grep 18083
```

Expected output includes `127.0.0.1:18083` — not `0.0.0.0:18083`. If you see `0.0.0.0`, the `--rpc-bind-ip` flag is wrong — fix it in the systemd unit.

---

#### Step 5 — Test via SSH Tunnel

**[Windows — PowerShell]**

```powershell
ssh -L 18083:localhost:18083 tactical
```

Leave that SSH session open. Test the RPC from the **Pi itself** (PowerShell mangles JSON quoting — always test from the Pi):

**[SSH — Pi #2]**

```bash
curl --digest -u community:REPLACE_WITH_RPC_PASSWORD -d '{"jsonrpc":"2.0","id":"0","method":"get_balance"}' -H "Content-Type: application/json" http://127.0.0.1:18083/json_rpc
```

Expected: JSON response containing `"balance"` and `"unlocked_balance"`. If you see a `401 Unauthorized`, the credentials don't match the `--rpc-login` value in the systemd service file.

> **Note:** monero-wallet-rpc uses HTTP **digest** auth (not basic). The `--digest` flag is required with curl. Feather Wallet handles this automatically.

---

#### Step 6 — Connect Feather Wallet via SSH Tunnel

This is how you use Feather Wallet on Windows against the community node's wallet-rpc:

**[Windows — PowerShell (keep this session open)]**

```powershell
ssh -L 18083:localhost:18083 tactical
```

In Feather Wallet:
1. **File → Settings → Node** — set to `127.0.0.1:18081` (via a separate SSH tunnel to Pi #2) or via Tailscale/Headscale VPN using the Tailscale IP `100.64.1.1:18089` (Monero RPC is bound to 127.0.0.1 on Pi #2 and is not reachable from LAN WiFi)
2. To use wallet-rpc instead: **File → Open from node** → enter `http://127.0.0.1:18083` with credentials `community` / your RPC password

> **Most users should just use Option A** (set Feather's node to `100.64.1.1:18089` via Tailscale VPN, or SSH-tunnel to `127.0.0.1:18081`) and keep their wallet file on their own machine. wallet-rpc is for the operator managing the community wallet. Note: `192.168.8.20:18089` is NOT reachable from LAN — RPC is localhost-only on Pi #2.

---

#### Wallet RPC Log and Status

**[SSH — Pi #2]**

```bash
sudo journalctl -u monero-wallet-rpc -f
```

```bash
sudo journalctl -u monero-wallet-rpc --since "10 minutes ago"
```

---

#### Community Member Access (Option A — No wallet-rpc required)

Any community member connected via Tailscale/Headscale can point their Feather Wallet at the node's restricted RPC. The RPC is bound to `127.0.0.1` on Pi #2 — it is not reachable from LAN WiFi directly. Access requires Tailscale VPN:

**Feather Wallet → File → Settings → Node:**

```
http://100.64.1.1:18089
```

> LAN WiFi clients (`192.168.8.x`) cannot reach port 18089 directly — the RPC is localhost-only on Pi #2. Tailscale VPN is required. Community members must be enrolled in Headscale VPN to use the node as their daemon.

This gives them transaction verification against the community's own node. Their wallet keys stay on their device.

---

### 5.3.4 Cloudflare Dynamic DNS for Headscale

When the community node is deployed in the field (cellular hotspot, Starlink, etc.), the public IP changes. This script detects the current public IP, compares it to the Cloudflare DNS A record for `m2vpn.yourdomain.com`, and updates it automatically via the Cloudflare API. Runs every 5 minutes via systemd timer.

Without this, every IP change would require manual DNS updates before Headscale clients can reconnect.

#### Step 1 — Create the Update Script

**[SSH — Pi #2]**

```bash
sudo nano /usr/local/bin/ddns-update.sh
```

```bash
#!/bin/bash
# ddns-update.sh — Update Cloudflare DNS A record for m2vpn.yourdomain.com
# Runs via systemd timer every 5 minutes. Logs to journalctl -u ddns-update.
# Required for field deployment where public IP changes (cellular, Starlink, etc.)

CF_TOKEN="YOUR_CLOUDFLARE_API_TOKEN"
ZONE_ID="YOUR_ZONE_ID"
RECORD_ID="YOUR_RECORD_ID"
HOSTNAME="m2vpn.yourdomain.com"

# Get current public IP from multiple sources (fallback chain)
PUBLIC_IP=$(curl -s --max-time 10 https://ifconfig.me || curl -s --max-time 10 https://api.ipify.org || curl -s --max-time 10 https://icanhazip.com)

if [ -z "$PUBLIC_IP" ]; then
    echo "ERROR: Could not determine public IP"
    exit 1
fi

# Get current DNS record value from Cloudflare
DNS_IP=$(curl -s --max-time 10 -H "Authorization: Bearer $CF_TOKEN" "https://api.cloudflare.com/client/v4/zones/$ZONE_ID/dns_records/$RECORD_ID" | python3 -c "import sys,json; print(json.load(sys.stdin)['result']['content'])")

if [ "$PUBLIC_IP" = "$DNS_IP" ]; then
    echo "OK: IP unchanged ($PUBLIC_IP)"
    exit 0
fi

# Update the A record
RESULT=$(curl -s --max-time 10 -X PUT -H "Authorization: Bearer $CF_TOKEN" -H "Content-Type: application/json" -d "{\"type\":\"A\",\"name\":\"$HOSTNAME\",\"content\":\"$PUBLIC_IP\",\"ttl\":300,\"proxied\":false}" "https://api.cloudflare.com/client/v4/zones/$ZONE_ID/dns_records/$RECORD_ID")

SUCCESS=$(echo "$RESULT" | python3 -c "import sys,json; print(json.load(sys.stdin)['success'])")

if [ "$SUCCESS" = "True" ]; then
    echo "UPDATED: $DNS_IP -> $PUBLIC_IP"
else
    echo "ERROR: Update failed — $RESULT"
    exit 1
fi
```

> **Finding your Zone ID and Record ID:** Run these from Pi #2 with your Cloudflare API token:
> - Zone ID: `curl -s -H "Authorization: Bearer $TOKEN" "https://api.cloudflare.com/client/v4/zones?name=yourdomain.com" | python3 -m json.tool | grep '"id"' | head -1`
> - Record ID: `curl -s -H "Authorization: Bearer $TOKEN" "https://api.cloudflare.com/client/v4/zones/$ZONE_ID/dns_records?name=m2vpn.yourdomain.com" | python3 -m json.tool | grep -E '"id"|"type"|"content"'`

```bash
sudo chmod +x /usr/local/bin/ddns-update.sh
```

Test it manually:

```bash
sudo /usr/local/bin/ddns-update.sh
```

Expected: `OK: IP unchanged (your.current.ip)` or `UPDATED: old.ip -> new.ip`

#### Step 2 — Create Systemd Service and Timer

**[SSH — Pi #2]**

```bash
sudo nano /etc/systemd/system/ddns-update.service
```

```ini
# ddns-update.service — One-shot Cloudflare DNS update for m2vpn.yourdomain.com
# Triggered by ddns-update.timer every 5 minutes.
# Logs: journalctl -u ddns-update

[Unit]
Description=Cloudflare DDNS Update for Headscale
After=network-online.target
Wants=network-online.target

[Service]
Type=oneshot
ExecStart=/usr/local/bin/ddns-update.sh
```

```bash
sudo nano /etc/systemd/system/ddns-update.timer
```

```ini
# ddns-update.timer — Run DDNS check every 5 minutes
# Ensures m2vpn.yourdomain.com stays pointed at current public IP
# Critical for field deployment on cellular/Starlink where IP changes frequently

[Unit]
Description=DDNS Update Timer for Headscale

[Timer]
OnBootSec=1min
OnUnitActiveSec=5min
AccuracySec=30s

[Install]
WantedBy=timers.target
```

```bash
sudo systemctl daemon-reload
```

```bash
sudo systemctl enable ddns-update.timer
```

```bash
sudo systemctl start ddns-update.timer
```

Verify: `sudo systemctl list-timers ddns-update.timer` — should show NEXT fire time ~5 minutes out.

#### Monitoring

```bash
# Watch live updates
journalctl -u ddns-update -f

# Check recent history
journalctl -u ddns-update --since "1 hour ago"
```

---

### 5.4 Configure Reticulum

```bash
mkdir -p /opt/tactical-node/data/reticulum
nano /opt/tactical-node/data/reticulum/config
```

```ini
[reticulum]
  enable_transport = True
  share_instance = True
  shared_instance_port = 37428
  instance_control_port = 37429
  panic_on_interface_error = No

[interfaces]

  [[Default Interface]]
    type = AutoInterface
    enabled = yes

  [[TCP Server]]
    type = TCPServerInterface
    enabled = yes
    listen_ip = 0.0.0.0
    listen_port = 4242

  # Uncomment after LoRa radio is attached (Phase 6)
  #[[RNode LoRa]]
  #  type = RNodeInterface
  #  enabled = no
  #  port = /dev/ttyUSB0
  #  frequency = 915000000
  #  bandwidth = 125000
  #  spreadingfactor = 8
  #  codingrate = 5
  #  txpower = 17
```

---

### 5.5 Pull Docker Images

Pull images one at a time before starting the stack to avoid timeout failures on WiFi:

```bash
docker pull eclipse-mosquitto:2.0.22
docker pull ghcr.io/sethforprivacy/simple-monerod:v0.18.4.5
docker pull python:3.12.12-slim-bookworm
docker pull headscale/headscale:0.28.0
```

> **Note:** OpenTAK Server runs natively under systemd — no Docker pull needed. Install via the OTS Pi installer in Phase 5B.

---

### 5.6 Start Node #2 Stack

```bash
cd /opt/tactical-node

# Start core Docker services (OTS runs under systemd separately — see Phase 5B)
docker compose up -d monerod reticulum nomadnet mosquitto

# Monitor startup
docker compose logs -f monerod
# Monero will begin syncing from where the LMDB left off (should be current)
# Look for: "SYNCHRONIZED OK" in the logs

docker compose ps
```

> **Reticulum LoRa interface:** The RNode interface in `data/reticulum/config` is **commented out** at this stage — the LEFT Heltec V3 radio hasn't been configured yet. Reticulum will start and run over TCP/AutoInterface only. The LoRa interface is enabled in Phase 6 after the RNode firmware is flashed and confirmed. This is expected behavior.

**Verify Monero sync status:**
```bash
# Check sync status via RPC (localhost only after security fix)
curl -s http://127.0.0.1:18089/get_info | python3 -m json.tool | grep -E "height|status|synchronized"
# Required output:
#   "status": "OK"
#   "synchronized": true
#   "height": <current block height>

# Cross-check current block height at: xmrchain.net
# The height reported by your node should be within 1-2 blocks of the chain tip
# A gap of >100 blocks means your LMDB pre-sync was incomplete — let it catch up
```

> **Monero RPC is localhost-only** (security hardening applied above). The Quick Reference table shows port 18089 — that port is only accessible from the Pi itself or via Tailscale VPN. LAN WiFi clients cannot reach it directly. This is intentional.

**Verify OpenTAK Server:**
```bash
# OTS runs under systemd (installed in Phase 5B)
systemctl is-active opentakserver
# Should return: active

# Check OTS logs
journalctl -u opentakserver --no-pager -n 20

# ATAK Android connection:
# Server IP:   192.168.8.20
# TCP CoT:     port 8088
# SSL CoT:     port 8089 (encrypted — preferred)
# Cert enroll: port 8446

# Web UI: http://192.168.8.20:8080 — live Leaflet map with connected clients
# HTTPS UI: https://192.168.8.20:8443
```

---

### 5B. OpenTAK Server Native Install

OpenTAK Server runs natively under systemd — not Docker. The OTS Docker ARM64 image is alpha; the native Pi installer is production-ready.

**[SSH — Pi #2 tactical-lan]**

**Step 1 — Run the OTS installer:**
```bash
curl -fsSL https://opentakserver.io/install.sh | sudo bash
```

> The installer handles Python 3.10+, RabbitMQ, nginx, and all dependencies. The default admin account is `administrator` / `password` — you will change this in Step 10.

**Step 2 — Fix nginx port 443 conflict with Headscale:**

OTS installer may bind nginx to port 443. Headscale already uses 443 for the VPN control plane. Edit the OTS nginx config immediately after install:

```bash
sudo nano /etc/nginx/sites-available/ots_http
```

Remove or comment out any `listen 443` block in the OTS nginx config. OTS web UI should only listen on 8080 (HTTP) and 8443 (HTTPS). Save and restart nginx:

```bash
sudo nginx -t && sudo systemctl restart nginx
```

**Step 3 — Set RabbitMQ memory watermark:**

RabbitMQ defaults to 40% of system RAM. On a Pi with Monero's 4GB limit, constrain RabbitMQ to 256MB:

```bash
sudo rabbitmqctl set_vm_memory_high_watermark absolute 256MB
```

To make persistent across restarts:
```bash
echo 'vm_memory_high_watermark.absolute = 256MB' | sudo tee -a /etc/rabbitmq/rabbitmq.conf
```

> **RabbitMQ password bug (OTS v1.7.9):** The RabbitMQ credentials MUST remain `guest/guest`. OTS hardcodes the default RabbitMQ credentials in its internal SocketIO AMQP connection URL. Changing the RabbitMQ password will break OTS message queuing silently. Do not change RabbitMQ credentials until this is fixed upstream.

**Step 3a — Disable RabbitMQ HTTP auth backend plugin:**

The `rabbitmq_auth_backend_http` plugin causes `ACCESS_REFUSED` errors with the default guest credentials. Disable it:

```bash
sudo rabbitmq-plugins disable rabbitmq_auth_backend_http
```

```bash
sudo systemctl restart rabbitmq-server
```

**Step 3b — Add nginx no-cache header for kiosk map page:**

The OTS web map served at `/kiosk-map.html` can show stale data if the browser caches aggressively. Add a no-cache directive to the OTS nginx config:

```bash
sudo nano /etc/nginx/sites-available/ots_http
```

Inside the `server` block listening on port 8080, add:

```nginx
    # Prevent browser caching of kiosk map — always fetch fresh CoT data
    location = /kiosk-map.html {
        add_header Cache-Control "no-store, no-cache, must-revalidate, max-age=0";
        add_header Pragma "no-cache";
    }
```

```bash
sudo nginx -t && sudo systemctl restart nginx
```

**Step 4 — Add udev rules for stable USB symlinks:**

`/dev/ttyUSB0` and `/dev/ttyUSB1` can swap on reboot. Create stable symlinks:

```bash
sudo nano /etc/udev/rules.d/99-lora-radios.rules
```

```
# Heltec V3 LoRa radios — stable symlinks by USB controller path
# LEFT radio (RNode/Reticulum) — USB controller 0 (upper USB port)
SUBSYSTEM=="tty", ENV{ID_PATH}=="platform-xhci-hcd.0-usb-0:2:1.0", SYMLINK+="rnode"
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

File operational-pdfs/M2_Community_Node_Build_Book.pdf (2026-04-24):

M2 Community Node Build Guide v1.0 | Page 1

# M2 COMMUNITY NODE

# Build Guide

## v1.0 | April 2026

Build your own field-portable community communications node — ATAK · Matrix · Mesh · Monero

CC BY-NC-SA 4.0
capableenough.org

M2 Community Node — Build Guide | Page 2

# System Capabilities

Capability | Technology | Internet?
Tactical maps & positions | OpenTAK Server + ATAK | No
Encrypted group chat | Matrix (Conduit) + Element Web | No
Push-to-talk voice | Mumble + Mumla app | No
Off-grid mesh radio | Reticulum + Meshtastic (LoRa) | No
Anonymous access | Tor hidden services + I2P | No
Clearnet remote access | Cloudflare Tunnel | Yes
Remote VPN | Headscale (self-hosted WireGuard) | Yes
DNS filtering + Android bypass | AdGuard Home | No
Financial sovereignty | Monero pruned node | No

## Design Principles

- Privacy-first. Censorship-resistant. Open-source only.
- Field-deployable in under 15 minutes — wall power, vehicle 12V, or UPS.
- Commodity hardware only. No vendor lock-in. ~$994 recommended build.
- All core services run with zero internet — air-gap capable.
- Built on two Raspberry Pi 5 16GB boards. Easy to source, easy to replace.

# System Architecture

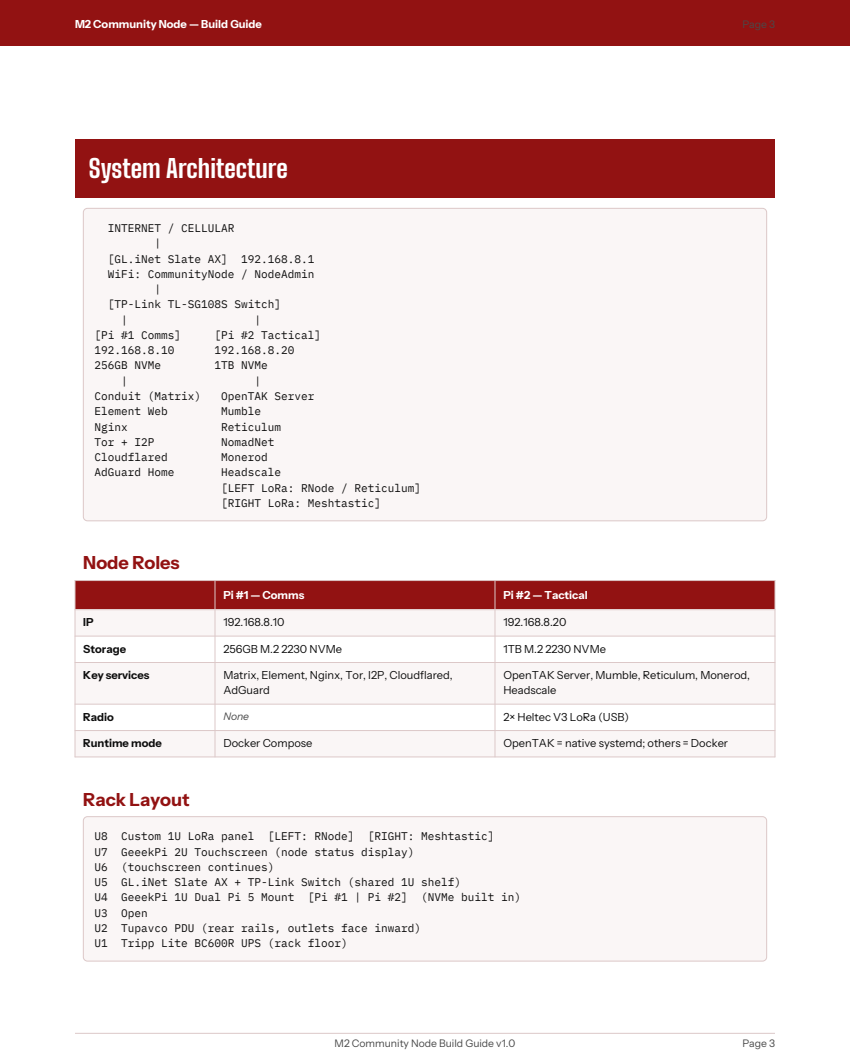
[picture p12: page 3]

[GL.iNet Slate AX] 192.168.8.1
WiFi: CommunityNode / NodeAdmin

[TP-Link TL-SG108S Switch]

[LEFT LoRa: RNode / Reticulum]
[RIGHT LoRa: Meshtastic]

Pi #1 — Comms | Pi #2 — Tactical

Storage | 256GB M.2 2230 NVMe | 1TB M.2 2230 NVMe

Key services | Matrix, Element, Nginx, Tor, I2P, Cloudflared, AdGuard | OpenTAK Server, Mumble, Reticulum, Monerod, Headscale

Radio | None | 2× Heltec V3 LoRa (USB)

Runtime mode | Docker Compose | OpenTAK = native systemd; others = Docker

U8 Custom 1U LoRa panel [LEFT: RNode] [RIGHT: Meshtastic]
U7 GeeekPi 2U Touchscreen (node status display)
U6 (touchscreen continues)
U5 GL.iNet Slate AX + TP-Link Switch (shared 1U shelf)
U4 GeeekPi 1U Dual Pi 5 Mount [Pi #1 | Pi #2] (NVMe built in)
U3 Open
U2 Tupavco PDU (rear rails, outlets face inward)
U1 Tripp Lite BC600R UPS (rack floor)

M2 Community Node — Build Guide | Page 4

# Bill of Materials

All prices are approximate (verified Feb–Apr 2026). Verify before ordering — Pi 5 and M.2 2230 prices fluctuate.

## Compute & Storage

Item | Qty | Est. Price | Where
Raspberry Pi 5 16GB | 2 | ~$160 ea | Amazon/PiShop.us
Pi 5 Official Active Cooler | 2 | ~$11 ea | PiShop.us
GeeekPi 1U Dual Pi5 Mount (B0F7XBVV4D) | 1 | ~$60 | Amazon
WD SN740 256GB M.2 2230 NVMe — Pi #1 | 1 | ~$40 | Amazon (B0C6MVP42M)
Crucial P310 1TB M.2 2230 NVMe — Pi #2 | 1 | ~$130 | Amazon/Newegg
SanDisk Extreme 32GB microSD ×2 | 2 | ~$12 ea | Amazon

## Rack & Networking

Item | Qty | Est. Price | Where
GeeekPi 8U 10” Mini Rack (RackMate T1) | 1 | ~$95 | Amazon
GeeekPi 2U Touchscreen Display | 1 | ~$70 | Amazon
GL.iNet Slate AX (AXT1800) | 1 | ~$120 | GL.iNet store
TP-Link TL-SG108S 8-Port Switch | 1 | ~$27 | Amazon/CompSource
1U Shelf (for switch + GL.iNet) | 1 | ~$18 | Amazon
Short Cat6 patch cables (6”–1’), 5-pack | 1 | ~$12 | Amazon

## Power

Item | Qty | Est. Price | Where
Anker 747 GaNPrime 150W Charger | 1 | ~$65 | Amazon (B09W2PNLX7)
Tupavco 10” 1U Rack PDU | 1 | ~$35 | Amazon
Tripp Lite BC600R UPS (600VA/300W) | 1 | ~$70 | DigiKey / Amazon
USB-C to USB-C cables 1’ 3-pack | 1 | ~$10 | Amazon
Micro HDMI to HDMI cables 2-pack | 1 | ~$10 | Amazon

M2 Community Node — Build Guide | Page 5

## Radio (LoRa)

Item | Qty | Est. Price | Where
Heltec WiFi LoRa 32 V3 915MHz | 2 | ~$20 ea | heltec.org / Rokland
U.FL–to–SMA pigtail 6” (IPEX) | 2 | ~$5 ea | Amazon
915 MHz LoRa antenna (SMA-F) | 2 | ~$8 ea | Amazon
Category | Est. Subtotal
Compute & Storage | ~$396
Rack & Networking | ~$342
Power | ~$190
Radio | ~$66
TOTAL | ~$994

M2 Community Node — Build Guide | Page 6

# Build Phases

Full step-by-step instructions are in M2_BUILD_GUIDE.md. This is the phase summary — what happens in what order and roughly how long it takes.

Phase | What Happens | Est. Time
0 — Pre-Build | Monero pre-sync on x86 PC. Software downloads. microSD prep. | 1–2 days
1 — Rack Assembly | Physical rack build. Cable management. Component mounting. | 1–2 hours
2 — Network Baseline | GL.iNet WiFi config. DHCP. Static IPs for both Pis. DNS overrides. | 30 min
3 — OS & Base Config | Raspberry Pi OS Lite on both Pis. Docker. SSH hardening. NVMe boot. | 1–2 hours
4 — Pi #1 Comms Stack | Conduit, Element Web, Nginx, i2pd, Tor, Cloudflared, AdGuard Home. | 1–2 hours
5 — Pi #2 Tactical Stack | OpenTAK Server (native), Monero rsync, Reticulum, Headscale, Mumble. | 1–2 hours
6 — LoRa Radio Setup | Flash LEFT Heltec with RNode firmware. Flash RIGHT Heltec with Meshtastic. | 30 min
7 — Integration Testing | ATAK connect. GeoChat. Position sharing. Matrix federation check. Mesh verify. | 30–60 min
8 — Field Hardening | Firewall rules. Backup. Credential rotation. Field card print. Kiosk setup. | 30 min

## Timeline Reality Check

- Monero sync is the long pole. Do it first, in parallel, on any spare x86 PC. The Pi 5 cannot sync Monero from scratch in a reasonable timeframe — always rsync from a pre-synced machine.
- Phases 1–8 take one focused day. With the Monero DB ready, the full rack build and software stack is a one-day project for someone comfortable with Linux and SSH.
- Phases 4–5 are the hardest. OpenTAK Server installs its own PostgreSQL and RabbitMQ — follow the official OTS install script exactly. Do not use Docker for OTS.

M2 Community Node — Build Guide | Page 7

# Software Stack

All open-source. All self-hosted. No SaaS, no subscriptions.

Service | Node | What It Does | Runtime
Conduit | Pi #1 | Matrix homeserver — encrypted group chat | Docker
Element Web | Pi #1 | Browser-based Matrix client | Docker
Nginx | Pi #1 | Reverse proxy — routes all Pi #1 traffic | Docker
Tor | Pi #1 | Hidden service (.onion) for Matrix + community page | Docker
i2pd | Pi #1 | I2P eepsite — community page on I2P | Docker
Cloudflared | Pi #1 | Clearnet tunnel — exposes Matrix/Element/OTS to internet | Docker
AdGuard Home | Pi #1 | DNS resolver + ad blocking — also bypasses Android Private DNS | Docker
OpenTAK Server | Pi #2 | TAK CoT relay server — ATAK connect, positions, GeoChat, web map | Systemd (native)
Mumble | Pi #2 | Push-to-talk voice (use Mumla on Android) | Docker
Reticulum + NomadNet | Pi #2 | Encrypted mesh transport + LoRa BBS | Python service
Monerod | Pi #2 | Pruned Monero node — community privacy coin endpoint | Docker
Headscale | Pi #2 | Self-hosted WireGuard VPN coordination — remote ATAK access | Docker
Mosquitto | Pi #2 | MQTT broker for IoT/sensor integration | Docker

## Operating System

Raspberry Pi OS Lite (64-bit, Bookworm) on both Pis. No desktop environment — headless SSH only. Docker Engine (not Docker Desktop) manages all containerized services.

M2 Community Node — Build Guide | Page 8

# Skills You’ll Need

Skill | Required For | Level
Linux command line (SSH) | Everything — all config is CLI-based | Comfortable
Docker Compose | Pi #1 full stack + most Pi #2 services | Basic
Networking basics | IP assignment, DNS, firewall rules | Basic
Systemd | OpenTAK Server management and troubleshooting | Basic
Git + file transfer (SCP) | Config deployment, script updates | Basic
ATAK app familiarity | Integration testing (Phase 7) | Helpful

## Key Gotchas — Read These Before You Start

- Monero MUST be pre-synced on an x86 machine. Syncing natively on ARM Pi takes weeks. Sync on a spare laptop or desktop, then rsync the blockchain directory to Pi #2.
- OpenTAK Server is NOT Docker. It installs its own PostgreSQL and RabbitMQ via the official install script. Do not try to containerize it — use the native systemd install.
- Both Heltec V3 LoRa boards are identical hardware. The only difference is firmware: LEFT panel position gets RNode (Reticulum), RIGHT gets Meshtastic. Label them before flashing.
- GL.iNet DNS overrides are required. Set static DNS entries on the GL.iNet router pointing matrix.capableenough.org and atakenroll.capableenough.org to the correct Pi IPs. Without this, Cloudflare-tunneled domains won't resolve on the local LAN.
- NVMe must be M.2 2230 form factor. Standard 2280 drives will not fit in the GeeekPi dual mount. Verify the 2230 suffix before ordering — prices are volatile (Steam Deck demand).
- Android phones block local DNS by default. The AdGuard Home container on Pi #1 handles DNS resolution for the LAN. GL.iNet DHCP serves Pi #1 (192.168.8.10) as the DNS server.
- ATAK needs 'Consistent' reporting. Stationary phones default to event-driven reporting and won't appear on the map. Tell all users: Settings → Reporting → Consistent.

## Full Documentation

Resource | Contents
M2_BUILD_GUIDE.md | Complete step-by-step build (all phases, all commands)
M2_Community_Node_Runbook.pdf | Field operations guide — power-on, onboarding, troubleshooting
M2_MiniRack_Hardware_BOM.md | Full BOM with ASINs, verified pricing, rack layout details
M2_ATAK_Connectivity_Guide.md | ATAK onboarding deep dive — all three connection paths
M2_MASTER_COMMUNITY_NODE_PLAN.md | Architecture, service inventory, design rationale
github.com/PapaSierra555/M2-Community-No de | All source files, scripts, and generators

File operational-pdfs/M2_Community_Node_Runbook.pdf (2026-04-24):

M2 Community Node Runbook v1.0 | Page 1

# M2 COMMUNITY NODE

# Field Operations Runbook

### v1.0 | April 2026

Field-deployable decentralized communications — ATAK · Matrix · Mesh · Monero

CC BY-NC-SA 4.0
capableenough.org

M2 Community Node — Field Operations Runbook

# Power-On Sequence

1. UPS (BC600R) — press power, confirm green LED.
2. GL.iNet router — power on, wait 60 seconds.
3. TP-Link switch — power on.
4. Pi #1 (comms, 192.168.8.10) — power on.
5. Pi #2 (tactical, 192.168.8.20) — power on.
6. Wait 90 seconds for services to start.
7. Kiosk touchscreen — power on last.

Total boot time: ~3 minutes. Do not test connectivity during this window.

## POST — Quick Check (30 seconds)

URL | Expected | Service
http://192.168.8.1 | GL.iNet admin panel | Router
http://192.168.8.10:8081 | Community info page | Kiosk web
http://192.168.8.10:8080 | Element Web login | Matrix chat
http://192.168.8.20:8080 | OTS web map | OpenTAK Server

If all four load: node is GO.

## Full POST (SSH)

ssh ps@192.168.8.10
docker ps --format "table {{.Names}}\t{{.Status}}" # All containers should show "Up"

ssh ps@192.168.8.20
systemctl is-active opentakserver cot_parser docker ps --format "table {{.Names}}\t{{.Status}}" # Expected: active (twice), then all containers Up

# Pre-Event Checklist

Complete 30 minutes before go-live.

| All POST checks pass (all four URLs load on test device).
| Update node GPS marker — OTS Web UI → map → right-click node location → set marker. Location may have changed from build to deployment.
| Node GPS marker visible and correct on OTS web map.

| Test phone connects to CommunityNode WiFi.
| Test phone ATAK connects and enrolls (192.168.8.20:8089 SSL).
| Test phone icon appears on OTS web map with correct callsign.
| GeoChat test: send a message, confirm it appears in OTS.
| Reporting Strategy set to Consistent on test phone.
| Mumla voice test: 192.168.8.20 port 64738 connects, voice audible.
| Element Web accessible at http://192.168.8.10:8080.
| Field cards printed and available (or QR codes on kiosk).
| WiFi password posted or available for incoming team members.
| Cloudflare Tunnel active — verify tak.capableenough.org loads from external device.
| Path B: Pre-add expected remote viewer emails to Cloudflare Access approved list.
| If SAR: ExCheck checklist template built and ready to distribute.

# Operator Onboarding — Three Paths

[!] OPERATOR / ADMIN REQUIREMENT: All administrative tasks in this section require a dedicated operations PC, laptop, or tablet — not a smartphone. The node admin must have their computer available and connected to CommunityNode WiFi (for OTS Web UI and SSH) or the internet (for Cloudflare dashboard and remote management). Ensure your admin machine is ready before onboarding begins.

+---------------------+
| | New team member | |
| | needs map access |
+----------+----------+
+-------------+-------------+ | Are they physically here? |
+-------------+-------------+ +--yes-+--no--+
+------+------+ +----+--------------------+
| PATH A | | | Do they need full ATAK |
| Local WiFi | | (CoT, GeoChat, PLI)? | |
| Full ATAK | +----+--------------------+
+-------------+ | +--no-+--yes--+
+------+------+ +----+-------------+
| PATH B | | | PATH C | |
| Clearnet | | | VPN + ATAK | |
| Browser | | | Operator only | |
+-------------+ +-----------------+

## Path Comparison

| Path A: Local WiFi | Path B: Clearnet Browser | Path C: VPN + ATAK
Location | At the node | Anywhere with internet | Anywhere with internet
App required | ATAK-CIV | Browser only | Tailscale + ATAK-CIV
Appears on map | Yes | No | Yes
GeoChat | Yes | No | Yes
Voice (Mumble) | Yes | No | Yes (with Mumla)
Onboard time | 2–5 min | Under 60 sec | 5–10 min
Operator effort | Hand them a QR code | Add email to approved list | Generate key, send instructions
Revoke access | They leave WiFi range | Remove email from list | Delete node from Headscale

# Path A — Local WiFi (Primary)

Who: Anyone physically at the node — SAR volunteers, community members, field teams.
What they get: Full ATAK — live position sharing, GeoChat, markers, missions, voice (Mumble), mesh relay (Meshtastic).

## Operator Walkthrough

1. Get the user on the WiFi. Tell them to connect to CommunityNode WiFi. Give them the password from the printed card or read it to them. They do NOT need the admin WiFi — CommunityNode has full access to the server.
2. Confirm ATAK is installed. ATAK-CIV (Android/Play Store) or iTAK (iPhone/App Store). If they don't have it, point them at the community page QR codes (http://192.168.8.10:8081) or hand them the field card.
3. Generate their enrollment QR code. Open OTS Web UI at http://192.168.8.20:8080. Log in with admin credentials. Navigate to Certificates (left sidebar) → Generate Data Package → enter callsign → Generate → click Show QR Code on the generated package.
4. User scans the QR code. In ATAK: Menu () → Import → QR Code. Scan the QR from your screen. ATAK auto-imports server connection, certificate, and truststore. Connects within seconds.
5. User sets callsign. Settings → My Preferences → Callsign. Use their name or an assigned tactical callsign.
6. Verify. Their icon appears on the shared map. Test GeoChat: have them send a message. If using Mumble: open Mumla, server 192.168.8.20, port 64738.

Fallback — Manual Server Entry
If the QR scan fails (old phone, camera issues):
ATAK → Settings → Network → TAK Servers → Add
Setting | Value
Server | 192.168.8.20
Port | 8089
Protocol | SSL

Setting | Value
Enable authentication | Yes
Enroll for client certificate | Yes
Use default SSL/TLS certs | No — uncheck this
Truststore password | atakatak

ATAK contacts the server on port 8446, downloads and installs the certificate automatically. OTS handles all PKI — it auto-generates a unique client certificate for each enrolling device.
Time to onboard: 2–5 min with QR code. 5–10 min manual.

# Path B — Clearnet Browser (Remote Viewers)

Who: Remote team members, partner agencies, anyone with internet who needs situational awareness but does NOT need to be a CoT participant on the map.
What they get: Full OTS web map in a browser — all team positions, markers, missions, live updates. View and monitor. No app install required.

Admin action required. Path B access is controlled by Cloudflare Zero Trust. Adding a user requires an admin with Cloudflare dashboard access and an internet connection. This cannot be done from the node itself. If possible, pre-add expected remote viewer emails before the event.

## Operator Walkthrough

1. Contact the node admin (or perform if you have Cloudflare access). The admin must log in to dash.cloudflare.com from any internet-connected computer.
2. Add the email to the approved list: Zero Trust → Access → Applications → OTS Web Map → Edit Policy → Include rule (Email) → add address → Save. Access is granted immediately.
3. Send them the link and login instructions:

Web map: https://tak.capableenough.org

To log in:
1. Open the link in any browser
2. Enter your email address
3. Check inbox for a 6-digit PIN
4. Enter the PIN -- you're in
(PIN expires in 10 minutes -- request a new one if needed)
4. Revoke access when needed. Zero Trust → Access → Applications → Edit Policy → remove their email → Save. Access is cut immediately.

Automating Path B (Optional)
Adding emails one at a time through the dashboard is slow on site. A helper script using the Cloudflare API can automate this. If your admin has set up cf-access.sh on the comms Pi, the entire grant/revoke cycle becomes a single SSH command:

# Grant access (run from admin laptop on NodeAdmin WiFi):

ssh ps@192.168.8.10 sudo /usr/local/bin/cf-access.sh add user@example.com

# Revoke access:

ssh ps@192.168.8.10 sudo /usr/local/bin/cf-access.sh remove user@example.com

Ask your node admin to set this up before CCC26. Script requires a Cloudflare API token stored on the comms Pi.

Time to onboard: Under 60 seconds (add email, send link).

Limitations
- They can see the map but do NOT appear as a position on it.
- No GeoChat, no marker creation, no mission participation from the browser.
- Requires internet access (the tunnel routes through Cloudflare).
- If you don't add their email, they can't get past the login screen.

# Path C — VPN + Full ATAK (Controlled Remote Access)

Who: Specific, trusted operators who need full ATAK participation from outside the node WiFi. This is NOT for general users. The operator personally sets this up for each individual.
What they get: Full ATAK over VPN — identical to being on local WiFi. Live position sharing, GeoChat, markers, missions, everything. They appear on the map as a full team member.

Remote user requirements: Tailscale (Play Store) + ATAK-CIV (Play Store).

## Operator Steps

Requires: Admin machine connected to CommunityNode WiFi or NodeAdmin WiFi. Run SSH commands from your admin laptop — not from the node itself.

1. Generate a VPN auth key (on tactical Pi):

ssh ps@192.168.8.20
sudo docker exec tactical-node-headscale-1 \
headscale preauthkeys create --user community --expiration 24h
# For standing team member (persistent):

sudo docker exec tactical-node-headscale-1 \
headscale preauthkeys create --user community --expiration 90d --reusable
2. Send the user these instructions:

1. Install Tailscale from the Play Store
2. Open Tailscale > tap profile icon > Accounts > three-dot menu > 'Use an alternate server'
3. Enter: https://m2vpn.capableenough.org
4. Paste the auth key I sent you
5. Tailscale connects -- you now have a VPN tunnel to the node
6. Open ATAK > Settings > Network > TAK Servers > Add
Server: 192.168.8.20 | Port: 8089 | Protocol: SSL
Check: Enroll for Client Certificate
Uncheck: Use default SSL/TLS Certificates Truststore password: atakatak
7. Set callsign: Settings > My Preferences > Callsign
8. You should appear on the shared map within seconds.
3. Verify their connection:

ssh ps@192.168.8.20
sudo docker exec tactical-node-headscale-1 headscale nodes list # Confirm their device has an assigned IP (100.64.x.x range)
4. Revoke access when done:

ssh ps@192.168.8.20
sudo docker exec tactical-node-headscale-1 headscale nodes delete --identifier <id> # User's Tailscale immediately disconnects. No residual access.

Security Notes
- Each auth key is tied to an expiration — it cannot be reused after it expires.
- You control exactly who has access and can revoke instantly.
- VPN traffic is encrypted end-to-end (WireGuard).
- The Headscale server only accepts connections with valid pre-auth keys.
- Subnet routes (192.168.8.0/24) are already approved on both Pis — remote users reach LAN services as if local.

# During the Event

## Monitoring

- Kiosk touchscreen shows live service status. Green = healthy.
- OTS web map at http://192.168.8.20:8080 shows all connected EUDs.

## Positions Stop Updating

The CoT parser service processes incoming position reports. If positions freeze, restart it:

ssh ps@192.168.8.20
systemctl status cot_parser
sudo systemctl restart cot_parser

## User Can't Connect to ATAK

- Wrong WiFi. Must be on CommunityNode, not NodeAdmin or a hotspot.
- SSL checkbox. In ATAK TAK Servers, must have 'Enroll for Client Certificate' checked and 'Use default SSL/TLS Certificates' unchecked.
- Old server entry. Delete the server entry in ATAK and re-add from scratch. Stale certificates cause repeated connection failures.
- Private DNS / VPN on phone. Disable any system-level VPN or Private DNS setting before connecting. These interfere with local resolution.
- Certificate enrollment already done. If the user previously enrolled, ATAK may have cached a bad cert. Delete the server and re-add.

## Element / Matrix Down

ssh ps@192.168.8.10
docker restart community-node-conduit-1 docker restart community-node-nginx-1

## User Not on Map

- In ATAK: Settings → Reporting → Reporting Strategy → set to Consistent.
- Or: toggle server off/on in TAK Servers to force a reconnect.
- Confirm GPS is active on their phone and location permission is granted to ATAK.
- Check OTS is showing their callsign in the Clients list (http://192.168.8.20:8080).

# Teardown

Shut down in reverse power-on order:
1. Notify all active ATAK users: 'Server going offline in 2 minutes.'
2. Export any mission data from OTS Web UI if needed (Missions → Export).
3. SSH to Pi #1: sudo shutdown -h now
4. SSH to Pi #2: sudo shutdown -h now
5. Wait 30 seconds for both Pis to power off (LEDs go dark).
6. Power off the GL.iNet router.
7. Power off the TP-Link switch.
8. Power off the Anker charger.
9. Power off the Tupavco PDU.
10. UPS last: hold power button until it beeps off.

Pack-Up Notes
- Disconnect LoRa antennas before coiling USB cables — the SMA connectors are fragile.
- USB-C cables for the Pis go in the accessory pouch, not loose in the rack.
- Monero blockchain state is on NVMe — no action needed; it persists across reboots.
- Tor hidden service keys are in /var/lib/tor/ — backed up with the full config backup.

## Emergency: Internet Lost

All local services continue. ATAK, voice, mesh, and Element all work with no internet. The Cloudflare Tunnel and Headscale VPN will drop — remote viewers lose access. Everyone on the local WiFi is unaffected.

To air-gap intentionally (stop all clearnet egress):

ssh ps@192.168.8.10
docker stop community-node-cloudflared-1

ssh ps@192.168.8.20
docker stop tactical-node-headscale-1

## Emergency: Pi Won't Boot

Diagnostic steps:
1. Confirm USB-C power cable is seated (Pis use USB-C PD — not all cables work).
2. Check Anker charger output LED — should be solid, not blinking.
3. Connect a monitor via micro-HDMI to see boot output.
4. If kernel panic / filesystem error: boot from microSD with rescue image.
5. If NVMe not found: check M.2 seating in the GeeekPi bracket.

What Still Works If a Pi Goes Down

Pi Down | Services Lost | Services Still Available
Pi #1 (comms) | Matrix/Element, Tor, I2P, Cloudflare Tunnel, AdGuard DNS | ATAK (Pi #2), Mumble, Meshtastic, Reticulum, Monerod, Headscale
Pi #2 (tactical) | ATAK/OTS, Mumble, Meshtastic, Reticulum, Monerod, Headscale | Matrix/Element, community kiosk, Tor hidden services, AdGuard DNS

# ATAK Configuration

## What's Built In — No Plugins Needed

- Position sharing (PLI) — live team positions on shared map
- GeoChat — group and private messaging within ATAK
- Markers and drawing tools
- Route planning
- CASEVAC reports (9-line)
- ExCheck checklists
- Track logging
- Offline maps (with pre-cached tiles served by OTS)
- Terrain analysis
- Geofencing

## Recommended Plugins (2 Only)

Plugin | Purpose | Install | Who Needs It
Meshtastic ATAK Plugin | Direct radio-to-phone bridge for LoRa mesh | GitHub APK sideload | Operators with their own Meshtastic radio only
VNS (Vehicle Navigation System) | In-ATAK turn-by-turn navigation | Google Play Store | Team leads running vehicle ops

## Data Packages Pre-Loaded

Package | Contents | Auto-push
DTED2 Florida | 30m elevation data | Via enrollment data package
PMTiles FL (578MB) | Offline vector maps z0–14 | Served at 192.168.8.20:8080
Community Node marker | M2 HQ position | Cron push every 4 hours

Offline map tiles are already cached — no internet needed for map display.

# Matrix / Element Chat

M2 Conduit server — standalone field node. Independent of clearnet Matrix.

## Access

Method | URL
On node WiFi | http://192.168.8.10:8080
Clearnet | https://element.capableenough.org
Matrix server name | m2.capableenough.org

## Room Structure

Community Space — standing rooms:

Room | Purpose
#comms | Radio, mesh, Reticulum, Meshtastic

#medical | First aid, trauma, community health

#agriculture | Food production, permaculture

#security | Physical security, situational awareness

#logistics | Supply chain, transportation

#general | Social, announcements

#onboarding | Encryption setup help, welcome resources

Dynamic rooms are spun up as needed (mission-specific, event, emergency).

## Encryption

- All rooms encrypted by default (E2EE enforced).
- Once encryption is on, it cannot be disabled (protocol enforced).
- New users: set up key backup before joining rooms to prevent message loss.

## Roles

Role | Power Level | Who
Admin | 100 | Operator + trusted family (1–2 people)
Moderator | 50 | Promoted community members
Member | 0 | Standard users

# Quick Reference — URLs & Ports

Service | LAN URL | Port | Notes
Router admin | http://192.168.8.1 | 80 | GL.iNet admin panel
Community page | http://192.168.8.10:8081 | 8081 | Operator onboarding kiosk
Element Web | http://192.168.8.10:8080 | 8080 | Also: element.capableenough.org
OTS web map (LAN) | http://192.168.8.20:8080 | 8080 | Admin login required
OTS web map (clearnet) | tak.capableenough.org | 443 | Cloudflare Access — OTP email login
ATAK server (SSL) | 192.168.8.20 | 8089 | After cert enrollment
ATAK enrollment | 192.168.8.20 | 8446 | Auto-used during first connect
Mumble voice | 192.168.8.20 | 64738 | No password required by default
AdGuard Home | http://192.168.8.10:3000 | 3000 | DNS admin — admin/admin default
Matrix federation | http://192.168.8.10:8448 | 8448 | Conduit federation port
Headscale admin | https://m2vpn.capableenough.org | 443 | Via Cloudflare Tunnel
Monerod RPC | http://192.168.8.20:18081 | 18081 | Local RPC only — not exposed to WAN

## WiFi Networks

SSID | Purpose | Access
CommunityNode | Field operator / EUD WiFi | Full node access (all services)
NodeAdmin | Tech admin only | Router admin access + all node services

## Default Credentials

Change all passwords before deployment. Sensitive values are in M2_SECRETS.md (gitignored — local only).

Service | Username | Password
ATAK enrollment | field | community
OTS admin | admin | [see M2_SECRETS.md]
GL.iNet admin | root | [see M2_SECRETS.md]
AdGuard Home | admin | [see M2_SECRETS.md]
Matrix admin | @admin:m2.capableenough.org | [see M2_SECRETS.md]
Mumble SuperUser | (blank) | [see M2_SECRETS.md]
ATAK truststore (cert) | (n/a) | atakatak

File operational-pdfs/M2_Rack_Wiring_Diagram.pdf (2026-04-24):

# M2 COMMUNITY NODE

# Rack Wiring & Cable Routing Diagram

## v1.0 | April 2026

### Power chain · Data routing · RF paths · EMI separation zones

CC BY-NC-SA 4.0
capableenough.org
M2 Community Node Wiring Diagram v1.0 | Page 1

# M2 COMMUNITY NODE — RACK WIRING DIAGRAM

## FRONT VIEW (Top-Down)

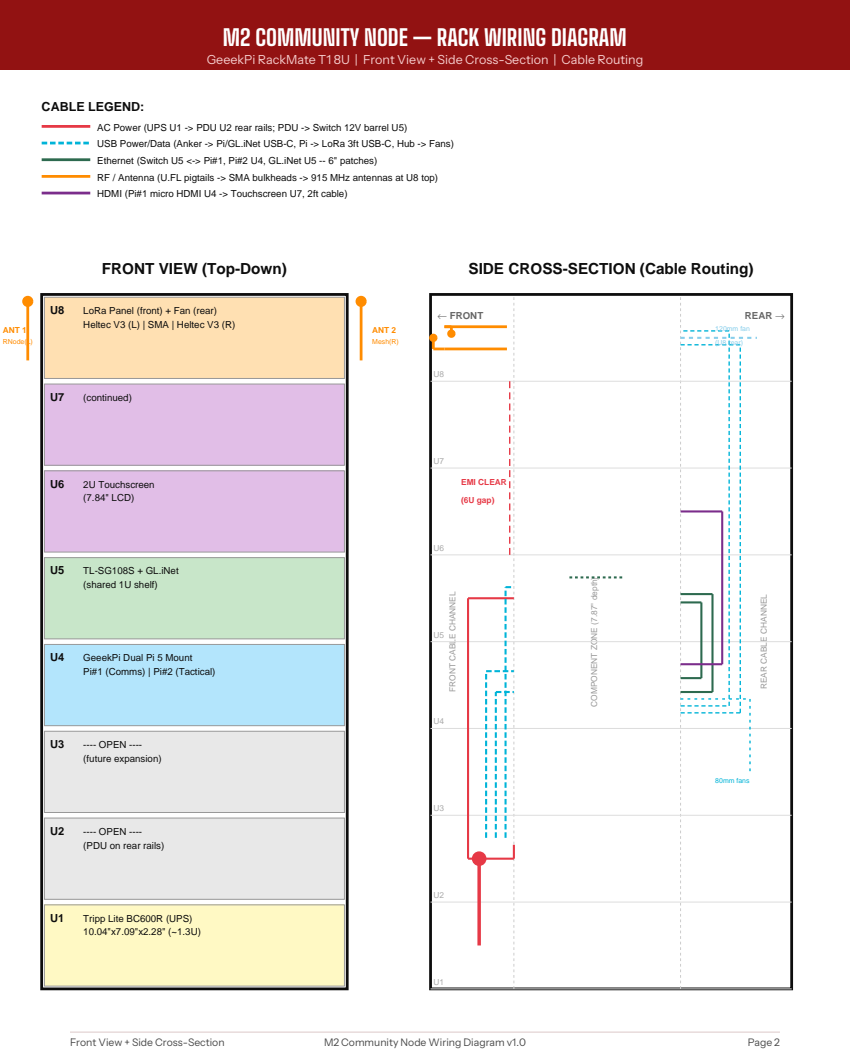
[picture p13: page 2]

GeeekPi RackMate T1 8U | Front View + Side Cross-Section | Cable Routing

AC Power (UPS U1 -> PDU U2 rear rails; PDU -> Switch 12V barrel U5)
USB Power/Data (Anker -> Pi/GL.iNet USB-C, Pi -> LoRa 3ft USB-C, Hub -> Fans)
Ethernet (Switch U5 <-> Pi#1, Pi#2 U4, GL.iNet U5 -- 6" patches)
RF / Antenna (U.FL pigtails -> SMA bulkheads -> 915 MHz antennas at U8 top)
HDMI (Pi#1 micro HDMI U4 -> Touchscreen U7, 2ft cable)

SIDE CROSS-SECTION (Cable Routing)

Heltec V3 (L) | SMA | Heltec V3 (R) ANT 1

Pi#1 (Comms) | Pi#2 (Tactical)

(PDU on rear rails)

# POWER CHAIN & EMI SEPARATION

Wall -> UPS (U1) -> PDU (U2 rear) -> Devices | Cable Routing Rules | RF Protection Zones

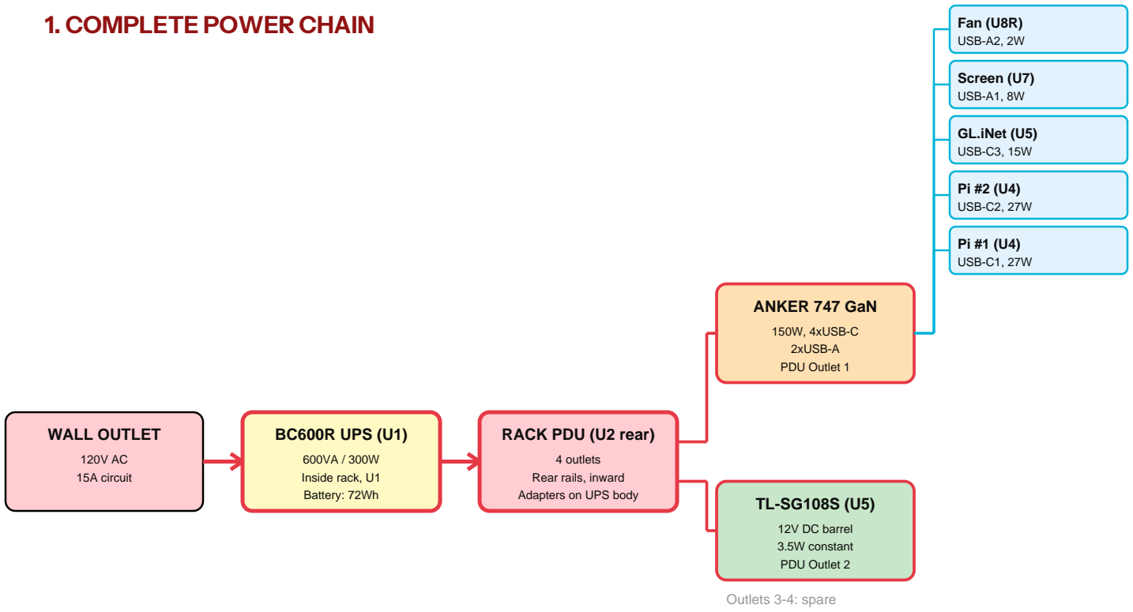
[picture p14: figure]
1. COMPLETE POWER CHAIN; WALL OUTLET; 120V AC 15A circuit; BC600R UPS (U1); 600VA / 300W Inside rack, U1 Battery: 72Wh; RACK PDU (U2 rear); 4 outlets Rear rails, inward Adapters on UPS body; ANKER 747 GaN; 150W, 4xUSB-C 2xUSB-A PDU Outlet 1; Pi #1 (U4) USB-C1, 27W; Pi #2 (U4) USB-C2, 27W; GL.iNet (U5) USB-C3, 15W; Screen (U7) USB-A1, 8W; Fan (U8R) USB-A2, 2W; 12V DC barrel 3.5W constant PDU Outlet 2; Outlets 3-4: spare

## 2. EMI SEPARATION ANALYSIS

V GOOD: LoRa at U8 (top), PDU at U2 rear -- 6U (10.5") vertical separation
V GOOD: LoRa at U8 (top), UPS at U1 -- 7U (12.25") maximum separation
V GOOD: Power cables concentrated at U1-U2 bottom; RF at U8 top -- opposite ends V GOOD: AC power cable is shielded (PDU 6ft cord has integral ground)
V GOOD: U.FL pigtails are < 6" long -- minimal exposure to radiated EMI
V GOOD: 915 MHz LoRa is spread-spectrum (chirp) with ~19 dB noise immunity
V GOOD: USB data cables (Pi U4 -> LoRa U8, 3ft) route via LEFT rail -- away from power
! CAUTION: 3ft USB-C data cables traverse 4U on left rail
> MITIGATION: Route USB data cables tightly along left rail; cross power paths at 90 deg only

## 3. CABLE ROUTING RULES

LEFT RAIL (rear): Ethernet patches (6"), HDMI (2ft, Pi U4 -> Screen U7), fan USB cables
LEFT CHANNEL: | USB-C data cables (Pi#2 U4 -> LoRa boards at U8, 3ft)
RIGHT CHANNEL: | USB-C power cables (Anker -> Pi#1 U4, Pi#2 U4, GL.iNet U5, Screen U7)
RIGHT RAIL (rear): AC power (PDU 6ft cord U1->U2 rear rails, ultra-short), 12V barrel adapter cable FRONT PANEL (U8): RF only -- SMA bulkheads + antennas, OLED windows (TOP of rack)
RULE: Never bundle AC power and RF cables together. Cross at 90 deg only.
Power Chain & EMI Separation | M2 Community Node Wiring Diagram v1.0 | Page 3

# TOP-DOWN VIEW — CABLE SEPARATION ZONES

Looking down into the rack from U8 | Data LEFT, Power RIGHT, RF FRONT (U8 top)

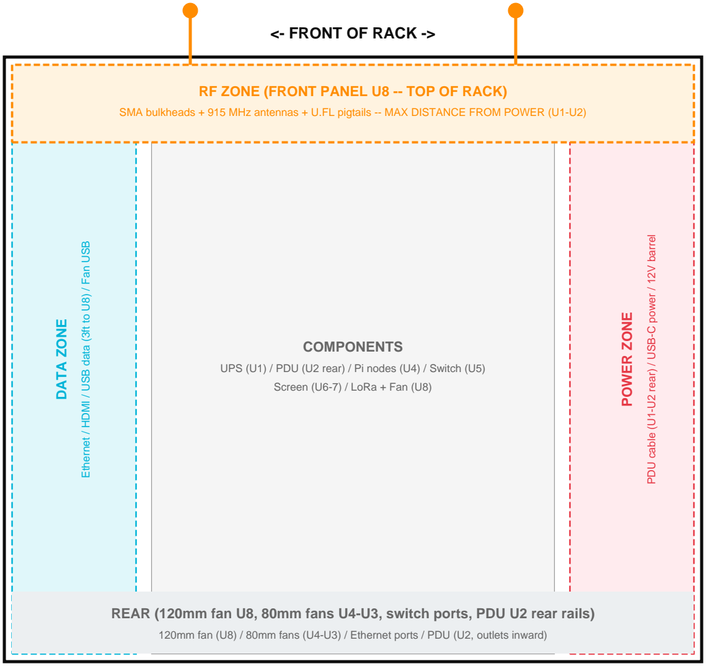
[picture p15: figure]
<- FRONT OF RACK ->; DATA ZONE; COMPONENTS; Screen (U6-7) / LoRa + Fan (U8); POWER ZONE; RF ZONE (FRONT PANEL U8 -- TOP OF RACK)

### <- REAR OF RACK ->

### LEFT RAIL

### RIGHT RAIL

Ethernet / HDMI / USB data (3ft to U8) / Fan USB

UPS (U1) / PDU (U2 rear) / Pi nodes (U4) / Switch (U5)

PDU cable (U1-U2 rear) / USB-C power / 12V barrel

SMA bulkheads + 915 MHz antennas + U.FL pigtails -- MAX DISTANCE FROM POWER (U1-U2)

ANT 1 — LEFT (RNode) | ANT 2 — RIGHT (Mesh)

REAR (120mm fan U8, 80mm fans U4-U3, switch ports, PDU U2 rear rails)

120mm fan (U8) / 80mm fans (U4-U3) / Ethernet ports / PDU (U2, outlets inward)

### KEY ROUTING PRINCIPLE:

Data cables (Ethernet, HDMI, USB data) run on the LEFT rail/channel only.
Power cables (AC + USB-C power) run on the RIGHT rail/channel only.
RF paths (U.FL pigtails, SMA bulkheads, antennas) stay at the FRONT panel, U8 (TOP of rack). Power at U1-U2, RF at U8 = 6U (10.5") separation. Excellent EMI isolation.
Top-Down View — Cable Separation | M2 Community Node Wiring Diagram v1.0 | Page 4

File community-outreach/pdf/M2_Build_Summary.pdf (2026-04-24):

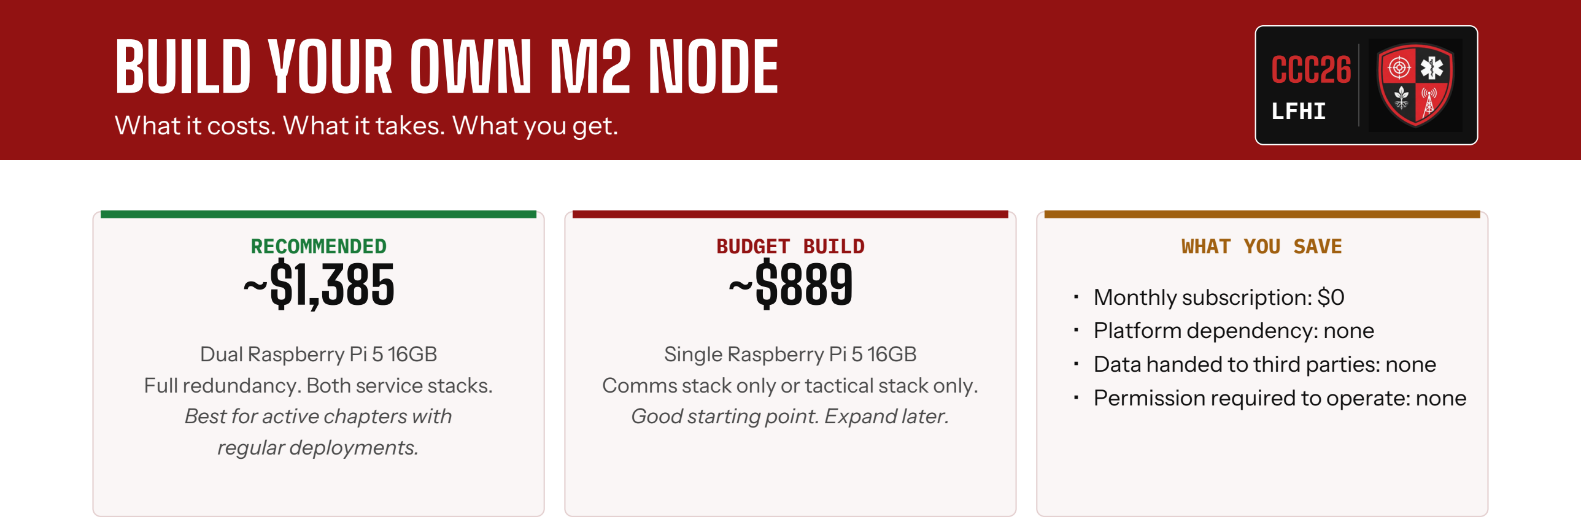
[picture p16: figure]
BUILD YOUR OWN M2 NODE; CCC26; LFHI; RECOMMENDED ~$1,385; Dual Raspberry Pi 5 16GB Full redundancy. Both service stacks. Best for active chapters with regular deployments.; BUDGET BUILD ~$889; Single Raspberry Pi 5 16GB; Good starting point. Expand later.; WHAT YOU SAVE; • Monthly subscription: $0 • Platform dependency: none • Data handed to third parties: none • Permission required to operate: none

What it costs. What it takes. What you get.

Comms stack only or tactical stack only.

## BILL OF MATERIALS — RECOMMENDED BUILD

Component | Qty | Approx. Cost | Purpose
Raspberry Pi 5 16GB | 2 | $160 ea | Compute nodes (comms + tactical)
Pi 5 active cooler | 2 | $10 ea | Thermal management
Samsung 256GB microSD | 2 | $28 ea | OS + boot media
Samsung 2TB NVMe SSD | 1 | $120 | Monero blockchain + data persistence
NVMe HAT for Pi 5 | 1 | $25 | NVMe interface
8U 10" mini rack | 1 | $85 | Enclosure
1U 10" rack shelf | 2 | $18 ea | Pi mounting
GL.iNet Slate AX router | 1 | $80 | WiFi gateway + LAN
TP-Link 8-port switch | 1 | $18 | Managed LAN
Heltec LoRa V3 | 2 | $25 ea | LoRa radios (Reticulum + Meshtastic)
Tripp Lite BC600R UPS | 1 | $55 | Power continuity
Anker 747 GaN 150W | 1 | $50 | Multi-port charging
Tupavco 8-outlet PDU | 1 | $30 | Rack power distribution
7" touchscreen | 1 | $75 | Kiosk display
Cables, hardware, misc | — | ~$50 | USB, Ethernet, SMA, etc.
TOTAL | | ~$1,385

## HOW LONG DOES IT TAKE?

Weekend 1 Hardware assembly, OS installation, basic
networking

Weekend 2 Docker services, Matrix, ATAK, LoRa configuration Weekend 3 Hardening, field test, documentation, field card printing

Future events < 1 hour deploy time once built and tested

## WHAT SKILLS DO YOU NEED?

### ✓ Linux command line (SSH, apt, systemctl) ✓ Basic networking (IP addresses, ports, DNS) ✓ Patience and a build guide

The rest is documented.
13 phases. Every command included.

Start building.

### Full build guide, BOM with Amazon links, and all config files:

### github.com/PapaSierra555/M2-Community-Node

Scan QR → open project, clone repo, or read docs online. | Scan to open
License: CC BY-NC-SA 4.0 — Build one for your community. Cannot be sold. | Capable Enough Project

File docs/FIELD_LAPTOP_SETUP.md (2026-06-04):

# Field Laptop Setup — Getac S400 G2

Primary IT/NetSec support laptop and M2 Community Node admin terminal.

**Hardware:** Getac S400 G2 (semi-rugged, MIL-STD-810G)
**OS:** Ubuntu 24.04.2 LTS
**Reserved IP:** 192.168.8.50 (NodeAdmin WiFi)
**Hostname:** `m2-field`

---

## Phase 1 — Ubuntu Install

### 1.1 Boot from USB
- Power on → press **F12** at Getac logo → select USB drive
- Select **Try or Install Ubuntu**

### 1.2 Pre-install hardware check (live desktop)
Run these before committing to install:
```bash
lspci | grep -i net
lspci | grep -i wifi
ip link show
lspci | grep -i vga
```
If WiFi shows up and connects → proceed. If not, document chipset and resolve first.

### 1.3 Install
- Double-click **Install Ubuntu**
- Installation type: **Minimal** (no LibreOffice, no extras)
- Disk: **Erase and install** (field-only machine)
- Enable **LVM + encryption** (LUKS) — adds boot passphrase, appropriate for field hardware
- Username: `ps`
- Hostname: `m2-field`
- Enable auto-login: No

### 1.4 First boot
```bash
sudo apt update && sudo apt upgrade -y
sudo reboot
```

---

## Phase 2 — Network Setup

### 2.1 Connect to M2 node WiFi
- SSID: `NodeAdmin` (5GHz)
- Password: see `M2_SECRETS.md`
- This is the admin network — both Pis are reachable from here

### 2.2 Reserve static IP on GL.iNet router
1. Open browser → `http://192.168.8.1` → log in
2. Network > LAN > DHCP > Static IP Binding
3. Add binding:
   - MAC address: run `ip link show` on field laptop, copy the MAC for the WiFi interface
   - IP: `192.168.8.50`
   - Hostname: `m2-field`
4. Save → reconnect WiFi to pick up the reservation

### 2.3 Verify IP
```bash
ip addr show
```
Should show `192.168.8.50` on the WiFi interface.

### 2.4 Test node reachability
```bash
ping -c 3 192.168.8.10
ping -c 3 192.168.8.20
ping -c 3 192.168.8.1
```
All three should respond.

---

## Phase 3 — SSH Access to Both Pis

### 3.1 Generate SSH key
```bash
ssh-keygen -t ed25519 -C "m2-field"
```
Accept default path (`~/.ssh/id_ed25519`). Set a passphrase.

### 3.2 Copy key to both Pis
```bash
ssh-copy-id pi@192.168.8.10
ssh-copy-id pi@192.168.8.20
```
Passwords: see `M2_SECRETS.md` (Pi Access section).

### 3.3 SSH config shortcuts
Create `~/.ssh/config`:
```
Host pi1
    HostName 192.168.8.10
    User ps
    IdentityFile ~/.ssh/id_ed25519

Host pi2
    HostName 192.168.8.20
    User ps
    IdentityFile ~/.ssh/id_ed25519
```

### 3.4 Test
```bash
ssh pi1 "hostname && uptime"
ssh pi2 "hostname && uptime"
```

---

## Phase 4 — Tools Install

```bash
sudo apt install -y nmap netcat-openbsd curl git python3 python3-pip wireshark tcpdump
```

```bash
sudo apt install -y net-tools traceroute dnsutils htop tree jq
```

Add user to wireshark group (capture without sudo):
```bash
sudo usermod -aG wireshark ps
```
Log out and back in for group to take effect.

---

## Phase 5 — Repo Clone

```bash
git clone https://github.com/YOUR_GITHUB_USERNAME/M2-Community-Node.git ~/M2-Community-Node
```

Keep this current before every deployment:
```bash
cd ~/M2-Community-Node && git pull
```

---

## Phase 6 — Offline Docs Folder

```bash
mkdir -p ~/Field
cp ~/M2-Community-Node/*.pdf ~/Field/
```

Field PDFs:
| File | Purpose |
|---|---|
| `M2_Community_Node_One_Sheet.pdf` | Event flyer |
| `M2_Community_Node_Build_Book.pdf` | Build handout |
| `M2_Community_Node_Runbook.pdf` | Field ops guide |
| `M2_Rack_Wiring_Diagram.pdf` | Cable reference |
| `M2_ATAK_FieldCard.pdf` | Enrollment card |

Pin `~/Field` to the Files sidebar for fast access.

---

## Phase 7 — Browser Setup (Firefox)

Install bookmarks for all node services. All URLs on NodeAdmin WiFi unless noted.

**Bookmark folder: M2 Node**

| Name | URL |
|---|-----|
| Element (local) | `http://192.168.8.10:8080` |
| Element (clearnet) | `https://communitynode.yourdomain.com` |
| OTS Web Map | `http://192.168.8.20:8080` |
| OTS Web Map (HTTPS) | `https://192.168.8.20:8443` |
| AdGuard Home | `http://192.168.8.1:3000` |
| GL.iNet Router | `http://192.168.8.1` |
| Headscale (M2) | `https://m2vpn.yourdomain.com` |
| Pi #1 — comms | `http://192.168.8.10` |
| Pi #2 — tactical | `http://192.168.8.20` |
| Matrix Federation Test | `https://federationtester.matrix.org` |

Set Firefox homepage to `http://192.168.8.1` (router — first thing to check if network is broken).

---

## Phase 8 — Connectivity Test Checklist

Run this full check before every event:

```bash
# Node reachability
ping -c 2 192.168.8.1
ping -c 2 192.168.8.10
ping -c 2 192.168.8.20

# SSH to both Pis
ssh pi1 "sudo systemctl is-active docker"
ssh pi2 "sudo systemctl is-active opentakserver"

# Service ports
nc -zv 192.168.8.10 8080
nc -zv 192.168.8.20 8080
nc -zv 192.168.8.20 8088
nc -zv 192.168.8.20 8089
nc -zv 192.168.8.20 8446
```

---

## Phase 9 — Lid Label

Print and affix to inside of lid:

```
M2 Community Node — Admin Terminal
NodeAdmin WiFi: [password from secrets]
Pi #1 (comms):    192.168.8.10   ssh pi@192.168.8.10
Pi #2 (tactical): 192.168.8.20   ssh pi@192.168.8.20
Router:           192.168.8.1
This laptop:      192.168.8.50
```

---

## Phase 10 — Pre-Event Checklist

- [ ] `git pull` in `~/M2-Community-Node`
- [ ] `cp ~/M2-Community-Node/*.pdf ~/Field/`
- [ ] SSH connectivity to both Pis confirmed
- [ ] All browser bookmarks loading
- [ ] Wireshark launches without sudo
- [ ] Laptop fully charged

---

## Phase 11 — Core Apps

Install these after first boot:

```bash
sudo apt install -y remmina remmina-plugin-rdp remmina-plugin-vnc
sudo apt install -y smbclient cifs-utils
sudo apt install -y keepassxc
sudo apt install -y code
```

Via browser/installer:
- **Brave** — primary browser, sync bookmarks + passwords via Brave Sync
- **Obsidian** — knowledge base, cross-device sync via Obsidian Sync or Proton Drive
- **ProtonVPN** — download `.deb` from protonvpn.com, install for secure remote sessions

---

## Phase 12 — Security Hardening

### 12.1 Firewall
```bash
sudo ufw default deny incoming
sudo ufw default allow outgoing
sudo ufw allow ssh
sudo ufw enable
sudo ufw status
```

### 12.2 Automatic security updates
```bash
sudo apt install unattended-upgrades -y
sudo dpkg-reconfigure --priority=low unattended-upgrades
```
Select Yes when prompted.

### 12.3 SSH hardening (disable password auth, root login)
Edit `/etc/ssh/sshd_config`:
```bash
sudo nano /etc/ssh/sshd_config
```
Set:
```
PermitRootLogin no
PasswordAuthentication no
PubkeyAuthentication yes
```
```bash
sudo systemctl restart ssh
```

### 12.4 Screen lock
```bash
sudo apt install gnome-screensaver -y
```
Settings > Privacy > Screen Lock: lock after 5 minutes, require password immediately.

### 12.5 fail2ban
```bash
sudo apt install fail2ban -y
sudo systemctl enable --now fail2ban
```

### 12.6 Verify AppArmor is active
```bash
sudo aa-status
```
Should show profiles loaded and enforced. AppArmor is on by default in Ubuntu 24.04.

### 12.7 Verify disk encryption
```bash
lsblk -f | grep crypto
```
Should show `crypto_LUKS` on the main drive if encryption was enabled during install.

---

## Phase 13 — RF / Security Tools (Installed 2026-06-03)
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

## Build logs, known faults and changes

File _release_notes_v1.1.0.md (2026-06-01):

## Meshtastic 8-Node Field Pack

M2 Community Node now ships with a complete Meshtastic field deployment kit: 8 × Heltec T114 field nodes in a Pelican case, pre-configured and ready to loan to event attendees. The two rack-mounted Heltec V3 ROUTER nodes bridge all traffic to the MQTT/Matrix stack as before — the T114 fleet extends that coverage to everyone at the event.





---

### What's new

**Hardware — MF-1 through MF-8**
- 8 × Heltec T114 LoRa nodes — 915 MHz, built-in GPS, E-ink display, Li-Po battery
- Pelican case with foam cutouts — all 8 nodes, color-coded lanyards, USB-C data cables
- Dedicated USB charging hub for bulk pre-event prep

**Scripts** (`meshtastic/scripts/`)

| Script | Purpose |
|---|---|
| `config_heltec_v3.py` | Push PSK + config to the 2 rack ROUTER nodes |
| `gen_m2_channel_qr.py` | Generate day-of channel QR card (rotate PSK first) |
| `generate_m2_mesh_handoff.py` | Rebuild operator reference PDF |
| `generate_m2_mesh_runbook.py` | Rebuild non-technical operator runbook |
| `generate_m2_mesh_cheatsheet.py` | Rebuild 1-page pre/day-of/post cheatsheet |
| `generate_m2_mesh_connection_card.py` | Rebuild T114 device checkout cards (8 nodes, 4 pages) |

**Print-ready PDFs** (`meshtastic/pdf/`)

| File | Purpose |
|---|---|
| `M2_Mesh_Handoff.pdf` | Operator reference — hardware inventory, scripts, troubleshooting |
| `M2_Mesh_Runbook.pdf` | Non-technical guide — T114 UF2 flash, configure, replace |
| `M2_Mesh_Cheatsheet.pdf` | 1-page quick reference for event day |
| `M2_Mesh_DeviceCard_Front.pdf` | T114 checkout cards — front (8 nodes, 4 pages) |
| `M2_Mesh_DeviceCard_Back.pdf` | T114 checkout cards — back (8 nodes, 4 pages) |

> `M2_Mesh_ChannelQR_DayOf.pdf` is gitignored — it encodes the live PSK. Regenerate after each rotation with `gen_m2_channel_qr.py` and print fresh for every event.

---

### Architecture

Two node classes, one mesh:

- **ROUTER (rack):** 2 × Heltec V3 — rack-mounted in M2 8U, USB serial to Pi 2, MQTT bridge to Matrix and ATAK. Always on.
- **CLIENT (field):** 8 × Heltec T114 — loan devices in Pelican case. Attendees pair over Bluetooth, scan QR to join CommunityNode channel. No cell service or internet required.

---

### Pre-event workflow

```
1. Generate new PSK and save
2. Update CHANNEL_PSK_B64 in config_heltec_v3.py AND gen_m2_channel_qr.py
3. python meshtastic/scripts/config_heltec_v3.py    # rack nodes
4. python meshtastic/scripts/gen_m2_channel_qr.py   # print fresh QR card
5. Distribute T114 field nodes from Pelican case at check-in
```

---

### Notes

- `config_m2_t114.py` (T114 field node config script) is referenced in documentation but not yet committed — add before first event deployment
- All PDFs are font-embedded and print-ready (verified with PyMuPDF)
- PSK rotation is mandatory before every event — see `M2_Mesh_Handoff.pdf` Section 5

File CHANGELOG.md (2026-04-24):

# Changelog

All notable changes to this project will be documented here.
Format follows [Keep a Changelog](https://keepachangelog.com/en/1.0.0/).
Versioning follows [Semantic Versioning](https://semver.org/).

---

## [1.0.1] — 2026-04-24

### Added
- `docs/BUILD_OPTIONS.md` — hardware alternatives guide covering Pi 4, Pi 5 8GB, x86_64 mini PCs,
  single-device builds, no-Monero variants, and service dependency map
- Cross-references to BUILD_OPTIONS.md in README, HARDWARE_BOM.md, PREREQUISITES.md, docs/README.md

---

## [1.0.0] — 2026-04-24

First public release. Full release notes: [RELEASE_NOTES.md](RELEASE_NOTES.md)

### Added
- Dual Raspberry Pi 5 build guide (13 phases, every command and config)
- Hardware BOM with part numbers and pricing (~$994 recommended, ~$889 budget)
- Service stack: Matrix/Conduit, Element Web, OpenTAKServer, Headscale, Mumble,
  Meshtastic bridge, Reticulum, Monero full node, Tor, I2P, AdGuard DNS
- Kiosk display — offline maps (PMTiles + DTED2), service health dashboard
- 17 reference docs: build guide, event runbook, ATAK connectivity, disaster recovery,
  troubleshooting, maintenance, network customization, and more
- Print-ready PDFs: build book, runbook, wiring diagram, ATAK field card, outreach materials
- ReportLab PDF generators with bundled OFL fonts
- Matrix status bot (12h digest), ATAK data package builder, QR code generators
- instance.conf template — single file controls all instance-specific values
- Network diagram (docs/M2_Network_Diagram.drawio)
- CC BY-NC-SA 4.0 license

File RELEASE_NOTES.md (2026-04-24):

# M2 Community Node — Release Notes

## v1.0.0

**First public release.**

M2 Community Node

This is a complete, field-tested build plan for a self-contained community communications node — dual Raspberry Pi 5 in an 8U 10" mini-rack. Everything required to replicate it from scratch is in this repository.

---

### Before You Start — Read This

**This is a build plan, not a plug-and-play installer.** It is a step-by-step blueprint for constructing and configuring a multi-service communications node from commodity hardware. Prior hardware or networking expertise is not a hard requirement — but only with realistic expectations and the right support.

**This node was built with the help of an AI companion assisting at every step** — walking through commands, catching config errors, explaining tradeoffs, and adapting to the specific hardware and environment as problems came up. That approach is strongly recommended for anyone attempting this build.

The build guide has every command and every config, but this is a complex, multi-service system. Standing it up involves:

- Configuration decisions that depend on your domain, hardware, and use case
- Gotchas in third-party software (OpenTAKServer, Conduit, Headscale) that are not documented upstream
- Network and firewall behaviors that vary by router model and ISP
- Security choices around access tiers, certificates, and credentials that require deliberate decisions
- Unexpected states during setup that require diagnosis, not just copy-paste

**The recommendation:** Work through the build guide with an AI assistant — Claude, ChatGPT, or similar — that can read the docs alongside you, adapt commands to your environment on the fly, and help you reason through the decisions. This is not a project where you follow a guide blindly. It is a project where you follow the guide with a knowledgeable collaborator and build something that actually fits your community.

---

### What's Included

**Services (Comms Pi — Pi #1)**
- Matrix / Conduit homeserver
- Element Web client
- Nginx reverse proxy with Cloudflare Tunnel for clearnet access
- Tor hidden services (Element, Matrix API, community page)
- I2P node
- AdGuard DNS with LAN split-DNS

**Services (Tactical Pi — Pi #2)**
- OpenTAKServer — ATAK/TAK shared situational awareness
- Headscale — self-hosted VPN (WireGuard)
- Mumble voice server
- Meshtastic LoRa mesh bridge (via Mosquitto MQTT)
- Reticulum / RNode encrypted mesh transport
- Monero full node (restricted RPC, community privacy node)

**Kiosk Display**
- Touch-screen status dashboard (service health, system vitals, QR codes)
- Offline map viewer (PMTiles street-level + DTED2 terrain)

**Documentation**
- 17 reference documents covering every phase of the build
- Full hardware BOM with part numbers and pricing
- Event operations runbook
- Troubleshooting guide (symptom-based, field-usable)
- ATAK connectivity guide (3 access tiers: LAN, clearnet, VPN)
- Disaster recovery procedures

**Print-ready PDFs**
- Build book, event runbook, wiring diagram, ATAK field card, troubleshooting reference
- Community outreach materials (booth handouts, recruiting cards)

**Tooling**
- ReportLab PDF generators (OFL fonts bundled — works on any machine)
- Status bot (Matrix posts every 12h)
- ATAK data package builder
- QR code generators for WiFi, app stores, onion services
- Vinyl label generators for rack panels
- instance.conf template — one file controls all instance-specific values

---

### Hardware

**Recommended build (~$994)**
- 2× Raspberry Pi 5 16GB
- 8U 10" mini-rack (wall-mount capable)
- 2× NVMe HAT + 1TB NVMe SSD each
- GL.iNet Beryl AX (Wi-Fi 6 router)
- 2× Heltec V3 LoRa radios
- 10" touch monitor
- UPS module + LiPo battery

**Budget build (~$889)** — single Pi variant covered in docs.

Full BOM with ASINs and current pricing: [docs/HARDWARE_BOM.md](docs/HARDWARE_BOM.md)

---

### Configuration

All instance-specific values (IP addresses, domain names, WiFi credentials, event details) live in `instance.conf` — gitignored, never committed. A fully commented template is provided at `instance.conf.template`.

Secrets (tokens, passwords, API keys) live in `M2_SECRETS.md` — also gitignored. Template at `M2_SECRETS.template.md`.

No credentials or personal data are present in this repository.

---

### Known Limitations / Gotchas

- **Tor .onion addresses** are generated on first startup and are unique to each node. The addresses in docs and templates are placeholders — yours will be different. Commands to retrieve them are in [docs/SERVICE_MAP.md](docs/SERVICE_MAP.md).
- **OpenTAKServer** password reset follows a non-standard procedure (HMAC+argon2). The correct steps are documented in [docs/TROUBLESHOOTING.md](docs/TROUBLESHOOTING.md).
- **Conduit Matrix** works best on room version 10 — there is a known auth bug in v11/v12 for creator power levels. The event space script pins v10 for this reason.
- **AT&T Fiber** blocks Monero p2p — VPN required. Documented in [docs/MONERO_NODE.md](docs/MONERO_NODE.md).
- **Headscale on Tailscale clients** overrides `/etc/resolv.conf` on Pi #1 — local DNS entries require `/etc/hosts` overrides, not AdGuard. Documented in the status bot deploy note.
- **Reticulum config** must be validated against the installed version — the example configs in docs may require adjustment for your RNode firmware.

---

### Special Thanks

This project would not exist without the vision, community, and mission of three organizations that helped build the idea, necessity, and reasoning behind it:

- **[Carolina Capabilities Co-Op](https://www.carolinacapabilitiesco-op.com/)** — community resilience and preparedness, built from the ground up
- **[Light Fighter Manifesto](https://lightfightermanifesto.org/)** — the framework and philosophy driving the mission
- **[Light Fighter Homefront Initiative](https://lightfighterhomefront.org/)** — putting that mission into practice at the community level

The inspiration and architecture for this project couldn't have been done without the first iteration built by **Christopher M. Rance**. Go support the group or join a chapter — [instagram.com/christopher_m_rance](https://www.instagram.com/christopher_m_rance/)

---

### License

[CC BY-NC-SA 4.0](LICENSE) — build one for your community, adapt it, share it. You cannot sell it. Derivative works use the same license.

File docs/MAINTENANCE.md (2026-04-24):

# Maintenance Guide

Routine maintenance, service updates, and version management for the M2 Community Node.

---

## Version Philosophy

All Docker image versions are pinned in the `.env` files on each Pi. **Do not use `:latest`.** Uncontrolled updates have broken working configurations in the past — especially Conduit (Matrix homeserver) and OpenTAKServer, both of which have had breaking schema migrations between minor versions.

Update deliberately: read the upstream changelog, test in isolation if possible, update one service at a time.

---

## How to Update a Docker Service

The general pattern for any Docker service update:

```bash
# 1. Take a backup first (always)
cd /opt/community-node
tar czf ~/pre-update-backup-$(date +%Y%m%d).tar.gz config/ docker-compose.yml data/

# 2. Edit the version pin in .env
nano /opt/community-node/.env
# Change e.g. CONDUIT_VERSION=v0.10.12 to the new version

# 3. Pull the new image
docker compose pull <service-name>

# 4. Recreate the container
docker compose up -d <service-name>

# 5. Verify
docker compose ps
docker compose logs <service-name> --tail=50
```

If something breaks, roll back by reverting the `.env` version and re-running `docker compose up -d`.

---

## Service-Specific Notes

### Conduit (Matrix Homeserver)

Conduit stores its database in `/opt/community-node/data/conduit/`. Migrations run automatically on startup.

**Before updating:**
- Read the Conduit changelog at `https://conduit.rs/changelog`
- Check for any breaking changes to `conduit.toml` configuration keys
- Back up `data/conduit/` specifically — it contains the full Matrix database

**After updating:**
```bash
docker compose logs conduit --tail=100
```

Look for `Migration complete` or any `ERROR` lines. If Conduit exits immediately after an update, the logs will tell you whether it's a config key mismatch or a failed migration.

**Rollback:** Conduit does not support downgrade migrations. If a migration partially completes and fails, restore from the pre-update backup of `data/conduit/` before downgrading the image version.

---

### OpenTAKServer (OTS)

OTS runs as a native systemd service, not Docker. Updates use the OTS installer script.

**Before updating:**
```bash
# Dump the database
sudo -u postgres pg_dump opentakserver > ~/ots-db-backup-$(date +%Y%m%d).sql
```

**Update:**
```bash
# Download and run the OTS installer for the new version
# Check https://github.com/brian7704/OpenTAKServer for release instructions
# The installer handles service restarts and migrations
```

**After updating:**
```bash
sudo systemctl status opentakserver
sudo journalctl -u opentakserver -n 50
```

**Known issue:** After an OTS update, any client data packages (enrollment ZIPs) may need to be regenerated if the cert format or server metadata changed. Check the OTS web UI at `http://192.168.8.20:8080` and reissue enrollment packages if needed.

---

### Headscale

Headscale stores state in `/opt/tactical-node/data/headscale/`. Database migrations run automatically.

**Before updating:**
```bash
# Back up headscale state
cp -r /opt/tactical-node/data/headscale/ ~/headscale-backup-$(date +%Y%m%d)/
```

**After updating**, verify all nodes are still registered:
```bash
docker exec tactical-node-headscale-1 headscale nodes list
```

**Config file changes:** Headscale occasionally deprecates config keys between versions. If Headscale fails to start after an update, check `docker compose logs headscale` for `unknown field` or `deprecated key` errors and update `config/headscale/config.yaml` accordingly.

---

### Monero (monerod)

Monero requires periodic updates to stay on the correct hard fork version. Failure to update before a hard fork will cause the daemon to stop syncing.

**Check for upcoming hard forks:** Monitor `https://www.getmonero.org/resources/roadmap.html` and the Monero community channels.

**Update:**
```bash
# Edit the version pin in .env on Pi #2
nano /opt/tactical-node/.env
# Change MONEROD_VERSION to the new tag

docker compose pull monerod
docker compose up -d monerod
docker compose logs monerod --tail=50
```

Monero does not need a database migration — the blockchain data is forward-compatible. Downgrade is also safe as long as no hard fork boundary was crossed.

---

### Nginx

Nginx updates are low-risk. The config is fully templated and version changes rarely affect behavior.

```bash
# Update version in .env, pull, recreate
docker compose pull nginx
docker compose up -d nginx
```

Verify with `curl -I http://192.168.8.10:8080` — should return a 200 from Element.

---

### Cloudflared

Cloudflare updates the tunnel client frequently. The tunnel token is version-independent — updating only the binary.

```bash
docker compose pull cloudflared
docker compose up -d cloudflared
```

Verify the tunnel is active in the Cloudflare Zero Trust dashboard under **Networks → Tunnels**.

---

### AdGuard Home

AdGuard stores its config in `/opt/community-node/data/adguard/`. Config format is stable across versions.

```bash
docker compose pull adguard
docker compose up -d adguard
```

After updating, verify the DNS rewrites are still present: **AdGuard dashboard → Filters → DNS rewrites**. Rewrites are stored in `AdGuardHome.yaml` inside the data volume and survive updates, but verify before declaring success.

---

## OS and Security Updates

Both Pis run `unattended-upgrades` for security patches only (configured in Phase 3). This does NOT update Docker images or application software — only OS-level security fixes.

Manually check for and apply OS updates quarterly:

```bash
sudo apt update && sudo apt upgrade -y
```

Reboot after kernel updates:
```bash
sudo reboot
```

Allow ~3 minutes for full startup before checking services.

---

## Checking What's Outdated

To see if a pinned Docker image has a newer version available:

```bash
# Pull the latest for a given image tag to compare digests
docker pull matrixconduit/matrix-conduit:v0.10.12
# If "Image is up to date" — you have the latest of that pin
# Check upstream release page for newer version tags
```

For a full inventory of what's running:

```bash
# On Pi #1
docker compose ps --format "table {{.Name}}\t{{.Image}}\t{{.Status}}"

# On Pi #2
docker compose ps --format "table {{.Name}}\t{{.Image}}\t{{.Status}}"
```

---

## Log Rotation

Docker logs are managed by the default JSON log driver. On a long-running node, logs can accumulate. Add log limits to `docker-compose.yml` services if disk becomes a concern:

```yaml
    logging:
      driver: "json-file"
      options:
        max-size: "50m"
        max-file: "3"
```

Check current log sizes:

```bash
du -sh /var/lib/docker/containers/*/
```

---

## Credential Rotation

| Credential | Rotation approach |
|---|---|
| Headscale auth keys | Expire automatically — generate new keys in Headscale dashboard before old ones expire |
| Cloudflare API tokens | Rotate in Cloudflare dashboard; update `M2_SECRETS.md` and re-export to `.env` |
| Matrix bot token | Regenerate via Element (log out/in the bot account); update `M2_SECRETS.md` |
| OTS admin password | Admin > Users > administrator > change password (not via Profile) |
| Monero wallet RPC password | Update in systemd unit file, restart `monero-wallet-rpc` |

After rotating any credential: update `M2_SECRETS.md` locally and your encrypted backup copy.

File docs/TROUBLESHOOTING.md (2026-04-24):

# M2 Community Node — Troubleshooting

Organized by symptom. Every entry here was either experienced during the reference build or identified as a high-probability failure mode.

---

## WiFi / Network

### WiFi clients can't reach the Pis after changing router settings

**Symptom:** Phones connect to WiFi but can't load the community page or reach any Pi service. Wired devices work fine.

**Cause:** GL.iNet firmware silently sets `ap_isolate=1` after any WiFi configuration change. This blocks WiFi clients from reaching wired devices (the Pis) even on the same subnet.

**Fix:**
```bash
ssh root@192.168.8.1
hostapd_cli -i wlan0 set ap_isolate 0
hostapd_cli -i wlan1 set ap_isolate 0
```

If you have a boot script that applies this fix, verify it ran:
```bash
logread | grep ap_isolate
```

**Note:** This fix does not survive a router reboot unless applied via a scheduled script. The reference build runs this fix at 15s and 30s after boot via a cron job on the router.

---

### Devices won't connect after power cycle — wait 60 seconds

**Symptom:** Just power-cycled the rack. Nothing works. Phones can't connect.

**Cause:** The router takes 30-45 seconds to fully boot and apply all scripts. The AP isolation fix scripts run at 15s and 30s — if the router hasn't fully initialized, they fail silently.

**Fix:** Wait 60 seconds after power-on before testing. Then test from a wired device first, then WiFi.

---

### Can't get static DHCP leases before first boot

**Symptom:** Trying to assign fixed IPs (192.168.8.10 and 192.168.8.20) to the Pis before they've booted.

**Cause:** You need the Pi's MAC address to create a static lease, but the Pi hasn't booted yet to reveal its MAC.

**Fix:** Boot both Pis on DHCP first. Find their assigned IPs in the router's connected devices list. Note their MAC addresses. Then create static leases and reboot the Pis.

---

### DHCP range conflicts with static IPs

**Symptom:** Router assigns 192.168.8.10 or 192.168.8.20 to a random device.

**Fix:** Set the DHCP range to start above your static IPs. Example: static leases at .10 and .20, DHCP range starts at .100.

---

## Docker / Services (Pi #1)

### `docker compose up` fails with missing variable error

**Symptom:** Error like `variable CLOUDFLARE_TUNNEL_TOKEN is not set`

**Cause:** `.env` file missing or incomplete. Docker Compose requires all variables referenced in the compose file to be defined.

**Fix:**
```bash
cd /opt/community-node
ls -la .env    # verify it exists
cat .env       # verify all variables are populated
```

Create from the template if missing:
```bash
cp .env.template .env
nano .env      # fill in all values
```

---

### Conduit (Matrix) won't start — SSL certificate error

**Symptom:** `docker logs conduit` shows certificate errors. Matrix client can't connect.

**Cause:** SSL certificates either don't exist yet or are expired.

**Fix:**
```bash
certbot renew --dry-run    # test renewal
certbot renew              # renew if dry-run succeeds
docker compose restart nginx conduit
```

Verify cert is valid:
```bash
openssl s_client -connect matrix.yourdomain.com:443 </dev/null 2>&1 | grep "Verify return code"
```
Expected: `Verify return code: 0 (ok)`

---

### Conduit admin room commands don't work

**Symptom:** Commands sent to `@conduit:yourdomain.com` are ignored or return errors.

**Cause 1:** The admin room is encrypted. Conduit's admin bot cannot participate in E2EE rooms.

**Fix:** Create a new unencrypted room and invite `@conduit:yourdomain.com`. Use only that room for admin commands.

**Cause 2:** You're not using the admin account. Only the first registered user (admin) has control.

---

### Element Web loads but can't log in

**Symptom:** Element Web loads the login screen but authentication fails.

**Cause 1:** Homeserver URL is wrong. Element is configured to point to `matrix.yourdomain.com` but you're accessing it from a LAN IP.

**Fix:** Verify `element-config.json` has the correct homeserver URL for your deployment. On LAN, the homeserver is `http://192.168.8.10:6167` or the LAN-accessible Matrix URL.

**Cause 2:** Conduit is not running.
```bash
docker compose ps    # check conduit status
docker logs conduit  # check for errors
```

---

### Cloudflare tunnel is not routing traffic

**Symptom:** External domain (element.yourdomain.com) returns 502 or times out.

**Fix:**
```bash
docker logs cloudflared    # look for connection errors
```

If tunnel shows disconnected:
```bash
docker compose restart cloudflared
```

Verify the tunnel token in `.env` matches the token in Cloudflare Zero Trust > Networks > Tunnels.

---

### AdGuard Home blocks internal services

**Symptom:** After enabling AdGuard, node services stop resolving by hostname.

**Fix:** Add custom DNS rewrites in AdGuard Home (Settings > DNS Rewrites) for your local services:
```
matrix.yourdomain.com → 192.168.8.10
element.yourdomain.com → 192.168.8.10
```
This ensures local resolution goes to the Pi instead of the external IP.

---

## ATAK

### ATAK can't connect to OpenTAK Server — connection refused

**Symptom:** ATAK shows "Connection failed" or times out when trying to reach the server.

**Check 1:** Is OTS running?
```bash
ssh pi@192.168.8.20
sudo systemctl status opentakserver
```

**Check 2:** Is ATAK using the right IP and port?
- IP: `192.168.8.20`
- SSL port: `8089`
- TCP port (insecure): `8088`

**Check 3:** Is the device on the CommunityNode WiFi? ATAK over LAN only works when on the same network as the node.

**Check 4:** For remote access via VPN — is the device connected to Headscale? Check in Headscale admin or run `tailscale status` on the device.

---

### ATAK manual enrollment fails — truststore password rejected

**Symptom:** ATAK asks for truststore password during manual setup and rejects the entered value.

**Default password:** `atakatak`

If you changed this during OTS installation, retrieve it from your secrets file. There is no way to recover the truststore password other than from your records — if lost, you must regenerate the truststore in OTS and re-enroll all clients.

**Where it's set:** OTS admin console > Certificate Enrollment > Truststore settings.

---

### ATAK positions stop updating / COT not flowing

**Symptom:** Team members are connected but positions don't update on the map.

**Diagnosis:**
```bash
ssh pi@192.168.8.20
sudo systemctl status opentakserver
sudo journalctl -u opentakserver -n 50
```

Look for: database connection errors, memory pressure, or COT parser failures.

**Common cause:** OTS PostgreSQL database ran out of space (Monero sync fills the NVMe, OTS shares it).

```bash
df -h    # check disk usage
```

If disk is full, the Monero node is the most likely culprit — prune the blockchain or add storage.

---

### Reporting strategy — positions update inconsistently

**Symptom:** Some team members show real-time positions, others are stale.

**Cause:** ATAK reporting mode defaults to "Dynamic" which only updates when the device moves. For event use, all EUDs should be set to "Consistent" (updates on a fixed interval regardless of movement).

**Fix (per device):** ATAK > Settings > Show All > Reporting Strategy > Consistent

This cannot be set server-side; each operator must change it on their device.

---

## Monero

### Monerod appears hung — no sync progress

**Symptom:** `monerod status` shows height that isn't increasing, or systemd says the service is running but blockchain is at 0%.

**Cause:** Monero blockchain sync takes 24-72 hours on a Pi. This is normal. Do not restart monerod during sync unless you have confirmed it is actually stuck (no disk activity for 30+ minutes).

**Check progress:**
```bash
ssh pi@192.168.8.20
sudo journalctl -u monerod -n 20
```

Look for lines like: `Synchronized 2500000/3264185, net hash 3.24 GH/s`

**If actually stuck:**
```bash
sudo systemctl stop monerod
rm /opt/monero/data/p2pstate.bin    # clears stale peer list
sudo systemctl start monerod
```

---

### Monero RPC returns authentication error

**Symptom:** Wallet software or status scripts get 401 from `192.168.8.20:18089`.

**Cause:** RPC digest credentials are wrong. The password is set in `monerod.conf` and must match what your wallet/script uses.

**Fix:** Check `monerod.conf` for `rpc-login=username:password`. Update your wallet config to match.

---

## Reticulum / Meshtastic

### RNode not initializing

**Symptom:** Reticulum shows no LoRa interface. `rnsd` logs show interface error.

**Check:** Is the LEFT Heltec V3 flashed with RNode firmware (not Meshtastic)?
```bash
rnodeconf /dev/ttyUSB0 --info
```

If it shows Meshtastic firmware, you have the devices swapped. LEFT = RNode, RIGHT = Meshtastic.

---

### Meshtastic not appearing in ATAK

**Symptom:** Meshtastic devices are visible in the Meshtastic app but don't show up in ATAK.

**Check:** Is the Meshtastic ATAK plugin installed and configured to point to the ATAK server at `192.168.8.20:8089`?

The plugin creates a local bridge between Meshtastic and ATAK. Without it, the two systems are independent.

---

## Tor / I2P

### .onion addresses not resolving

**Symptom:** Tor Browser can't reach `.onion` addresses for Element or Matrix.

**Check:** Is the Tor container running?
```bash
docker compose ps tor
docker logs tor
```

**Check:** Are the hidden service directories populated?
```bash
ls /opt/community-node/data/tor/
```
Each service should have a `hostname` file with the `.onion` address.

**Important:** If you delete the Tor data directory or lose `private_key` files, your `.onion` addresses change permanently. Back up the entire `data/tor/` directory.

---

## General Diagnostics

### Quick health check (run from field laptop or any SSH session)

```bash
# Pi #1 (comms)
ssh pi@192.168.8.10 'docker compose -f /opt/community-node/docker-compose.yml ps'

# Pi #2 (tactical)
ssh pi@192.168.8.20 'sudo systemctl status opentakserver monerod'

# Disk usage (both Pis)
ssh pi@192.168.8.10 'df -h /'
ssh pi@192.168.8.20 'df -h /'
```

### Service ports quick reference

| Service | Host | Port | Protocol |
|---|---|---|---|
| Element Web (LAN) | 192.168.8.10 | 8080 | HTTP |
| Community page | 192.168.8.10 | 8081 | HTTP |
| Matrix (Conduit) | 192.168.8.10 | 6167 | HTTP (internal) |
| Nginx / Matrix TLS | 192.168.8.10 | 443 | HTTPS |
| AdGuard Home | 192.168.8.10 | 3000 | HTTP |
| OTS web | 192.168.8.20 | 8080 | HTTP |
| OTS TCP (ATAK) | 192.168.8.20 | 8088 | TCP |
| OTS SSL (ATAK) | 192.168.8.20 | 8089 | TLS |
| OTS cert enroll | 192.168.8.20 | 8446 | HTTPS |
| ATAK enrollment page | 192.168.8.20 | 8447 | HTTPS |
| Mumble voice | 192.168.8.20 | 64738 | TCP/UDP |
| Monero RPC | 192.168.8.20 | 18089 | HTTP (localhost only — use Tailscale VPN) |
| Headscale | m2vpn.yourdomain.com | 443 | HTTPS (clearnet only) |
| GL.iNet admin | 192.168.8.1 | 80/443 | HTTP/HTTPS |

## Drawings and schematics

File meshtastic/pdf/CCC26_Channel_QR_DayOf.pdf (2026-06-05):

# CCC26 MESH — M2 COMMUNITY NODE

## FOR BYOD USERS

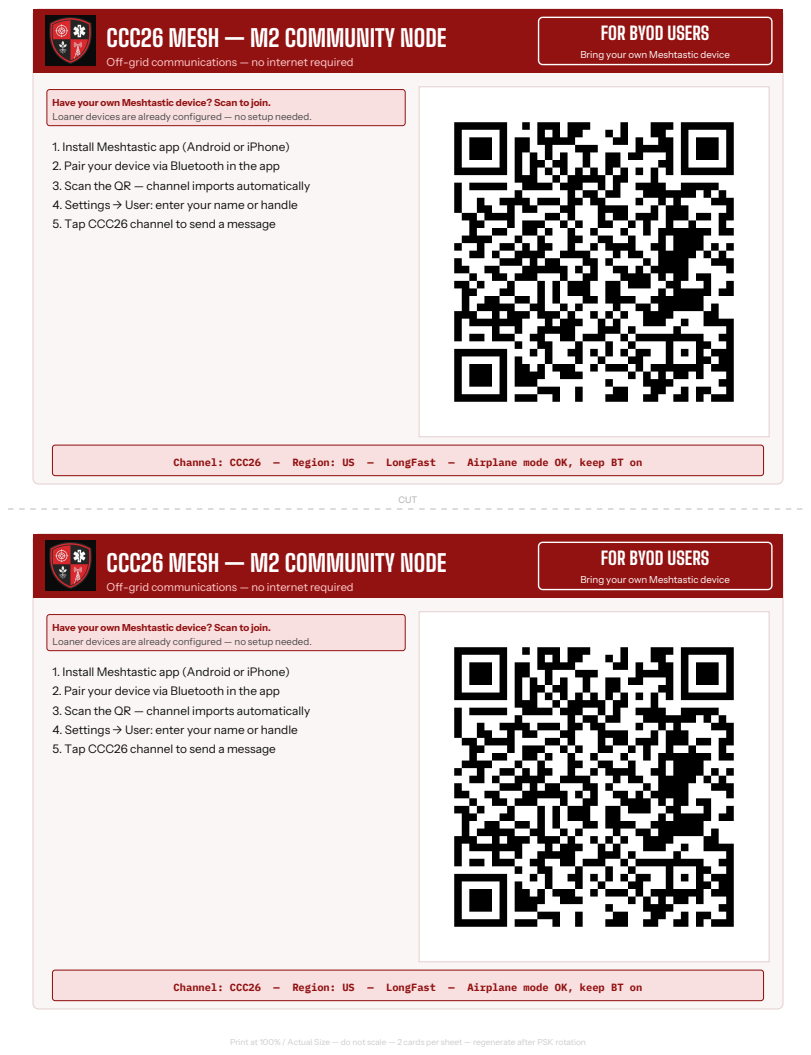
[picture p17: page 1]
CUT

Bring your own Meshtastic device

Off-grid communications — no internet required

Have your own Meshtastic device? Scan to join.
Loaner devices are already configured — no setup needed.

1. Install Meshtastic app (Android or iPhone)
2. Pair your device via Bluetooth in the app
3. Scan the QR — channel imports automatically
4. Settings → User: enter your name or handle
5. Tap CCC26 channel to send a message

Channel: CCC26 — Region: US — LongFast — Airplane mode OK, keep BT on

CCC26 MESH — M2 COMMUNITY NODE

FOR BYOD USERS

Print at 100% / Actual Size — do not scale — 2 cards per sheet — regenerate after PSK rotation

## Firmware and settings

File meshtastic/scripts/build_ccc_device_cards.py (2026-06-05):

"""
Generates CCC26 device sign-out and instruction cards.

Landscape 4"x6" cards — 2 per letter sheet, duplex short-edge flip for backs.
11 devices total: CCC fleet (MESH 01-08, T114) + personal (PS-01/02/03, T3S3).

Output:
  meshtastic/pdf/CCC26_DeviceCard_Front.pdf
  meshtastic/pdf/CCC26_DeviceCard_Back.pdf

Print at 100%, duplex short-edge flip. Cut on crop marks. Laminate.

Dependencies:
  pip install reportlab qrcode[pil]
  (run from project root — fonts in scripts/fonts/, assets in community-outreach/assets/)
"""

import sys
import os
import io

try:
    import qrcode
    from reportlab.pdfgen import canvas as rl_canvas
    from reportlab.lib.pagesizes import letter
    from reportlab.lib.colors import HexColor
    from reportlab.pdfbase import pdfmetrics
    from reportlab.pdfbase.ttfonts import TTFont
    from reportlab.lib.utils import ImageReader
except ImportError:
    print("ERROR: pip install reportlab qrcode[pil]")
    sys.exit(1)

_here   = os.path.dirname(os.path.abspath(__file__))
FONTS   = os.path.join(_here, "../../scripts/fonts")
ASSETS  = os.path.join(_here, "../../community-outreach/assets")
OUT_DIR = os.path.join(_here, "../pdf")

pdfmetrics.registerFont(TTFont("BigShoulders", os.path.join(FONTS, "BigShoulders-Bold.ttf")))
pdfmetrics.registerFont(TTFont("Mono",         os.path.join(FONTS, "IBMPlexMono-Regular.ttf")))
pdfmetrics.registerFont(TTFont("MonoBold",     os.path.join(FONTS, "IBMPlexMono-Bold.ttf")))
pdfmetrics.registerFont(TTFont("Sans",         os.path.join(FONTS, "InstrumentSans-Regular.ttf")))
pdfmetrics.registerFont(TTFont("SansBold",     os.path.join(FONTS, "InstrumentSans-Bold.ttf")))

ACCENT    = HexColor("#921212")
DARK      = HexColor("#0f0f0f")
MUTED     = HexColor("#4a4a4a")
WHITE     = HexColor("#ffffff")
CARD_BG   = HexColor("#faf6f6")
CARD_BRD  = HexColor("#e4d0d0")
LIGHT_ACC = HexColor("#f9e0e0")

# Landscape 4"x6"
CARD_W = 6 * 72   # 432 pt
CARD_H = 4 * 72   # 288 pt

DEVICES = [
    ("01", "MESH 01", "T114 — Loaner"),
    ("02", "MESH 02", "T114 — Loaner"),
    ("03", "MESH 03", "T114 — Loaner"),
    ("04", "MESH 04", "T114 — Loaner"),
    ("05", "MESH 05", "T114 — Loaner"),
    ("06", "MESH 06", "T114 — Loaner"),
    ("07", "MESH 07", "T114 — Loaner"),
    ("08", "MESH 08", "T114 — Loaner"),
    ("PS-01", "PS-01", "T3S3 — Personal"),
    ("PS-02", "PS-02", "T3S3 — Personal"),
    ("PS-03", "PS-03", "T3S3 — Personal"),
]

ANDROID_QR_URL = "https://play.google.com/store/apps/details?id=com.geeksville.mesh"
IPHONE_QR_URL  = "https://apps.apple.com/us/app/meshtastic/id1586432531"


def make_qr(url):
    qr = qrcode.QRCode(version=None,
                       error_correction=qrcode.constants.ERROR_CORRECT_M,
                       box_size=4, border=2)
    qr.add_data(url)
    qr.make(fit=True)
    img = qr.make_image(fill_color="black", back_color="white")
    buf = io.BytesIO()
    img.save(buf, format="PNG")
    buf.seek(0)
    return ImageReader(buf)


def draw_crop_marks(c, x, y, w, h, tick=8):
    c.setStrokeColor(HexColor("#aaaaaa"))
    c.setLineWidth(0.25)
    for cx, cy in [(x, y), (x+w, y), (x, y+h), (x+w, y+h)]:
        dx = tick if cx == x else -tick
        dy = tick if cy == y else -tick
        c.line(cx, cy, cx + dx, cy)
        c.line(cx, cy, cx, cy + dy)


def draw_front(c, x, y, num, long_name, type_label, android_qr, iphone_qr, logo_path):
    # Background
    c.setFillColor(CARD_BG)
    c.setStrokeColor(CARD_BRD)
    c.setLineWidth(0.5)
    c.rect(x, y, CARD_W, CARD_H, fill=1, stroke=1)

    # Header — full width, 38pt
    hdr_h = 38
    c.setFillColor(ACCENT)
    c.rect(x, y + CARD_H - hdr_h, CARD_W, hdr_h, fill=1, stroke=0)

    # Logo in header
    if os.path.exists(logo_path):
        c.drawImage(logo_path, x + 8, y + CARD_H - hdr_h + 3,
                    32, 32, preserveAspectRatio=True)

    # Header title
    c.setFont("BigShoulders", 15)
    c.setFillColor(WHITE)
    c.drawString(x + 46, y + CARD_H - 22, "CCC26 MESH DEVICE")
    c.setFont("Sans", 7)
    c.setFillColor(HexColor("#ffcccc"))
    c.drawString(x + 46, y + CARD_H - 34, f"{long_name}  —  {type_label}")

    # Device number badge — right side of header
    badge_r = 16
    badge_cx = x + CARD_W - badge_r - 8
    badge_cy = y + CARD_H - hdr_h / 2
    c.setFillColor(WHITE)
    c.circle(badge_cx, badge_cy, badge_r, fill=1, stroke=0)
    font_sz = 13 if len(num) <= 2 else 9
    c.setFont("BigShoulders", font_sz)
    c.setFillColor(ACCENT)
    c.drawCentredString(badge_cx, badge_cy - font_sz * 0.37, num)

    # Content area — two columns below header
    content_y_top = y + CARD_H - hdr_h - 6
    sign_h        = 38
    content_y_bot = y + sign_h + 4

    # Left column: HOW TO USE steps
    col_split = x + CARD_W * 0.55
    c.setFont("SansBold", 6.5)
    c.setFillColor(ACCENT)
    c.drawString(x + 10, content_y_top - 2, "HOW TO USE")
    c.setStrokeColor(ACCENT)
    c.setLineWidth(0.4)
    c.line(x + 10, content_y_top - 4, x + 10 + 50, content_y_top - 4)

    steps = [
        "1. This device is pre-configured. Pick up and go.",
        "2. Enable Bluetooth on your phone",
        "3. Open Meshtastic app — pair this device",
        "4. Settings → User: enter your name",
        "5. Tap CCC26 channel to send messages",
    ]
    step_y = content_y_top - 16
    for step in steps:
        c.setFont("Sans", 7)
        c.setFillColor(DARK)
        c.drawString(x + 10, step_y, step)
        step_y -= 11

    # Right column: GET THE APP
    qr_col_x = col_split + 6
    c.setFont("SansBold", 6.5)
    c.setFillColor(ACCENT)
    c.drawString(qr_col_x, content_y_top - 2, "GET THE APP")
    c.setStrokeColor(ACCENT)
    c.setLineWidth(0.4)
    c.line(qr_col_x, content_y_top - 4, qr_col_x + 50, content_y_top - 4)

    qr_sz      = 46
    qr_top     = content_y_top - 14
    android_x  = qr_col_x
    iphone_x   = qr_col_x + qr_sz + 18

    c.setFillColor(WHITE)
    c.rect(android_x - 2, qr_top - qr_sz - 2, qr_sz + 4, qr_sz + 4, fill=1, stroke=0)
    c.drawImage(android_qr, android_x, qr_top - qr_sz, qr_sz, qr_sz)
    c.setFont("Sans", 6)
    c.setFillColor(MUTED)
    c.drawCentredString(android_x + qr_sz / 2, qr_top - qr_sz - 9, "Android")

    c.setFillColor(WHITE)
    c.rect(iphone_x - 2, qr_top - qr_sz - 2, qr_sz + 4, qr_sz + 4, fill=1, stroke=0)
    c.drawImage(iphone_qr, iphone_x, qr_top - qr_sz, qr_sz, qr_sz)
    c.setFont("Sans", 6)
    c.setFillColor(MUTED)
    c.drawCentredString(iphone_x + qr_sz / 2, qr_top - qr_sz - 9, "iPhone")

    # Sign-out strip
    c.setFillColor(LIGHT_ACC)
    c.setStrokeColor(CARD_BRD)
    c.setLineWidth(0.5)
    c.rect(x + 4, y + 2, CARD_W - 8, sign_h, fill=1, stroke=1)
    c.setFont("SansBold", 6.5)
    c.setFillColor(ACCENT)
    c.drawString(x + 10, y + sign_h - 9, f"DEVICE {num} SIGN-OUT")
    c.setFont("Sans", 6.5)
    c.setFillColor(DARK)
    c.drawString(x + 10, y + sign_h - 20, "Borrower: ______________________________")
    c.drawString(x + 10, y + sign_h - 30, "Signature: _____________________________")


def draw_back(c, x, y, num, logo_path):
    # Dark background
    c.setFillColor(DARK)
    c.rect(x, y, CARD_W, CARD_H, fill=1, stroke=0)

    # Horizontal line texture
    c.setStrokeColor(HexColor("#1e1e1e"))
    c.setLineWidth(0.3)
    for line_y in range(int(y), int(y + CARD_H), 8):
        c.line(x, line_y, x + CARD_W, line_y)

    # Accent border
    c.setStrokeColor(ACCENT)
    c.setLineWidth(2)
    c.rect(x + 4, y + 4, CARD_W - 8, CARD_H - 8, fill=0, stroke=1)

    # Logo
    logo_sz = 32
    if os.path.exists(logo_path):
        c.drawImage(logo_path, x + 18, y + CARD_H / 2 - logo_sz / 2,
                    logo_sz, logo_sz, preserveAspectRatio=True)

    # Title block (centered in remaining space)
    cx = x + logo_sz + 40 + (CARD_W - logo_sz - 40) / 2

    c.setFont("BigShoulders", 22)
    c.setFillColor(WHITE)
    c.drawCentredString(cx, y + CARD_H / 2 + 20, "CCC26")
    c.setFont("Sans", 9)
    c.setFillColor(ACCENT)
    c.drawCentredString(cx, y + CARD_H / 2 + 6, "MESH DEVICE")

    # Device number circle
    circle_r  = 38
    circle_cx = cx
    circle_cy = y + CARD_H / 2 - 28
    c.setFillColor(ACCENT)
    c.circle(circle_cx, circle_cy, circle_r, fill=1, stroke=0)
    c.setFillColor(WHITE)
    c.circle(circle_cx, circle_cy, circle_r - 2, fill=0, stroke=1)
    c.setLineWidth(1)
    font_sz = 36 if len(num) <= 2 else 22
    c.setFont("BigShoulders", font_sz)
    c.setFillColor(WHITE)
    c.drawCentredString(circle_cx, circle_cy - font_sz * 0.35, num)

    # Footer
    c.setFont("Sans", 6.5)
    c.setFillColor(MUTED)
    c.drawCentredString(x + CARD_W / 2, y + 18, "CCC26 — M2 Community Node — Off-Grid Event Communications")
    c.setFont("Sans", 6)
    c.setFillColor(HexColor("#555555"))
    c.drawCentredString(x + CARD_W / 2, y + 9, "Return to operator after event")


def main():
    logo_path  = os.path.join(ASSETS, "lfhi-logo.png")
    android_qr = make_qr(ANDROID_QR_URL)
    iphone_qr  = make_qr(IPHONE_QR_URL)
    os.makedirs(OUT_DIR, exist_ok=True)

    W, H   = letter                          # 612 x 792
    MARGIN = 72                              # 1" margins top/bottom
    card_x = (W - CARD_W) / 2              # centered horizontally

    start_y_top = H - MARGIN - CARD_H       # 792 - 72 - 288 = 432
    start_y_bot = MARGIN                     # 72

    pairs = [DEVICES[i:i+2] for i in range(0, len(DEVICES), 2)]

    # ── FRONT ────────────────────────────────────────────────────────────────
    front_path = os.path.join(OUT_DIR, "CCC26_DeviceCard_Front.pdf")
    c = rl_canvas.Canvas(front_path, pagesize=letter)

    for pair in pairs:
        num, long_name, type_label = pair[0]
        draw_front(c, card_x, start_y_top, num, long_name, type_label,
                   android_qr, iphone_qr, logo_path)
        draw_crop_marks(c, card_x, start_y_top, CARD_W, CARD_H)

        if len(pair) > 1:
            num, long_name, type_label = pair[1]
            draw_front(c, card_x, start_y_bot, num, long_name, type_label,
                       android_qr, iphone_qr, logo_path)
            draw_crop_marks(c, card_x, start_y_bot, CARD_W, CARD_H)

        # Cut line between cards
        c.setStrokeColor(HexColor("#cccccc"))
        c.setLineWidth(0.4)
        c.setDash(4, 4)
        cut_y = (start_y_top + start_y_bot + CARD_H) / 2
        c.line(MARGIN / 2, cut_y, W - MARGIN / 2, cut_y)
        c.setDash()
        c.setFont("Sans", 6)
        c.setFillColor(HexColor("#bbbbbb"))
        c.drawCentredString(W / 2, cut_y + 3, "CUT")

        c.setFont("Sans", 5.5)
        c.setFillColor(HexColor("#cccccc"))
        c.drawCentredString(W / 2, 8,
            "CCC26 Device Cards — Print at 100% — Duplex short-edge flip for backs")
        c.showPage()

    c.save()
    print(f"Front saved: {os.path.abspath(front_path)}")

    # ── BACK (short-edge flip: top slot → bottom position) ───────────────────
    back_path = os.path.join(OUT_DIR, "CCC26_DeviceCard_Back.pdf")
    c = rl_canvas.Canvas(back_path, pagesize=letter)

    for pair in pairs:
        num, _, _ = pair[0]
        draw_back(c, card_x, start_y_bot, num, logo_path)
        draw_crop_marks(c, card_x, start_y_bot, CARD_W, CARD_H)

        if len(pair) > 1:
            num, _, _ = pair[1]
            draw_back(c, card_x, start_y_top, num, logo_path)
            draw_crop_marks(c, card_x, start_y_top, CARD_W, CARD_H)

        c.setStrokeColor(HexColor("#333333"))
        c.setLineWidth(0.4)
        c.setDash(4, 4)
        cut_y = (start_y_top + start_y_bot + CARD_H) / 2
        c.line(MARGIN / 2, cut_y, W - MARGIN / 2, cut_y)
        c.setDash()
        c.showPage()

    c.save()
    print(f"Back saved:  {os.path.abspath(back_path)}")
    print()
    print("Print instructions:")
    print("  1. Print CCC26_DeviceCard_Front.pdf (side 1)")
    print("  2. Reload — flip on SHORT edge")
    print("  3. Print CCC26_DeviceCard_Back.pdf (side 2)")
    print("  4. Cut on crop marks. Laminate.")
    print(f"  {len(DEVICES)} devices — {len(pairs)} sheets front+back")


if __name__ == "__main__":
    main()

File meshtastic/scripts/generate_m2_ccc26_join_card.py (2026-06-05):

#!/usr/bin/env python3
"""
M2 Community Node — CCC26 Element Chat Room Join Card
4" x 6" landscape @ 300 DPI  |  2 cards per sheet

Two QR codes per card:
  LEFT  — Join the M2 server (create account or log in)
  RIGHT — Join the CCC26 event space (E2EE encrypted, any Matrix account)

Output: operational-pdfs/M2_CCC26_Element_JoinCard.pdf
"""
from PIL import Image, ImageDraw, ImageFont
import qrcode, io, os

DPI    = 300
CW, CH = int(6 * DPI), int(4 * DPI)     # 1800 x 1200
PW, PH = int(8.5 * DPI), int(11 * DPI)  # 2550 x 3300

CARD_X   = (PW - CW) // 2
CARD_GAP = int(0.5 * DPI)
CARD_Y1  = (PH - 2 * CH - CARD_GAP) // 2
CARD_Y2  = CARD_Y1 + CH + CARD_GAP

ACCENT   = (146,  18,  18)
ACCENT_D = (100,  10,  10)
ACCENT_L = (255, 200, 200)
DARK     = ( 15,  15,  15)
WHITE    = (255, 255, 255)
MUTED    = (110, 110, 110)
CARD_BG  = (250, 246, 246)
RULE     = (228, 208, 208)
DIVIDER  = (210, 185, 185)
MARK_COL = ( 35,  35,  35)
STEP_BG  = (240, 225, 225)

SERVER_URL = "https://communitynode.capableenough.org"
ROOM_URL   = "https://matrix.to/#/#m2-ccc26-general:m2.capableenough.org"

_script_dir = os.path.dirname(os.path.abspath(__file__))
FONTS       = os.path.join(_script_dir, "../../scripts/fonts")
ASSETS      = os.path.join(_script_dir, "../../community-outreach/assets")
LOGO_PATH   = os.path.join(ASSETS, "lfhi-logo.png")
OUTPUT_DIR  = os.path.join(_script_dir, "../../operational-pdfs")


def ff(name, sz):
    path_map = {
        "bold":  os.path.join(FONTS, "BigShoulders-Bold.ttf"),
        "sans":  os.path.join(FONTS, "InstrumentSans-Regular.ttf"),
        "sbold": os.path.join(FONTS, "InstrumentSans-Bold.ttf"),
        "mono":  os.path.join(FONTS, "IBMPlexMono-Regular.ttf"),
    }
    try:
        return ImageFont.truetype(path_map[name], sz)
    except Exception:
        arial   = r"C:\Windows\Fonts\arial.ttf"
        arialbd = r"C:\Windows\Fonts\arialbd.ttf"
        return ImageFont.truetype(arialbd if name in ("bold", "sbold") else arial, sz)


def _logo(size):
    if os.path.exists(LOGO_PATH):
        return Image.open(LOGO_PATH).convert("RGBA").resize((size, size), Image.LANCZOS)
    return None


def make_qr(url, size):
    qr = qrcode.QRCode(version=None,
                       error_correction=qrcode.constants.ERROR_CORRECT_M,
                       box_size=10, border=2)
    qr.add_data(url)
    qr.make(fit=True)
    buf = io.BytesIO()
    qr.make_image(fill_color="black", back_color="white").save(buf, format="PNG")
    buf.seek(0)
    return Image.open(buf).convert("RGB").resize((size, size), Image.LANCZOS)


def draw_step_block(d, img, x, y, w, step_num, heading, lines, qr_img, qr_sz, note_lines=None):
    """Draw a numbered step block with heading, instruction lines, and QR code."""
    # Step number badge
    badge_r = 28
    badge_cx = x + badge_r + 8
    badge_cy = y + badge_r + 8
    d.ellipse([badge_cx - badge_r, badge_cy - badge_r,
               badge_cx + badge_r, badge_cy + badge_r], fill=ACCENT)
    d.text((badge_cx, badge_cy), step_num,
           font=ff("bold", 34), fill=WHITE, anchor="mm")

    # Heading
    d.text((badge_cx + badge_r + 14, y + 8), heading,
           font=ff("bold", 40), fill=ACCENT)

    # Divider line under heading
    line_y = y + 60
    d.line([(x + 8, line_y), (x + w - 8, line_y)], fill=DIVIDER, width=2)

    # Instruction lines
    text_y = line_y + 18
    for line in lines:
        d.text((x + 12, text_y), line, font=ff("sans", 28), fill=DARK)
        text_y += 40

    # QR code centered in remaining space
    qr_x = x + (w - qr_sz) // 2
    qr_y = text_y + 16
    pad = 12
    d.rectangle([qr_x - pad, qr_y - pad,
                 qr_x + qr_sz + pad, qr_y + qr_sz + pad],
                fill=WHITE, outline=RULE, width=2)
    img.paste(qr_img, (qr_x, qr_y))

    # Optional note lines below QR
    if note_lines:
        note_y = qr_y + qr_sz + pad + 44
        for note in note_lines:
            d.text((x + w // 2, note_y), note,
                   font=ff("sans", 23), fill=MUTED, anchor="mm")
            note_y += 38


def draw_join_card() -> Image.Image:
    img = Image.new("RGB", (CW, CH), CARD_BG)
    d   = ImageDraw.Draw(img)

    # Card border
    d.rectangle([0, 0, CW-1, CH-1], outline=RULE, width=2)
    d.rectangle([4, 4, CW-5, CH-5], outline=RULE, width=1)

    # ── Header ───────────────────────────────────────────────────────────────
    HDR_H = 100
    d.rectangle([0, 0, CW, HDR_H], fill=ACCENT)
    for hy in range(4, HDR_H - 2, 5):
        d.line([(0, hy), (CW, hy)], fill=ACCENT_D, width=1)

    logo = _logo(68)
    logo_x = 16
    if logo:
        img.paste(logo, (logo_x, (HDR_H - 68) // 2), logo)

    tx = logo_x + 68 + 16 if logo else 24
    d.text((tx, 12), "CCC26 ELEMENT CHAT ROOM",
           font=ff("bold", 58), fill=WHITE)
    d.text((tx, 70), "M2 Community Node  —  E2EE encrypted  —  any Matrix account works",
           font=ff("sans", 26), fill=ACCENT_L)

    # ── Footer ───────────────────────────────────────────────────────────────
    FOOT_H = 210
    FTR_Y  = CH - FOOT_H
    d.rectangle([0, FTR_Y, CW, CH], fill=DARK)
    d.line([(0, FTR_Y), (CW, FTR_Y)], fill=ACCENT, width=4)

    # Fixed y positions — each line is the center of the text (anchor="mm")
    d.text((CW // 2, FTR_Y + 28),
           "Already have a Matrix account?  Skip Step 1 — scan Step 2 directly.",
           font=ff("sbold", 30), fill=WHITE, anchor="mm")

    d.line([(80, FTR_Y + 50), (CW - 80, FTR_Y + 50)], fill=(70, 70, 70), width=1)

    d.text((CW // 2, FTR_Y + 80),
           "Manual:  Server → matrix.capableenough.org  |  Explore rooms → search #ccc26",
           font=ff("sbold", 28), fill=WHITE, anchor="mm")

    d.text((CW // 2, FTR_Y + 116),
           "Federated users: log in with your home server — Step 2 QR joins CCC26 directly.",
           font=ff("sans", 27), fill=WHITE, anchor="mm")

    d.text((CW // 2, FTR_Y + 152),
           "All CCC26 rooms are end-to-end encrypted (E2EE).",
           font=ff("sbold", 27), fill=ACCENT_L, anchor="mm")

    # ── Body ─────────────────────────────────────────────────────────────────
    BODY_Y   = HDR_H + 16
    BODY_BOT = FTR_Y - 12
    BODY_H   = BODY_BOT - BODY_Y

    # Vertical divider
    MID_X = CW // 2
    d.line([(MID_X, BODY_Y + 8), (MID_X, BODY_BOT - 8)],
           fill=DIVIDER, width=2)
    d.text((MID_X, BODY_Y + BODY_H // 2), "OR\nTHEN",
           font=ff("bold", 28), fill=DIVIDER, anchor="mm", align="center")

    # Column widths
    COL_W  = MID_X - 20
    QR_SZ  = 480
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

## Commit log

2026-04-24 feat: M2 Community Node v1.0.0 — initial public release
    Field-portable community communications node: complete build guide,
    service configs, operational PDFs, and automation scripts.
    Services: Conduit (Matrix/Element), OpenTAKServer (ATAK), Monero full
    node, Mumble, Headscale, AdGuard Home, Tor hidden services, kiosk UI.
    All instance-specific values (domain, credentials, Tor onion addresses,
    Linux username) replaced with documented placeholders. Builders configure
    via instance.conf + M2_SECRETS.md (gitignored).
    Special thanks: CCC, LFManifesto, LFHI, Christopher M. Rance.
    [1U Mini 2x Keystone 2x SMA Left Mount.stl, 1U Mini 2x Keystone 2x SMA Right Mount.stl, 2U_FanSide1.stl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]
2026-04-24 docs: add BUILD_OPTIONS.md — hardware alternatives and build tiers
    Covers Pi 5 8GB, Pi 4, x86_64 mini PCs, single-device builds,
    no-Monero variants, router/LoRa substitutions, and service
    dependency map. Cross-referenced in README, BOM, PREREQUISITES,
    and docs/README.
2026-04-25 fix: correct OS baseline RAM figures in BUILD_OPTIONS — headless Pi OS Lite is ~350-400MB, not 1.2GB; Pi #1 higher due to Sway+Chromium kiosk
2026-05-20 feat: add Meshtastic one-sheet for CCC/LFHI community outreach
    Playwright-based HTML→PDF build pipeline for a print-ready Meshtastic
    intro handout. LFHI branding, field/preparedness copy, inline device
    SVGs. Companion to the DSA Orlando version in a separate repo.
2026-06-01 feat: add Meshtastic T114 document system — 6 scripts, 5 print-ready PDFs, first PSK rotation
    Adds complete meshtastic/ subfolder with scripts/ and pdf/ layout.
    Two node types covered: Heltec V3 rack nodes (ROUTER) and Heltec T114
    field nodes x8 (CLIENT). Documents updated to reflect T114 UF2 flash
    process, dual-node hardware inventory, and M2-specific naming (MF-1 to MF-8).
    QR card gitignored — contains live PSK. PSK saved to M2_SECRETS.md.
2026-06-04 feat: add CCC26 Matrix join card — QR deep-links to event space
    Print-ready 4x6 card matching DeviceCard style (same palette, header,
    footer, dot-grid). QR encodes Element Web deep link to CCC26 space so
    attendees skip the manual room search after registering.
    [generate_m2_ccc26_join_card.py]
2026-06-04 fix: move CCC26 join card to operational-pdfs, update output path
    [generate_m2_ccc26_join_card.py]
2026-06-04 docs: add Phase 13 RF/security tools to field laptop setup
    Documents tshark, aircrack-ng, hashcat, Kismet, qFlipper, and dialout
    group — all installed on m2-field 2026-06-03.
2026-06-05 feat: CCC26 event prep — Meshtastic fleet scripts and Element join cards
    Add T114/T3S3 fleet configurators, BYOD channel QR card, loaner device
    cards, and a two-QR Element join card. Matrix well-known worker fixed
    to return m2-matrix.capableenough.org — enables m2.capableenough.org
    server discovery in native Element app. Room alias confirmed:
    #m2-ccc26-general:m2.capableenough.org.
    [build_ccc_device_cards.py, config_ccc_t114.py, config_ccc_t3s3.py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]
2026-06-05 docs: add ADMIN_URLS.md — clearnet reference for all admin interfaces
    Covers Cloudflare, M2 clearnet/LAN/Tor, M1 Homestead (planned), GitHub,
    Claude, Proton, Obsidian, Meshtastic, OTS/ATAK, Headscale, GoDaddy.
2026-06-05 chore: add remaining CCC26 print PDFs — device cards and channel QR
    Device loaner cards (front/back, 4x6 duplex) and BYOD channel QR card
    for the full 11-device T114/T3S3 fleet. All tested and ready to print.
2026-06-05 fix: correct headscale and tunnel health checks in status dashboard
    Headscale runs as systemd on Pi #2, not Docker — was checking docker ps
    names so it always showed red. Switched to systemctl is-active.
    DDNS check compared public IP to DNS record, but M2 uses Cloudflare
    Tunnel so they never match by design. Replaced with HTTP health check
    against m2vpn.capableenough.org/health.
    Peers count switched from docker exec into a container to running the
    headscale binary directly via sudo over SSH.
    Also removed unused socket import and fixed default SSH user (pi -> ps).
2026-06-05 docs: add POWER_CYCLE.md — field startup and shutdown runbook
    One-sheet reference for power on/off, boot verification, clean shutdown,
    and troubleshooting. Documents all failure modes found during 2026-06-05
    power cycle test including boot race fixes and dashboard gotchas.
2026-06-05 docs: add FIELD_PACKING_LIST.md — hardware checklist for field deployment
2026-06-05 docs: expand FIELD_PACKING_LIST to full maintenance and repair guide
    Adds spare parts table with failure coverage, recovery procedures for
    dead Pi, SD swap, Meshtastic reconfigure, and dashboard triage. Includes
    tools section and cross-references POWER_CYCLE.md.
2026-06-05 docs: specify micro-HDMI to HDMI cable for Pi 5 display
2026-06-13 fix: use IP-based URL for ATAK enrollment deep link
    atakenroll.capableenough.org is NXDOMAIN in public DNS (local-only
    AdGuard rewrite). WiFi clients who don't use AdGuard as DNS can't
    resolve it, so the tak:// deep link silently fails and enrollment
    never starts.
    Switch the deep link to http://192.168.8.20:8080/atak-connect.zip —
    the zip is already served by the OTS nginx on port 8080, no DNS needed.
    Also update the community page to replace the "ask the operator" step
    with a direct link to http://192.168.8.20:8080/atak-connect.html so
    users can self-enroll without operator intervention.
2026-10-26 fix: pin cloudflared 2026.10.3 for the eMudhra intermediate certificate compromise
